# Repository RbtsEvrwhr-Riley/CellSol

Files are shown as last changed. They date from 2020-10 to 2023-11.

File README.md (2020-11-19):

# CellSol
CellSol: Long Range Solar Powered Communications Network

## Firmware

There are two firmwares for CellSol pylons: the ESP32 firmware and the Arduino Nano firmware. The former is for the ESP32 WiFi Pylon, and the latter for the Arduino Repeater Pylon.

These can be found under ESP32/esp32_wifi_bt and nano/nano_one_serial_port respectively. We will also publish binaries on the website for major releases.

See the [CellSol website](https://www.f3.to/cellsol) for more information.

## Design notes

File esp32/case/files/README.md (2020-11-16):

Bigcase has a lot of extra room for things like a battery box.

Smallcase is just the Lora32 and a lipo.

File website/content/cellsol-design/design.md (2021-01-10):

---
publishdate: 2019-11-17
lastmod: 2020-11-24
---

CellSol Design

{{< toc >}}

# Rationale

We want to provide a last-mile mesh network to allow people to communicate and access knowledge in the event of a natural, social, or other disaster. Network infrastructure is intended to be inexpensive,
locally powered, and easy to build, maintain, and replace. It should be lightweight, and as interoperable as is feasible with other network technologies and the broader Internet.

# Design

Our network design utilizes a combination of "fixed pylons" (fixed repeaters) placed mostly on the rooftops and outside of buildings and "pocket pylons" (mobile repeaters that live in peoples' pockets 
and backpacks) to allow for more "hops" across the network. The pocket pylons will also provide wifi so that any wifi-enabled device can connect to the LoRa network and send and receive messages over it.

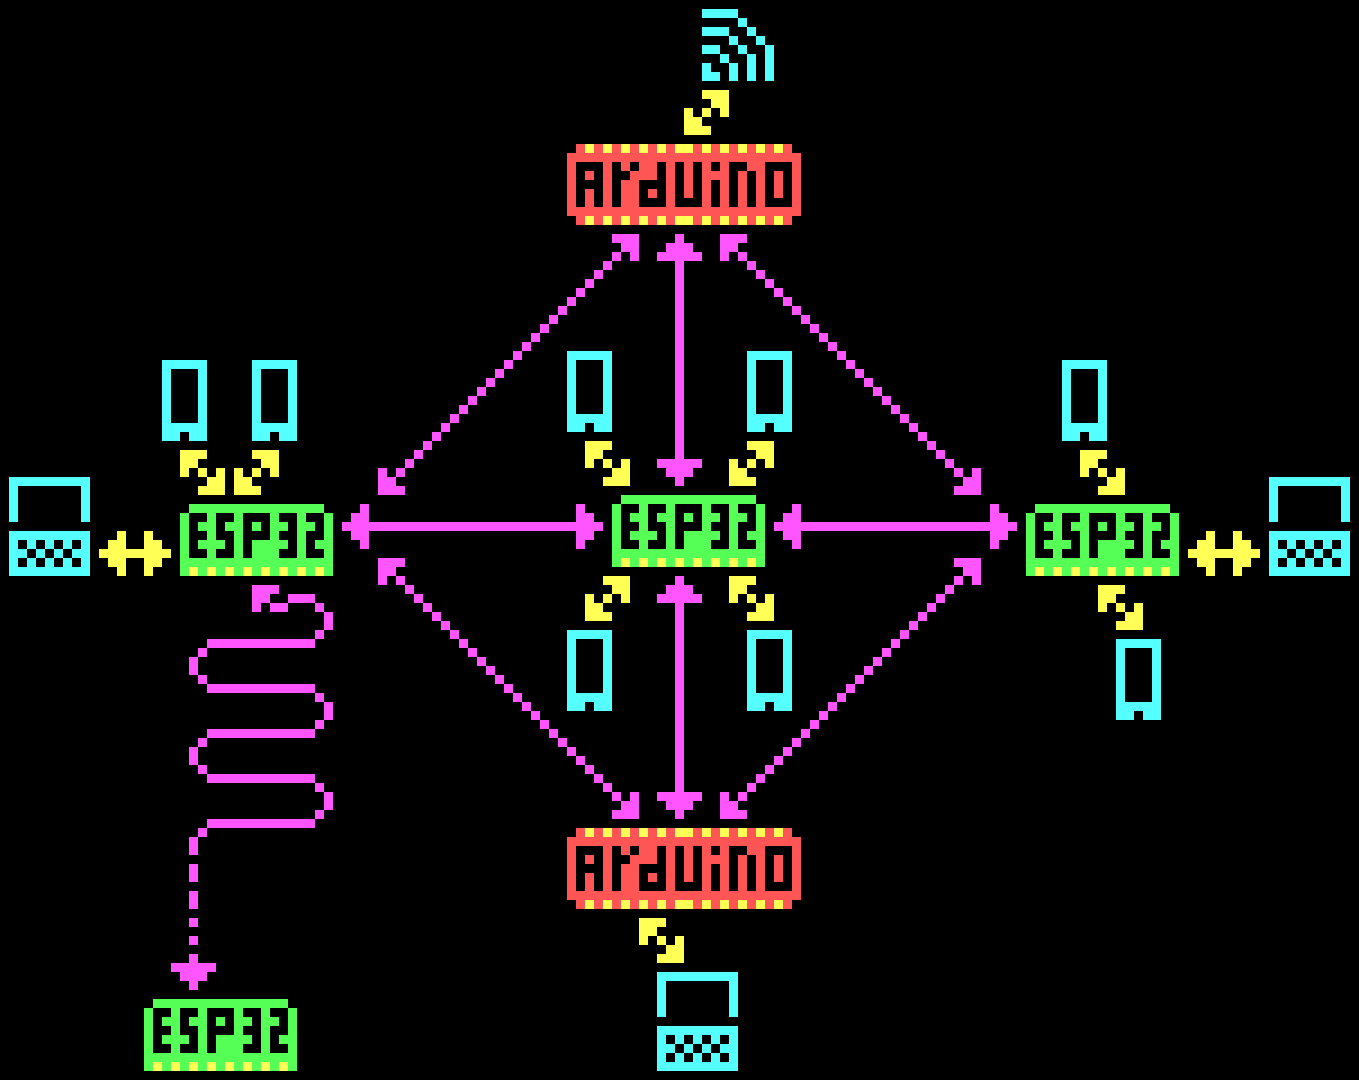
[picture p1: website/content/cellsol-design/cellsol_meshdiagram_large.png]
cellsol mesh network diagram


Our "pylons" are very simple devices that do one of three things:
1. Have a list of phones/computers that are connected to me directly; serve a web or bluetooth interface to that device to allow terminal communication
2. Send incoming messages to connected devices
3. Re-transmit incoming messages along the network

The above is true whether there ARE endpoints (phones, PCs, WiFi/Ethernet routers) connected to the node or not, so it can always be the same bit of hardware.

The "re-transmit" can be done in a basic mesh format (always re-transmit everything), and routing can be implemented in the future. Each node is capable of being a router,
if the packet format is adapted for more complex addressing in the future.

A node also provides a gateway from other devices (via BLE or WiFi) INTO and OUT OF the mesh network, and also provides routing WITHIN the mesh.

# Hardware

The RF standard we are using is [LoRa](https://www.semtech.com/lora/what-is-lora) which is an 866MHz (EU) and 915MHz (North America and most other regions) standard.

The hardware is deliberately as simple as possible so that it can be made out of readily available parts in the field. The most specialized components are for the radio - the Semtech Sx1276 and a 915MHz
antenna. That said, any LoRa chip will work, and monopole antennas can be made from short lengths of wire. See our [antennas page](../cellsol-equipment/antennas/).

The [Heltec Lora32](https://heltec.org/project/wifi-lora-32/) and Arduino Nano(https://www.arduino.cc/) are chosen for microcontrollers, due to their simplicity, with the LoRa32 being a fully integrated out-of-the-box LoRa device, so no soldering or significant setup is needed.

## Hardware Philosophy

For the different types of devices, identical hardware is used for the repeater/transmitter parts, whether you are making a WiFi pocket pylon, or a repeater, or a fixed pylon to place on top of a building,
using an ESP32, Arduino, or even a future design with a more powerful computer. The power systems are also designed to scale in the same way, with the same power supply options being interchangeable across the whole architecture.

Any device on the CellSol network is able to receive and rebroadcast messages.

The overall design is intentionally flexible so that users can design their own pylons and connect up to the devices shown here.

## WiFi Pylons 

[WiFi pylons](../cellsol-equipment/esp32), or "pocket pylons", are designed to be endpoints that connect to existing WiFi networks or devices. They can act as access points for wireless clients, or act as a client and connect to an
existing WiFi network, providing CellSol connectivity to all devices on that network. These use the Heltec Lora32 board at their core. These will serve a bulletin-board style chat application via http,
allowing any device with a web browser or ability to send GET requests to be able to talk to the rest of the mesh network.

## Repeater Pylons

[Repeater pylons](../cellsol-equipment/arduino) are a lower cost device that is designed to be a network extender, without providing web endpoint functionality. Bluetooth connectivity can be built onto
these, so they can also act as an endpoint for a single device, talking via Bluetooh serial port. These are designed around an Arduino and the Sx1276, and can be built for very low cost if done in large
volume runs. [Robots Everywhere](https://www.robots-everywhere.com) will be developing a kit for this model of pylon.

## Power requirements - Using a Solar Panel

Although users will want a battery connected to both pocket and fixed pylon repeaters, the battery will quickly run out if it is not supplemented by a solar panel that recharges the battery during the day. For this reason, we have integrated a solar panel into the design.

Note that, for the pocket pylons, it is more likely that you will want to use an additional battery or two to keep your pylon going over the course of the day, rather then depend on a solar panel being able to recharge it successfully while you are walking around. For fixed pylons however, especially those living on roof tops, a 5v solar panel will do quite nicely at keeping the battery charged.

These "pocket pylons" that we are building are able to use a 5v solar panel as-is. (5.6v is also within tolerances).

Remember to plug in your batteries and let them charge overnight the night before you assemble your repeaters. This will ensure that it's charged up as much as possible.

The way this works, is by placing the battery in-between the esp32 module and the solar panel, allowing the solar panel to keep the battery charged.

Note: Neither the ESP32 nor the Arduino is able to be powered directly from the panel, because solar panels don't collect at a constant voltage. So, if you purchased say, a 5 watt solar panel, it's really going to be collecting at 4.5 watts on some days and 5.6 watts on other days, but the devices that need to be powered require a consistent 5 watt stream.

# Software

We want to stay very light on software, focusing primarily on providing text over serial. End-to-end encryption can be handled client side by any specialized clients that want to use it, same for
compression. WiFi pylons will serve a simple web chat application, allowing for communication between users.

This is all in the future; the current software is a simple APK for Android phones to connect to Bluetooth-enabled Repeater Pylons. To communicate with
the WiFi Pylons, simply connect to their web interface, which is built into the firmware.

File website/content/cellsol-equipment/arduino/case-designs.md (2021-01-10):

---
publishdate: 2019-11-17
lastmod: 2020-11-24
---

Case designs for the Arduino Repeater Pylon are a work in progress.

https://www.thingiverse.com/thing:4660194 - This is our current case design. It has room for a small battery, and exposes the USB port.

These are not very weather resistant; we recommend using them for pocket pylons, or for indoor use, and applying a gasket and transparent screen protector film on the
exposed ports. Layer sealant, such as silicone paint or epoxy, may also help the weather resistance of this case. We recommend waterproof project boxes for outdoor use.

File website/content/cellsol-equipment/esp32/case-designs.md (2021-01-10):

---
publishdate: 2019-11-17
lastmod: 2020-11-24
---

We currently have two case designs for the ESP32 WiFi Pylon developed.

These are not very weather resistant; we recommend using them for pocket pylons, or for indoor use, and applying a gasket and transparent screen protector film on the
exposed ports. Layer sealant, such as silicone paint or epoxy, may also help the weather resistance of this case. We recommend waterproof project boxes for outdoor use.

https://www.thingiverse.com/thing:4660205 - Small case for just the LoRa32 and a battery

https://www.thingiverse.com/thing:4660207 - Large case that can take a bigger battery box, as well as have some room for instruments or other stuff

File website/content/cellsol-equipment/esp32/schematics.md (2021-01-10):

---
publishdate: 2019-11-17
lastmod: 2020-11-24
---

Here is a basic schematic for how to wire up the ESP32 Wifi Pylon using both a USB Power Bank and without.

If you are using a USB Power Bank, the battery can also be omitted if you choose.

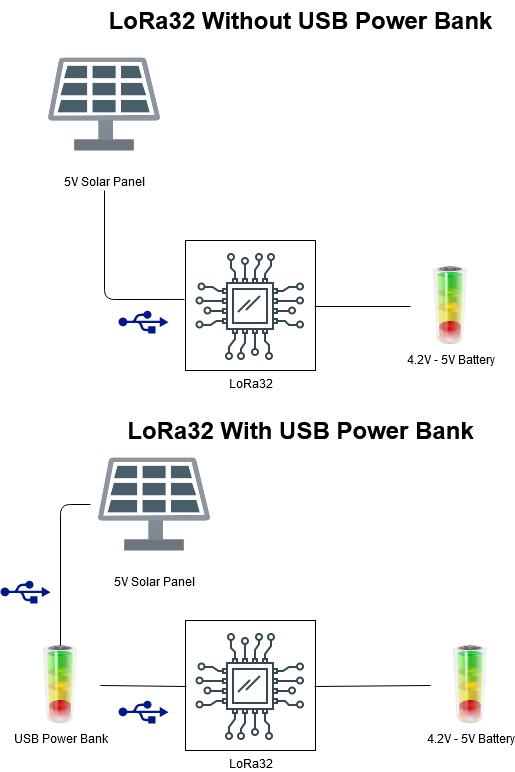
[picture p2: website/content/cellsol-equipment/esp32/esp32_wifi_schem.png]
Schematic of Wiring a Lora32 Into a CellSol Wifi Pylon


For more information, look at the [Lora32 Website](https://heltec.org/project/wifi-lora-32/) for documentation and datasheets.

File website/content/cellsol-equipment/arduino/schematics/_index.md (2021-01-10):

---
publishdate: 2019-11-17
lastmod: 2020-11-24
---

Full schematics and board layout files will be available on our GitHub page when the project is public.

<br />This work is licensed under a <a rel="license" href="http://creativecommons.org/licenses/by-nc-sa/4.0/">Creative Commons Attribution-NonCommercial-ShareAlike 4.0 International License</a>.

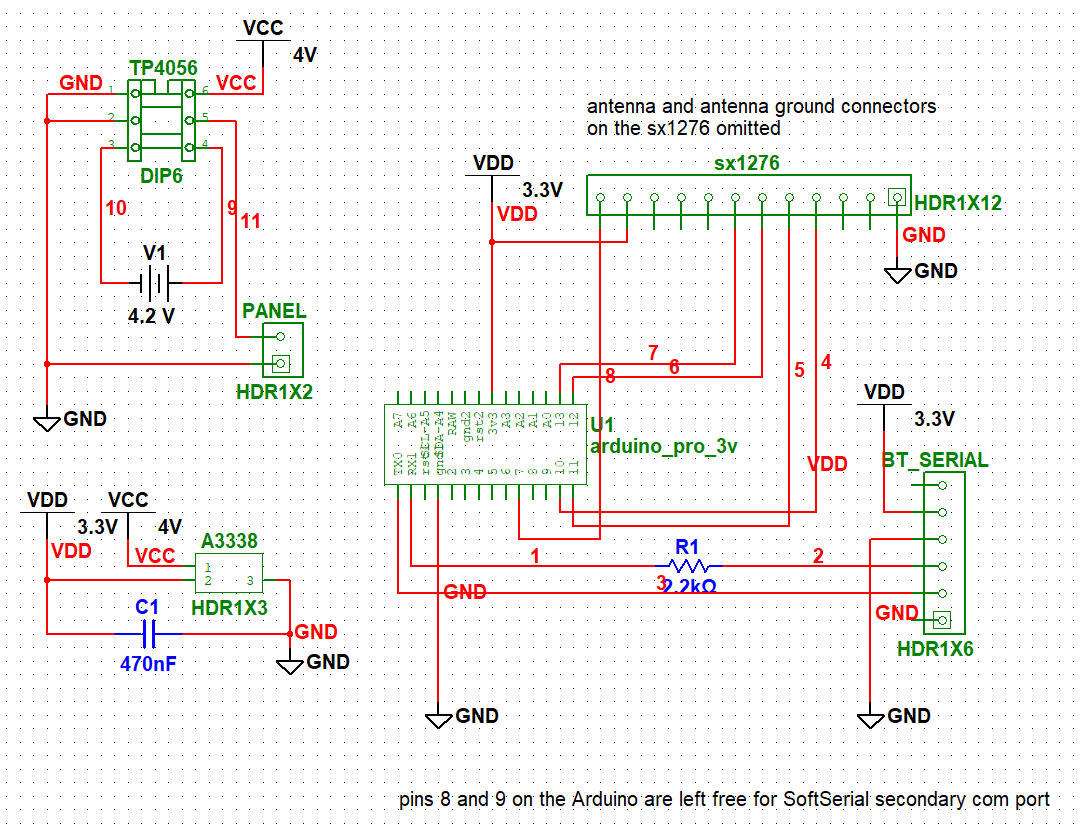
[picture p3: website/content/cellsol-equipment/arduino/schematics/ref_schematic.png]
Schematic for CellSol Arduino Repeater Pylon


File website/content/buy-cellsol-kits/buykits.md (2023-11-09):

---
title: Buy CellSol Kits
publishdate: 2021-01-11
lastmod: 2021-01-11
---

We aim to make it easy for you to build your own CellSol pylons and truly own your infrastructure. If you would like to purchase fully assembled or partially assembled kits, you can support the project by
purchasing them directly from Robots Everywhere. Head over to their [product page](https://www.robots-everywhere.com/store/cellsol-pylons-kits/) and choose your preferred pylon type. Robots Everywhere has done the engineering
and promotion work for CellSol, so by buying kits from them, you are supporting their contribution to the project.

# Compatible Equipment

You can search for the following boards on your favorite electronics retailer website.  You can then download the appropriate firmware from here, and flash it on the board.

* Heltec Lora32V2 ESP32 board
* Heltec Lora32V1 ESP32 board
* TTGO/LILYGO T-Beam
* TTGO/LILYGO ESP32 LoRa Dev Board
* BSFRANCE Feather32u4 LoRa board
* Adafruit Feather M0

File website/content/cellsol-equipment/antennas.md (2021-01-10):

---
title: Antennas
publishdate: 2019-11-17
lastmod: 2020-11-24
---

{{< toc >}}

# Antenna Concepts

If you're not familiar with antenna design, [this site](http://www.antenna-theory.com/) can be a good resource. You don't need to know any antenna theory to choose an antenna for your pylon,
but it's useful knowledge!

# Small Antennas (<10cm)

900MHz wifi antennas will often serve "okay" at both 866MHz for european LoRa and 915MHz for North American, but the performance in either case will be less than ideal.

Most of our data for LoRa antennas have come from the results of Mark Zachmann on his blog here: https://medium.com/home-wireless/testing-lora-antennas-at-915mhz-6d6b41ac8f1d

We have only been the 85mm copper wire and stock LoRa32 antennas ourselves so far. Please [reach out to us](mailto:cellsol@robots-everywhere.com) if you are testing other antennas! We would love
to hear from you, and see your network implementations.

## With a Ground Plane (Monopoles)

Monopole antennas will perform better than dipoles, but need a solid connection to earth ground to work effectively. For a static pylon, such as a repeater or a home
ESP32 WiFi pylon, you may have easy access to earth ground. REMEMBER: when connecting your pylon to a grounding stake, do not use a wire that is a multiple of 85mm in length,
it will resonate on the frequency you are trying to receive, making your ground less effective.

For a short-wire monopole antenna, 85mm of copper wire will work; our tests used standard 20 gauge stranded wire from our shop spools. 

REMINDER: the wire leading to the antenna is also an antenna, ensure it is either too short or more likely too long to resonate at 915MHz. If the antenna is near 8cm in length, it will reasonate, causing
a lot of noise, possibly disabling the connection entirely.

Linx makes a 915MHz monopole as well; https://linxtechnologies.com/wp/product/pw-series-antennas/ along with other manufacturers.

### 3D Printed Antenna Stand & Cutter

Kay designed a 3D printable antenna stand that also doubles as a ruler to measure the right length of wire to use for the best reception.

Our LoRa network uses 915MHz as its frequency. Different frequencies will use different lengths of wire on our antenna ruler/stand. 
You can use the ruler to measure exactly the right length of wire for your antenna, before you cut it.

1. Print out our antennae stand/ruler for frequency wire length tool

2. Use the tool to measure the desired length of wire for your antennae, and cut it

3. Slide the wire through the antennae stand

4. Connect the antennae to your LoRa repeater or Wifi Router

Be careful where you place your repeater, as the antenna itself can shadow the solar panel and interfere with it's ability to capture power from the sun.

## Without a Ground Plane (Dipoles)

When you do not have a ground plane you should be using a dipole antenna. The stock antenna on the Heltec and TTGO LoRa32s (and many other cheap LoRa antennas) are
actually WiFi antennas - tuned at 915MHz - with a broad frequency range. The 866MHz version is the same as the North American 915MHz one, so all models work in all regions.

One example of a high performance whip dipole for LoRa at 915MHz is here. https://linxtechnologies.com/wp/wp-content/uploads/ant-916-cw-hw.pdf They also make an 868MHz version.

If you are on the side of the building, use a directional reflector (aluminum) to improve performance, though the concrete of the building will do a fairly good job. Glass won't.

From our own calculations, large loop antennas are not worth it for 915MHz applications - diminishing returns on gain begin at very small loop diamters, around 8cm. We will continue further testing as the project goes on.

For a very tiny pocket node, small chip antennas exist:

https://www.mouser.ca/ProductDetail/Yageo/ANT1204F005R0915A?qs=gt1LBUVyoHnk%2Fihas5MohQ%3D%3D

https://linxtechnologies.com/wp/product/915-usp410-lpwa-antenna/ 

https://www.youtube.com/watch?v=eQEmFlMW50o This guide has some information on making your own LoRa dipole antennas using copper welding wire.

Otherwise, the stock dipole on the LoRa32 performs better than most 900MHz antennas at 916MHz.

# Large Antennas

We don't have any big-antenna deployments yet - we're working on securing funding to build some large pylons around the San Francisco Bay Area at the moment.

Depending on the region you are operating in and the regulation of the 915MHz or 866MHz band, the operation large transmitters may not be permitted. You may be
required to reduce the power of your transmission by modifying the firmware, or use a smaller antenna.

If you want to help, [contact us](mailto:cellsol@robots-everywhere.com)

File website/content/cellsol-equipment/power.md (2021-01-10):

---
title: Power Supplies
publishdate: 2019-11-17
lastmod: 2020-11-24
---

# POWERING THE NODE

The node is designed to be very tolerant when it comes to input power, so that it can be run in a variety of emergency situations.

The node takes 4 to 6.5V power. You can provide this from USB, a solar panel, or a number of other sources such as:

* USB power bank. It has to be plugged into the USB power input port. You can break down a USB cable to do this and connect the red and black wires.

* 6V lead-acid battery, connected to the USB power input port.

* 6V bike dynamo. Using a diode in series with the node power input is recommended (1N4004 or similar). If you use this, the node MUST have a secondary battery.

* 3 alkaline cells (AAA to D cells) in series. Important: these must be NON-rechargeable!

* Anything that outputs USB (car adapter, wall plug, spare USB port on a wifi router, 10 pounds of potatos connected in series, etc)

* USB hand crank. If you use this, the node MUST have a secondary battery.

## BATTERY TYPES FOR THE NODE

You will need a 3.5 to 4 volt battery to keep the node operating overnight (or when its primary power input is off). The node has been designed to be compatible with a variety of battery typologies. Any one of these will work. If you want to use more than one battery, connect them in parallel. In this case you may NOT mix battery types!

* None. The node has a two stage voltage regulator (switching to 3.7v and linear to 3.3v) and a filter capacitor, so it's safe to run it without a battery if it has continuous power coming in. The exception, as noted above, is if you have a USB hand crank or bike dynamo.

* 3.7V LiPo battery. Any type is fine (18650, old quadcopter battery, etc). If it has no protection circuit, it's fine.

* 3.6V lithium battery. Any type is fine (Old cell phone battery, etc).

* 3 rechargeable cells (AAA to D cells) in series. Important: these must be rechargeable!

* 4V lead-acid battery, connected to the battery terminals. Optionally, add a 47 ohm resistor between solar in+ and battery in+. (Note that this also applies to a 6V lead-acid battery that has a dead cell: the node uses little continuous power, so this is safe to do! Good for emergencies.)

* A supercapacitor (if you want to show off) A 5V supercap will work just fine as if it was a battery. Warning: A 3.3V supercap will NOT! If you have one of those, connect it between 3V3 and GND.

* If all you have available is a 3.3V LiFePo4 cell, you can still use it if you connect a capacitor to the battery terminals, and connect the battery itself to the 3V3 and GND terminals on the Arduino. Connect a 47 ohm resistor between B+ on the battery charger board and 3V3. This one is at your own risk and the battery will never get a full charge, but it will work in an emergency.

Connect the battery to the B+ and B- terminals on the node. RESPECT POLARITIES. The node does NOT have reverse polarity protection in its current incarnation. If a battery has other connectors other than + or - you should be able to just ignore them (this is common with cell phone batteries).

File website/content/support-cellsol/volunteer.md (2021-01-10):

---
publishdate: 2019-11-05
lastmod: 2020-11-24
---
Currently the best way to volunteer for the CellSol project is to [contact the project admins](mailto:cellsol@robots-everywhere.com) by email. Please indicate how you would like
to contribute to the project, and your level of experience in relevant skills.

We look forward to hearing from you!

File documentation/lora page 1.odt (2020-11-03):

#### CellSol – Cellular-Solar Network for Resilient Communications

#### Updated October 14, 2020

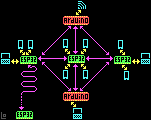
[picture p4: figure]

Figure 1: Network topology for a LoRa Network LoRa: Low Frequency Radio Network

#### Index:

- Introduction to this project and what we are trying to build
- System Requirements for our LoRa Network
- Part lists and Software for our "Pylons": "Pocket Pylons" (pocket-sized repeaters that you can carry around with you) and fixed "Pylons" (fixed repeaters that are used to carry the LoRa signal longer distances and act as "bridges" between the wifi-enabled repeaters that anyone with a phone can access).
  - Option 1 -esp 32 (LoRa Repeater that is wifi-enabled)(more expensive, but no soldering required)
  - Option 2 (cheaper using arduinos but soldering required - also we've designed a part that will make it easier to add bluetooth and solar power)
    - Kits from Robots Everywhere with everything needed for the Arduino option (coming soon)
- Our LoRa software (for our "pocket node" prototypes & potentially other LoRa-compatible hardware)
  - Transceiver Software
  - Wifi app with texting Software
  - Software Licensing
  - Captive Portal Implementation
- Antennaes
- Software Libraries
- Next Steps
  - Word compression considerations
- Additional Features for next version
- Definitions of some basic terms to help people new to the project understand what we are doing
- LoRa References
  - Tutorials
  - Standards

Coming soon:

- Other hardware that might work with LoRa
- LoRa Install Guide
- LoRa Troubleshooting Info
- Tech Support

#### Introduction

Problem:

What if the internet and cell phone towers went down for more than a few hours - or during an emergency situation when no communication for several hours could mean lives lost?

Proposed Solution:

To build a LoRa (Low Frequency Radio) network using a combination of "pocket pylons" (repeaters that are carried in peoples' pockets or, with a larger antenna, in backpacks) and "fixed pylons" (fixed repeaters that forward the signal).

The pocket pylons (built on ESP32 microcontrollers) will have wifi access points on them for any wifi-enabled device to connect to. The fixed pylons are Arduino based and only have the ability to connect via Bluetooth to one device at a time, and to the network over LoRa.

The proposed work:

1. We will build an "Emergency LoRa Network."
2. We have written software to enable users to send text messages, either one to one or one to everyone on the network, over their cell phones.
3. A LoRa network is a "low power radio network" (using the LoRa protocol (https://en.wikipedia.org/wiki/LoRa)).
4. We will design our devices to be easily rechargeable from 5v solar panels.
5. To enable our network to function optimally with large crowds in a setting with lots of building, we will create mobile "pocket pylons" - for which we have just built two working prototypes.

#### System Requirements for LoRa network

Our network design utilizes a combination of "fixed pylons" (fixed repeaters) placed mostly on the roofs and outside of buildings and "pocket pylons" (mobile repeaters that live in peoples' pockets and backpacks) to allow for more “hops” across the network.

The pocket pylons will also provide wifi so that any wifi-enabled device can connect to the LoRa network and send and receive messages over it.

Power requirements - Using a Solar panel to recharge the battery

Although we will connect a battery to our pocket and fixed pylon repeaters, the battery will quickly run out if it is not supplemented by a solar panel that recharges the battery during the day. For this reason, we have integrated a solar panel into the design.

Note that, for the pocket pylons, it is more likely that you will want to use an additional battery or two to keep your pylon going over the course of the day, rather then depend on a solar panel being able to recharge it successfully while you are walking around. For fixed pylons however, especially those living on roof tops, a 5v solar panel will do quite nicely at keeping the battery charged.

These "pocket pylons" that we are building are able to use a 5v solar panel as-is. (5.6v is also within tolerances)

Remember to plug in your batteries and let them charge overnight the night before you assemble your repeaters. This will ensure that it's charged up as much as possible.

The way this works, is by placing the battery in-between the esp32 module and the solar panel, allowing the solar panel to keep the battery charged.

Note: Neither the ESP32 nor the Arduino is able to be powered directly from the panel, because solar panels don't collect at a constant voltage. So, if you purchased say, a 5 watt solar panel, it's really going to be collecting at 4.5 watts on some days and 5.6 watts on other days, but the devices that need to be powered require a consistent 5 watt stream.

Prototypes

We have created two different prototypes. A more expensive option that does not require any soldering, and an arduino-based model that requires soldering and, ideally, the use of a special circuitboard that we are designing and potentially mass-producing, to lower the price and make the option easier to implement. (Kits coming soon)

Our "pylons" are very simple devices that do one of three things:

1. I have a list of phones/computers that are connected to me directly
2. I have received a message that is for one of these: i will send it to that device
3. I have received a message that is not for one of these: i'm going to re-transmit it, so that it may get where it has to go"

The above is true whether there ARE endpoints (phones, pc's) connected to the node or not, so it can always be the same bit of hardware.

The "I'm going to re-transmit" part can be done stupidly (everyone spams out what they received as long as they don't do it more than once) or smart (use timestamp or gps or both to make a good guess of where it has to go).

In a mesh network like we are describing, each node is also a router, and re-transmitting is handled via routing.

A node also provides a gateway from other devices (via BLE or WiFi) INTO and OUT OF the mesh network, and also provides routing WITHIN the mesh.

Part lists and Software for our Prototypes:
Part lists and Software for our "Pylons":
"Pocket Pylons" (pocket-sized repeaters that you can carry around with you) and "Fixed Pylons" (fixed repeaters that are used to carry the LoRa signal longer distances and act as "bridges" between the wifi-enabled repeaters that anyone with a phone can access).

Note that for these options below, identical hardware is used for the repeater/transmitter parts - whether you are making a "pocket pylon" - that uses a smaller antenna, a "backpack pylon" with a larger antenna, or a "fixed pylon"(yeah, we couldn't resist) - that you wish to place on top of a building or somewhere else outside, for better reception and range.

##### Option 1 - ESP 32 (LoRa Repeater that is wifi-enabled)

Hardware:

915MHz ESP32 LoRa 0.96 OLED Development Board SX1276 WiFi Bluetooth Transceiver Module + LoRa Antenna +JST Connector for Arduino LoraWan IOT Internet of Thing (Pack of 2) https://www.amazon.com/gp/product/B086ZG25DZ/ref=ppx_yo_dt_b_asin_title_o03_s00?ie=UTF8&psc=1

ESP32 LoRa 32 (V2), ESP32 Development Board WIFI Bluetooth LoRa Dual Core 240MHz CP2102 with 0.96inch OLED Display included 868/915MHZ Antenna for Smart Cities, Smart Farms, Smart Home, and IoT Makers https://www.amazon.com/gp/product/B076MSLFC9/ref=ppx_yo_dt_b_asin_title_o00_s00?ie=UTF8&psc=1

Software:

A zip file with software for either the esp32 or arduino models is available here:

#### Kits from Robots Everywhere with everything needed for the Arduino option

COMING SOON

##### Option 2 - Arduino (LoRa Repeater w single bluetooth connection)

The same basic repeater - that literally uses the same software - but this one requires a bit of soldering, and is made using an inexpensive arduino and a semtech chip.

The nice thing about this particular arduino is that it costs $1 if you buy more than 50.

We are designing and potentially mass producing a larger, pre-made circuit, for use with the arduino options - will make it easier for people to put together.

#### Our LoRa software (for our "pocket pylon" prototypes & potentially other LoRa-compatible hardware)

#### Transceiver software

The Transceiver code is packaged in with everything else on our github here:

This is software for a very basic transceiver for either a LoRa heltec module with a display, or an arduino (without a display).

Basically it acts like an old timey XBee series 1 and displays the last packet it got. So, it should be good for debugging /packet sniffing.

Interestingly it can be a wifi gateway (https://www.aaronswartzday.org/lorasetup/#gateway).

Picture of Option2:

#### Wifi App for Texting Software

This software interconnects between a com port (or more than one), a really derpy website that shows the last 10 messages and lets you input one (over LoRa). The cool thing is that it just works (tm) - even on old cell phones. The site even loads on a G1 phone from 2009

##### Link to our software, which includes a wifi app with texting software, on github here:

This firmware, written by Matteo Borri and Riley August, should work on most existing LoRa modules. (We suggest using a LoRa 32 heltec modules (https://www.aaronswartzday.org/lora/#option1))

This software works for up to 8 wifi-enabled devices at a time.

Here's a little model of what we are building:

----fones
------gateway
--------repeater
--------repeater
--------repeater
------gateway
----fones

[caption id="attachment_3043" align="aligncenter" width="897"] These "pocket pylons" that we are building are able to use a 5v solar panel as-is. (5.6v is also within tolerances)[/caption]

[caption id="attachment_3044" align="aligncenter" width="474"] Above: CellSol in action.
This basically bridges LoRa, wifi (via a derpy webpage although i guess we can do telnet/ssh) and the uarts on the controller. Wiring is just 5v to panel, with the zener diode across the leads.
Note that the internal resistance of the panel is sufficient to prevent fuckups.
Note that the battery in the above photo was harvested from a dead ipad. We added wifi using some 5.1 volt zener diodes.[/caption]

[caption id="attachment_3045" align="aligncenter" width="474"] Above: This is still just super basic - yet already sufficient for coordinating between two areas.[/caption]

#### Option 2: Arduino-based (requires soldering)

[caption id="attachment_3049" align="aligncenter" width="964"] arduino pro mini 8mhz 3.3v operation
(uint8_t NSSPin = 10, uint8_t NRESETPin = 9
nss = pin10 (can be moved)
reset = pin9 (can be move)
sck = pin13 (cannot be moved)
mosi = pin11 (no)
miso = pin12 (no)[/caption]

[caption id="attachment_3050" align="aligncenter" width="474"] Very simple circuit - for those who can solder. See below for the circuit we are designing to make it even easier to solder :)[/caption]

Bluetooth adapters (for the arduino boards)

[caption id="attachment_3051" align="aligncenter" width="474"] Blue tooth 3.0 adapters - 10 of them :) (for arduino boards)[/caption][caption id="attachment_3052" align="aligncenter" width="474"] Blue tooth 3.0 adapters - 10 of them :) (for arduino boards)[/caption]

Bluetooth modules that are easy to hook up to the arduino: HC05

[caption id="attachment_3054" align="aligncenter" width="782"] Connect the HC05 to pins 0 and 1 and it will work out of the box.[/caption][caption id="attachment_3055" align="aligncenter" width="474"] This is the super basic version of the repeater as you see there's only four points of shoulder that are hard to do and even that one took a few minutes.[/caption][caption id="attachment_3057" align="aligncenter" width="474"] Pretty much the most basic repeater possible[/caption]

[caption id="attachment_3059" align="aligncenter" width="474"] A 5v solar panel with antenna.[/caption][caption id="attachment_3060" align="aligncenter" width="959"] An arduino with bluetooth module soldered on and circuit soldered on for plugging into a solar panel. Note that the bluetooth functionality of these repeaters can be dismantled if desired by "plugging" the bluetooth connector, if desired. [?Note to make sure this "plugging" is explained correctly?][/caption]

#### Licensing

The RadioHead library uses GPL 3.0, which requires us to make everything we use it with also available under GPL 3.0.

#### Captive Portal Implementation

We are building capabilities into our little wifi access points so that a user will automatically redirect to our desired homepage upon accessing the network.

There are several different ways that this can be accomplished (and we'd love to hear more). So far we have:

1. There's an HTTP redirect Usually used when people are already using a well known URL that you don't want to change, rather than a user that is firing up their client for the first time on the network, but still deserves to be on the list until we rule it out.
2. User's can be redirected to our desired IP address at the router level. This is how most "Captive Portals" as these are known as, are implemented. A "captive portal" is what you deal with when you access any corporate network - for instance, at a hotel, the airport, or when you're somewhere like whole foods - it makes you login or give a code or do whatever so you will be allowed to access anything else on the network.For us, we're not trying to limit what people can access, since there's nothing but our stuff on this network - although that might be a useful tool in the future, if resources are limited and a certain page accessible on the LoRa network is hogging all the bandwidth :)For us, we're just trying to make it easy for new users to find the only page that exists, by taking them there automatically when they fire up their browser.

#### Antenna Info

Matteo has created a 3D printable antennae stand (need link to file here) that also doubles as a ruler for measuring just the right length of wire to use for the best reception of a specific frequency.

Link to 3D printer file for the antennae stand here

photo

idea is that you use the 3d printed part both as the whip antenna holder and as a meaasure to cut the antenna wire with

Our LoRa network uses 915MZ as its frequency. Different frequencies will use different lengths of wire on our antennae ruler/stand. You can use the ruler to measure exactly the right length of wire for your antennae, before you cut it. (You can use this tool to make a better antennae for your wifi router too this way.)

1) Print out our antennae stand/ruler for frequency wire length tool

2) Use the tool to measure the desired length of wire for your antennae, and cut it

3) Slide the wire through the antennae stand

4) Connect the antennae to your LoRa repeater or Wifi Router

Be careful where you place your repeater, as the antennae itself can shadow the solar panel and interfere with it's ability to capture power from the sun.

This antennae is supposed to work for longer distances, like 25 miles - and our software is already configured to work with it: https://www.digikey.com/en/products/detail/digi/XBP9B-XCST-001/3482817

(https://www.aaronswartzday.org/givemelora/#antennaes)

More info about antennae here:

Antennas

http://www.shopantenas.com.br/antena-movel-uhf-5-8...

Antenna mount:

http://www.shopantenas.com.br/suporte-magnetico-preto-p--antena-movel/p

Note: You generally want to use as big of an an antenna as is possible while still being practical to carry around (in the case of a pocket pylon).

For the fixed "pylon" repeaters, there is a concern that the antennae aren't so big as to draw too much attention - as is the reason for keeping the size of the solar panels used as small as possible. (So they don't get stolen.)

#### Next Steps

1) make a basic repeater with just an arduino and a semtech chip
(get a POS $1 arduino to do repeater things) Note: ideally, these will be able to be made cheaper than our original prototype (see pics above) - and, most importantly, will use a lot less power.

2) Getting an antenna reasonably high up where Matteo is - in San Rafael - (~1.5-2m above building) - so we can try some long range tests.

#### Additional Features for next version

Re: encryption

Sure. Eventually, it would be nice to have some encryption available for sensitive messages. Right now, we think it would be more useful to be able to say "I'm here help" over an open network than to have no options at all.

re: bulletin boards

Since we are dealing with slow model speeds, someone suggested implementing a bulletin board system of sorts. So Matteo build one. This "bulletin board" is just a little website that has only has 10 message slots but there can be up to 255.

Why a bulletin board system? Because LoRa is as slow as some of the earliest modem speeds - 9600 baud or lower even - so why not go back to the types of communication platforms that were used in the 90's when bandwidth was going that slow.

#### Software Libraries (we used to write our node software)

RadioHead Packet Radio library for embedded microprocessors
http://www.airspayce.com/mikem/arduino/RadioHead/
This is the RadioHead Packet Radio library for embedded microprocessors. It provides a complete object-oriented library for sending and receiving packetized messages via a variety of common data radios and other transports on a range of embedded microprocessors.

The version of the package that this documentation refers to can be downloaded from http://www.airspayce.com/mikem/arduino/RadioHead/RadioHead-1.107.zip You can find the latest version of the documentation at http://www.airspayce.com/mikem/arduino/RadioHead

#### Definitions of some basic terms to help people new to the project understand what we are doing

Access point:

Gateway:

Router:

Repeater:

Wifi:

Bluetooth:

LoRa:

#### Word Compression Consideration

Why might we want word compression for our LoRa network?
The "commercial code" below is one of several methods that one can use to achieve excellent "word compression" for english words. "Word compression" is a concept that originated during the old days of telegrams and systems where you paid for every word to be transmitted. In our case, every word counts because our network bandwidth is so limited - and is literally as slow as the old dial-up modems of the 90s. (As slow as 9,600 - 12,000 baud modems)

These codes are examples of what is called "dictionary compression." An application is written in such a way that it recognizes common phrases, like "what time should we meet?" and assigns it a code that will necessitate transmitting fewer characters.

The way it works: The application (in this case our texting app & bulletin board app) - recognizes the phrase the person has typed and then uses a shorter abbreviation to represent it - sends the code (that uses less characters) across the network - where it is decoded on the receiver's side into the original message. This is similar to the autocorrect functions that everyone is used to using on their phones.

What would creating our own codes involve?

Creating our own codes would involve determining the 32768 most common words in english - perhaps algorithmically.

Why don't we use lossless text compression then instead of codes?

Because compression not optimized for text doesn't go very far for short messages. To demonstrate this concept, one can take any one sentence typed here, save it as a text file, zip the text file, and see that it won't be much shorter.

Why are we discussing this for this project?

(This subject came up because there's a big emphasis in sending as few bytes as possible on the LoRa discussion forums.)

Let's say that we take the most common 32768 words in the english language (the other 32767 are pairs of ASCII characters that disallow control characters, so losing one bit out of 16 i not a big problem). Now each word, or even common phrase, if we want, fits two bytes. You can even do a bit of cleanup so that "how are you" and "how r u" and so on map to the same thing, and are printed "how are you" at the receiving end unless tagged "verbatim." [? (Note: we haven't discussed tagging messages? let's! :) ?]

Note: This is done phone/pc side where you have a lot of hard disk space for a dictionary and a lot of cpu power for realtime substitution.

Note: Interestingly, you can even XOR the -dictionary- with a crypto key for private messaging, and if you swap those often enough, that's your encryption solution. (Not unbeatable of course, but since it can be of arbitrary length, you could even have a one time pad, which IS unbeatable by definition). This type of "encryption" won't slow things down as much, as it's just a XOR operation that you do once on the dictionary. So, not unbeatable, but decent. And not super secure in that it requires a shared key, but eh.

Lisa thinks it sounds like a project in itself, but Matteo thinks it's not necessarily a big job, it's just a case of finding out what the most common X words in Y language are, and sorting them. Or you can just scrape a dictionary and sort it alphabetically if you are lazy.

Commercial code (communications)
https://en.wikipedia.org/wiki/Commercial_code_(communications)
"In telecommunication, a commercial code is a code once used to save on cablegram costs.[1] Telegraph (and telex) charged per word sent, so companies which sent large volumes of telegrams developed codes to save money on tolls."

For Later:

#### Other LoRa Hardware

Hardware we think might work, if we create a LoRa gateway for it

The Ark
https://github.com/thearkadia/The_Ark/blob/master/README.md

LORA1276|FCC|CE|868 915MHz|100mW|Lora module|wireless RF module| long range transceiver module
https://www.nicerf.com/product_146_136.html

#### LoRa Install Guide

Installing our LoRa software (https://github.com/AaronSwartzDay-SSP/LoRa) on your esp32

Arduino firmware install instructions (https://www.aaronswartzday.org/lorasetup/#arduinofirmware)

(https://www.aaronswartzday.org/lorasetup)

The esp32 does not have a toolkit, but you can use the arduino toolkit with a plugin module to get it to work on the esp32. (add links)

1) On your computer, install the arduino toolkit, and the esp 32 plugin that works with the arduino toolkit.

2) Use the toolkit to put our LoRa software on your device.

3) Take any web-enabled device and fire up a browser type in the IP address 192.168.x.1

4) Type in your message in the form field and click "send" - to send a message to everyone on the network that also has the page loaded.

5) Users can refresh the page to see new messages.

The page will save and display the last 10 messages sent. (We are working on having a second page that displays the last 100 messages.)

#### Troubleshooting Info

Troubleshooting Info here

#### Tech Support

contact: cellsol@robots-everywhere.com

HTML for LoRa Page:

<h4>Updated October 14, 2020</h4>

<h4>A map of the network design (Network Topography)</h4>

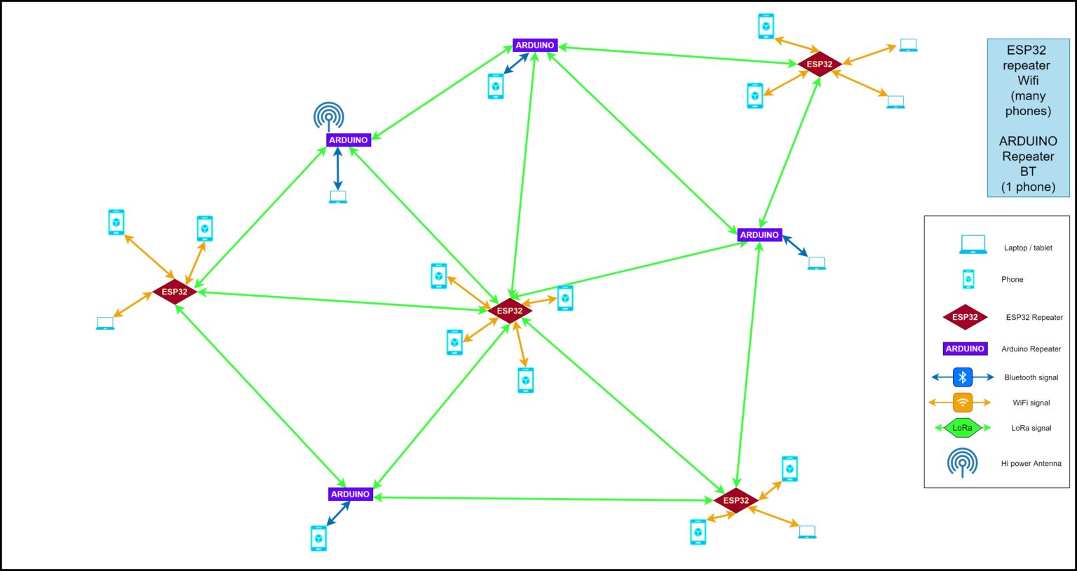
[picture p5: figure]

(Draft language: In the case of our San Rafael to Richmond connection, a high power antenna will probably be used.)

Map above shows how we are using arduinos to bridge the LoRa signal between the esp32 modules. Ideally, there will be a bit of overlap between the ranges of the esp32s, to enable anyone with a wifi enabled device to access our text messaging page.

<h4>Index:</h4>

<ul>

<li><a href="#intro">Introduction to this project and what we are trying to build</a></li>

<li><a href="#systemnetworkrequirements">System Requirements for our LoRa Network</a></li>

<li><a href="#pocketpylon">Part lists and Software for our "Pylons":

"Pocket Pylons" (pocket-sized repeaters that you can carry around with you) and fixed "Pylons" (fixed repeaters that are used to carry the LoRa signal longer distances and act as "bridges" between the wifi-enabled repeaters that anyone with a phone can access).</a>

<ul>

<li><a href="#option1">Option 1 -esp 32 (LoRa Repeater that is wifi-enabled)</a><a href="#option1">(more expensive, but no soldering required)</a></li>

<li><a href="#option2">Option 2 (cheaper using arduinos but soldering required - also we've designed a part that will make it easier to add bluetooth and solar power)</a>

<ul>

<li><a href="#kits">Kits from Robots Everywhere with everything needed for the Arduino option (coming soon)</a></li>

</ul>

</li>

</ul>

</li>

<li><a href="#software">Our LoRa software (for our "pocket node" prototypes &amp; potentially other LoRa-compatible hardware)</a>

<ul>

<li><a href="#transceiver">Transceiver Software</a></li>

<li><a href="#wifitext">Wifi app with texting Software</a></li>

<li><a href="#licensing">Software Licensing</a></li>

<li><a href="#captiveportal">Captive Portal Implementation</a></li>

</ul>

</li>

<li><a href="#antennaes">Antennaes</a></li>

<li><a href="#libraries">Software Libraries</a></li>

<li><a href="#nextsteps">Next Steps</a>

<ul>

<li><a href="#wordcompression">Word compression considerations</a></li>

</ul>

</li>

<li><a href="#additionalfeatures">Additional Features for next version</a></li>

<li><a href="#definitions">Definitions of some basic terms to help people new to the project understand what we are doing</a></li>

<li><a href="#references">LoRa References</a>

<ul>

<li><a href="#tutorials">Tutorials</a></li>

<li><a href="#standards">Standards</a></li>

</ul>

</li>

</ul>

<strong>Coming soon:</strong>

<ul>

<li><a href="#otherhardware">Other hardware that might work with LoRa</a></li>

<li><a href="#install">LoRa Install Guide</a></li>

<li><a href="#troubleshooting">LoRa Troubleshooting Info</a></li>

<li><a href="#techsupport">Tech Support</a></li>

</ul>

<h4 id="intro">Introduction</h4>

<strong>Problem:</strong>

What if the internet and cell phone towers went down for more than a few hours - or during an emergency situation when no communication for several hours could mean lives lost?

<strong>Proposed Solution:</strong>

To build a LoRa (Low Frequency Radio) network using a combination of "pocket pylons" (repeaters that are carried in peoples' pockets or, with a larger antenna, in backpacks) and "fixed pylons" (fixed repeaters that forward the signal).

The pocket pylons (esp 32s) will have wifi access points on them for any wifi-enabled device to connect to. The fixed pylons are arduino-based and only have the ability to connect via bluetooth to one device at a time.

<ol>

<li>Build an "Emergency LoRa Network."</li>

<li>Write software to enable users to send text messages, either one to one or one to everyone on the network, over their cell phones.</li>

<li>A LoRa network is a "low power radio network" (using the <strong><a href="https://en.wikipedia.org/wiki/LoRa">LoRa protocol</a></strong>).</li>

<li>We will design our devices to be easily rechargeable from 5v solar panels.</li>

<li>To enable our network to function optimally with large crowds in a setting with lots of building, we will create mobile "pocket pylons" - for which we have just built two working prototypes.</li>

</ol>

<h4 id="systemnetworkrequirements">System Requirements for LoRa network</h4>

Our network design utilizes a combination of "fixed pylons" (fixed repeaters) placed mostly on the roofs and outside of buildings and "pocket pylons" (mobile repeaters that live in peoples' pockets and backpacks) to allow for more “hops” across the network.

The pocket pylons will also provide wifi so that any wifi-enabled device can connect to the LoRa network and send and receive messages over it.

<strong>Power requirements - Using a Solar panel to recharge the battery

</strong>

Although we will connect a battery to our pocket and fixed pylon repeaters, the battery will quickly run out if it is not supplemented by a solar panel that recharges the battery during the day. For this reason, we have integrated a solar panel into the design.

Note that, for the pocket pylons, it is more likely that you will want to use an additional battery or two to keep your pylon going over the course of the day, rather then depend on a solar panel being able to recharge it successfully while you are walking around. For fixed pylons however, especially those living on roof tops, a 5v solar panel will do quite nicely at keeping the battery charged.

These "pocket pylons" that we are building are able to use a 5v solar panel as-is. (5.6v is also within tolerances)

Remember to plug in your batteries and let them charge overnight the night before you assemble your repeaters. This will ensure that it's charged up as much as possible.

The way this works, is by placing the battery in-between the esp32 module and the solar panel, allowing the solar panel to keep the battery charged.

Note: Neither the ESP32 nor the Arduino is able to be powered directly from the panel, because solar panels don't collect at a constant voltage. So, if you purchased say, a 5 watt solar panel, it's really going to be collecting at 4.5 watts on some days and 5.6 watts on other days, but the devices that need to be powered require a consistent 5 watt stream.

<strong>Prototypes</strong>

We have created two different prototypes. A more expensive option that does not require any soldering, and an arduino-based model that requires soldering and, ideally, the use of a special circuitboard that we are designing and potentially mass-producing, to lower the price and make the option easier to implement.<em> (Kits coming soon)</em>

Our "pylons" are very simple devices that do one of three things:

1. I have a list of phones/computers that are connected to me directly

2. I have received a message that is for one of these: i will send it to that device

3. I have received a message that is not for one of these: i'm going to re-transmit it, so that it may get where it has to go"

The above is true whether there ARE endpoints (phones, pc's) connected to the node or not, so it can always be the same bit of hardware.

The "I'm going to re-transmit" part can be done stupidly (everyone spams out what they received as long as they don't do it more than once) or smart (use timestamp or gps or both to make a good guess of where it has to go).

In a mesh network like we are describing, each node is also a router, and re-transmitting is handled via routing.

A node also provides a gateway from other devices (via BLE or WiFi) INTO and OUT OF the mesh network, and also provides routing WITHIN the mesh.

&nbsp;

<h4 id="pocketpylon">Part lists and Software for our Prototypes:

Part lists and Software for our "Pylons":

"Pocket Pylons" (pocket-sized repeaters that you can carry around with you) and "Fixed Pylons" (fixed repeaters that are used to carry the LoRa signal longer distances and act as "bridges" between the wifi-enabled repeaters that anyone with a phone can access).</h4>

Note that for these options below, identical hardware is used for the repeater/transmitter parts - whether you are making a "pocket pylon" - that uses a smaller antenna, a "backpack pylon" with a larger antenna, or a "fixed pylon"(yeah, we couldn't resist) - that you wish to place on top of a building or somewhere else outside, for better reception and range.

<h5 id="option1">Option 1 - ESP 32 (LoRa Repeater that is wifi-enabled)</h5>

<strong>Hardware:</strong>

<strong>915MHz ESP32 LoRa 0.96 OLED Development Board SX1276 WiFi Bluetooth Transceiver Module + LoRa Antenna +JST Connector for Arduino LoraWan IOT Internet of Thing (Pack of 2)</strong> <strong><a href="https://www.amazon.com/gp/product/B086ZG25DZ/ref=ppx_yo_dt_b_asin_title_o03_s00?ie=UTF8&amp;psc=1"> https://www.amazon.com/gp/product/B086ZG25DZ/ref=ppx_yo_dt_b_asin_title_o03_s00?ie=UTF8&amp;psc=1</a></strong>

<strong>ESP32 LoRa 32 (V2), ESP32 Development Board WIFI Bluetooth LoRa Dual Core 240MHz CP2102 with 0.96inch OLED Display included 868/915MHZ</strong> Antenna for Smart Cities, Smart Farms, Smart Home, and IoT Makers <strong><a href="https://www.amazon.com/gp/product/B076MSLFC9/ref=ppx_yo_dt_b_asin_title_o00_s00?ie=UTF8&amp;psc=1">https://www.amazon.com/gp/product/B076MSLFC9/ref=ppx_yo_dt_b_asin_title_o00_s00?ie=UTF8&amp;psc=1</a></strong>

<strong>Software:</strong>

A zip file with software for either the esp32 or arduino models is available here:

<h4 id="kits">Kits from Robots Everywhere with everything needed for the Arduino option</h4>

<strong>COMING SOON

</strong>

<h5 id="option2">Option 2 - Arduino (LoRa Repeater w single bluetooth connection)</h5>

The same basic repeater - that literally uses the same software - but this one requires a bit of soldering, and is made using an inexpensive arduino and a semtech chip.

The nice thing about this particular arduino is that it costs $1 if you buy more than 50.

We are designing and potentially mass producing a larger, pre-made circuit, for use with the arduino options - will make it easier for people to put together.

<h4 id="software">Our LoRa software (for our "pocket pylon" prototypes &amp; potentially other LoRa-compatible hardware)</h4>

<h4 id="transceiver">Transceiver software</h4>

<div id="a7211007-b09c-4a25-864e-251a0f382c01" class="module-timeline__message-container" role="row" data-row="288">

<div class="module-message module-message--incoming module-message--group" tabindex="0" role="button">

<div class="module-message__container module-message__container--incoming module-message__container--incoming-purple">

<div dir="auto">Install instructions are here:

<div class="module-message__text module-message__text--incoming" dir="auto">This is software for a very basic transceiver for either a LoRa heltec module with a display, or an arduino (without a display).</div>

<div></div>

</div>

</div>

</div>

<div id="e97c30bc-646f-4167-8342-e2d0fa35309e" class="module-timeline__message-container" role="row" data-row="289">

<div class="module-message module-message--incoming module-message--group" tabindex="0" role="button">

<div class="module-message__container module-message__container--incoming module-message__container--incoming-purple">

<div class="module-message__text module-message__text--incoming" dir="auto">Basically it acts like an old timey XBee series 1 and displays the last packet it got. So, it should be good for debugging /packet sniffing.</div>

</div>

</div>

</div>

<div id="178cfb99-fc3a-4ace-a5ab-66af2a456001" class="module-timeline__message-container" role="row" data-row="291">

<div class="module-message module-message--incoming module-message--group" tabindex="0" role="button">

<div class="module-message__container module-message__container--incoming module-message__container--incoming-purple"></div>

</div>

</div>

<div id="13f30794-db1f-4161-a6e6-84224dfbd84a" class="module-timeline__message-container" role="row" data-row="292">

<div class="module-message module-message--incoming module-message--group" tabindex="0" role="button">

<div class="module-message__container module-message__container--incoming module-message__container--incoming-purple">

</div>

<div dir="auto">Picture of Option2:</div>

finished-arduino-notations-copy.jpg

</div>

</div>

<h4 id="wifitext">Wifi App for Texting Software</h4>

<div dir="auto"></div>

This software interconnects between a com port (or more than one), a really derpy website that shows the last 10 messages and lets you input one (over LoRa). The cool thing is that it just works (tm) - even on old cell phones. The site even loads on a G1 phone from 2009

<h5>Link to our software, which includes a wifi app with texting software, on github here: </h5>

This firmware, written by Matteo Borri and Riley August, should work on most existing LoRa modules. (We suggest using a LoRa 32 heltec modules.)

This software works for up to 8 wifi-enabled devices at a time.

Here's a little model of what we are building:

----fones

------gateway

--------repeater

--------repeater

--------repeater

------gateway

----fones

These "pocket pylons" that we are building are able to use a 5v solar panel as-is. (5.6v is also within tolerances)[/caption]

&nbsp;

Above: CellSol in action.<br />This basically bridges LoRa, wifi (via a derpy webpage although i guess we can do telnet/ssh) and the uarts on the controller. Wiring is just 5v to panel, with the zener diode across the leads.<br />Note that the internal resistance of the panel is sufficient to prevent fuckups.<br />Note that the battery in the above photo was harvested from a dead ipad. We added wifi using some 5.1 volt zener diodes.[/caption]

&nbsp;

image3-1024x576.png

Above: This is still just super basic - yet already sufficient for coordinating between two areas.

<h4>Option 2: Arduino-based (requires soldering)</h4>

arduino-1-cropped.jpg

arduino-2-cropped-724x1024.jpg

Very simple circuit - for those who can solder. See below for the circuit we are designing to make it even easier to solder :)

Bluetooth adapters (for the arduino boards)

8-bluetooth-adapters-1-1024x540.jpeg

Blue tooth 3.0 adapters - 10 of them :) (for arduino boards)

8-bluetooth-adapters-2-1024x540.jpeg

Blue tooth 3.0 adapters - 10 of them :) (for arduino boards)

Bluetooth modules that are easy to hook up to the arduino: HC05

HC05-cropped.jpg

Connect the HC05 to pins 0 and 1 and it will work out of the box.

arduino-working-cropped-702x1024.jpg

This is the super basic version of the repeater as you see there's only four points of shoulder that are hard to do and even that one took a few minutes.

arduino-2-cropped-1-627x1024.jpg

Pretty much the most basic repeater possible

&nbsp;

solarpanel-w-antennae-706x1024.jpg

A 5v solar panel with antenna.

arduino-solarpanel.png

An arduino with bluetooth module soldered on and circuit soldered on for plugging into a solar panel. Note that the bluetooth functionality of these repeaters can be dismantled if desired by "plugging" the bluetooth connector, if desired. [?Note to make sure this "plugging" is explained correctly?

<h4 id="licensing">Licensing</h4>

The RadioHead library uses GPL 3.0, which requires us to make everything we use it with also available under GPL 3.0.

<h4 id="captiveportal">Captive Portal Implementation</h4>

We are building capabilities into our little wifi access points so that a user will automatically redirect to our desired homepage upon accessing the network.

There are several different ways that this can be accomplished (and we'd love to hear more). So far we have:

<ol>

<li>There's an HTTP redirect

Usually used when people are already using a well known URL that you don't want to change, rather than a user that is firing up their client for the first time on the network, but still deserves to be on the list until we rule it out.</li>

<li>User's can be redirected to our desired IP address at the router level. This is how most "Captive Portals" as these are known as, are implemented. A "captive portal" is what you deal with when you access any corporate network - for instance, at a hotel, the airport, or when you're somewhere like whole foods - it makes you login or give a code or do whatever so you will be allowed to access anything else on the network.For us, we're not trying to limit what people can access, since there's nothing but our stuff on this network - although that might be a useful tool in the future, if resources are limited and a certain page accessible on the LoRa network is hogging all the bandwidth :)For us, we're just trying to make it easy for new users to find the only page that exists, by taking them there automatically when they fire up their browser.</li>

</ol>

<h4 id="antennaes">Antenna Info</h4>

Matteo has created a 3D printable antennae stand (need link to file here) that also doubles as a ruler for measuring just the right length of wire to use for the best reception of a specific frequency.

Link to 3D printer file for the antennae stand here

photo

idea is that you use the 3d printed part both as the whip antenna holder and as a meaasure to cut the antenna wire with

Our LoRa network uses 915MZ as its frequency. Different frequencies will use different lengths of wire on our antennae ruler/stand. You can use the ruler to measure exactly the right length of wire for your antennae, before you cut it. (You can use this tool to make a better antennae for your wifi router too this way.)

1) Print out our antennae stand/ruler for frequency wire length tool

2) Use the tool to measure the desired length of wire for your antennae, and cut it

3) Slide the wire through the antennae stand

4) Connect the antennae to your LoRa repeater or Wifi Router

Be careful where you place your repeater, as the antennae itself can shadow the solar panel and interfere with it's ability to capture power from the sun.

This antennae is supposed to work for longer distances, like 25 miles - and our software is already configured to work with it: <strong><a href="https://www.digikey.com/en/products/detail/digi/XBP9B-XCST-001/3482817">https://www.digikey.com/en/products/detail/digi/XBP9B-XCST-001/3482817</a></strong>

Antennas

<a href="http://www.shopantenas.com.br/antena-movel-uhf-5-8-de-onda-whip-900mhz/p" rel="nofollow">http://www.shopantenas.com.br/antena-movel-uhf-5-8...</a>

Antenna mount:

<a href="http://www.shopantenas.com.br/suporte-magnetico-preto-p--antena-movel/p" rel="nofollow">http://www.shopantenas.com.br/suporte-magnetico-preto-p--antena-movel/p</a>

Note: You generally want to use as big of an an antenna as is possible while still being practical to carry around (in the case of a pocket pylon).

For the fixed "pylon" repeaters, there is a concern that the antennae aren't so big as to draw too much attention - as is the reason for keeping the size of the solar panels used as small as possible. (So they don't get stolen.)

<h4 id="nextsteps">Next Steps</h4>

1) make a basic repeater with just an arduino and a semtech chip

(get a POS $1 arduino to do repeater things) Note: ideally, these will be able to be made cheaper than our original prototype (see pics above) - and, most importantly, will use a lot less power.

2) Getting an antenna reasonably high up where Matteo is - in San Rafael - (~1.5-2m above building) - so we can try some long range tests.

<h4 id="additionalfeatures">Additional Features for next version</h4>

<strong>Re: encryption</strong>

Sure. Eventually, it would be nice to have some encryption available for sensitive messages. Right now, we think it would be more useful to be able to say "I'm here help" over an open network than to have no options at all.

<strong>re: bulletin boards</strong>

Since we are dealing with slow model speeds, someone suggested implementing a bulletin board system of sorts. So Matteo build one. This "bulletin board" is just a little website that has only has 10 message slots but there can be up to 255.

Why a bulletin board system? Because LoRa is as slow as some of the earliest modem speeds - 9600 baud or lower even - so why not go back to the types of communication platforms that were used in the 90's when bandwidth was going that slow.

<h4 id="libraries">Software Libraries (we used to write our node software)</h4>

<strong>RadioHead Packet Radio library for embedded microprocessors</strong>

<strong><a href="http://www.airspayce.com/mikem/arduino/RadioHead/">http://www.airspayce.com/mikem/arduino/RadioHead/</a></strong>

This is the RadioHead Packet Radio library for embedded microprocessors. It provides a complete object-oriented library for sending and receiving packetized messages via a variety of common data radios and other transports on a range of embedded microprocessors.

The version of the package that this documentation refers to can be downloaded from <strong><a href="http://www.airspayce.com/mikem/arduino/RadioHead/RadioHead-1.107.zip">http://www.airspayce.com/mikem/arduino/RadioHead/RadioHead-1.107.zip</a></strong> You can find the latest version of the documentation at <strong><a href="http://www.airspayce.com/mikem/arduino/RadioHead">http://www.airspayce.com/mikem/arduino/RadioHead</a></strong>

<h4 id="definitions">Definitions of some basic terms to help people new to the project understand what we are doing</h4>

Access point:

Gateway:

Router:

Repeater:

Wifi:

Bluetooth:

LoRa:

<h4 id="wordcompression">Word Compression Consideration</h4>

Why might we want word compression for our LoRa network?

The "commercial code" below is one of several methods that one can use to achieve excellent "word compression" for english words. "Word compression" is a concept that originated during the old days of telegrams and systems where you paid for every word to be transmitted. In our case, every word counts because our network bandwidth is so limited - and is literally as slow as the old dial-up modems of the 90s. (As slow as 9,600 - 12,000 baud modems)

These codes are examples of what is called "dictionary compression." An application is written in such a way that it recognizes common phrases, like "what time should we meet?" and assigns it a code that will necessitate transmitting fewer characters.

The way it works: The application (in this case our texting app &amp; bulletin board app) - recognizes the phrase the person has typed and then uses a shorter abbreviation to represent it - sends the code (that uses less characters) across the network - where it is decoded on the receiver's side into the original message. This is similar to the autocorrect functions that everyone is used to using on their phones.

What would creating our own codes involve?

Creating our own codes would involve determining the 32768 most common words in english - perhaps algorithmically.

Why don't we use lossless text compression then instead of codes?

Because compression not optimized for text doesn't go very far for short messages. To demonstrate this concept, one can take any one sentence typed here, save it as a text file, zip the text file, and see that it won't be much shorter.

Why are we discussing this for this project?

(This subject came up because there's a big emphasis in sending as few bytes as possible on the LoRa discussion forums.)

Let's say that we take the most common 32768 words in the english language (the other 32767 are pairs of ASCII characters that disallow control characters, so losing one bit out of 16 i not a big problem). Now each word, or even common phrase, if we want, fits two bytes. You can even do a bit of cleanup so that "how are you" and "how r u" and so on map to the same thing, and are printed "how are you" at the receiving end unless tagged "verbatim." [? (Note: we haven't discussed tagging messages? let's! :) ?]

Note: This is done phone/pc side where you have a lot of hard disk space for a dictionary and a lot of cpu power for realtime substitution.

Note: Interestingly, you can even XOR the -dictionary- with a crypto key for private messaging, and if you swap those often enough, that's your encryption solution. (Not unbeatable of course, but since it can be of arbitrary length, you could even have a one time pad, which IS unbeatable by definition). This type of "encryption" won't slow things down as much, as it's just a XOR operation that you do once on the dictionary. So, not unbeatable, but decent. And not super secure in that it requires a shared key, but eh.

Lisa thinks it sounds like a project in itself, but Matteo thinks it's not necessarily a big job, it's just a case of finding out what the most common X words in Y language are, and sorting them. Or you can just scrape a dictionary and sort it alphabetically if you are lazy.

Commercial code (communications)

https://en.wikipedia.org/wiki/Commercial_code_(communications)

"In telecommunication, a commercial code is a code once used to save on cablegram costs.[1] Telegraph (and telex) charged per word sent, so companies which sent large volumes of telegrams developed codes to save money on tolls."

<strong>For Later:</strong>

<h4 id="otherhardware">Other LoRa Hardware</h4>

Hardware we think might work, if we create a LoRa gateway for it

<strong>The Ark</strong>

<a href="https://github.com/thearkadia/The_Ark/blob/master/README.md">https://github.com/thearkadia/The_Ark/blob/master/README.md</a>

<strong>LORA1276|FCC|CE|868 915MHz|100mW|Lora module|wireless RF module| long range transceiver module</strong>

<a href="https://www.nicerf.com/product_146_136.html">https://www.nicerf.com/product_146_136.html</a>

<h4 id="install">LoRa Install Guide</h4>

The esp32 does not have a toolkit, but you can use the arduino toolkit with a plugin module to get it to work on the esp32. (add links)

1) On your computer, install the arduino toolkit, and the esp 32 plugin that works with the arduino toolkit.

2) Use the toolkit to put our LoRa software on your device.

3) Take any web-enabled device and fire up a browser type in the IP address 192.168.x.1

4) Type in your message in the form field and click "send" - to send a message to everyone on the network that also has the page loaded.

5) Users can refresh the page to see new messages.

The page will save and display the last 10 messages sent. (We are working on having a second page that displays the last 100 messages.)

cellsoll-473x1024.png

<h4 id="techsupport">Tech Support</h4>

contact: cellsol@robots-everywhere.com

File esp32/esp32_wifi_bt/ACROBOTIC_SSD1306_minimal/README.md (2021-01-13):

# Ai_Ardulib_SSD1306

Example code for using the ESP8266 Development Board and an OLED display for
visualizing different things on its 128×64 pixel screen.

## Description

For more details, check out the tutorial page at:

   * http://learn.acrobotic.com/tutorials/post/esp8266-oled-display-using-i2c

If you like my work, you can help me dedicate more time to building projects, 
writing code, and making videos about them:

   * https://www.patreon.com/acrobotic
   * https://www.paypal.me/acrobotic

You can also purchase products from my little online shops to help fund future 
Open-Source projects like these! I'll always put my best effort in every project, 
and release all my design files and code for you to use. 

   * https://acrobotic.com/
   * https://amazon.com/acrobotic  

## Installation

Please follow the instructions outlined in the tutorial linked above.  The steps
describe how to install the library needed for the programs to run properly.

## License

Released under the MIT license. Please check LICENSE.txt for more information. 
All text above must be included in any redistribution.

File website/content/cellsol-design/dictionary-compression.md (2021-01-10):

---
publishdate: 2019-11-17
lastmod: 2020-11-24
---

Compression is a useful tool for stretching low bandwidth connections a bit further, but comes with significant computing overhead. Using dictionary compression attempts to remove the overhead of traditional
compression algorithms, while retaining their effectiveness for a specific subset of data - notably, large blocks of text.

### Why might we want word compression for our LoRa network?

The "commercial code" below is one of several methods that one can use to achieve excellent "word compression" for english words. "Word compression" is a concept that originated during the old days of telegrams and systems where you paid for every word to be transmitted. In our case, every word counts because our network bandwidth is so limited - and is literally as slow as the old dial-up modems of the 90s. (As slow as 9,600 - 12,000 baud modems)
These codes are examples of what is called "dictionary compression." An application is written in such a way that it recognizes common phrases, like "what time should we meet?" and assigns it a code that will necessitate transmitting fewer characters.

The way it works: The application (in this case our texting app & bulletin board app) - recognizes the phrase the person has typed and then uses a shorter abbreviation to represent it - sends the code (that uses less characters) across the network - where it is decoded on the receiver's side into the original message. This is similar to the autocorrect functions that everyone is used to using on their phones.

### What would creating our own codes involve?

Creating our own codes would involve determining the 32768 most common words in english - perhaps algorithmically.

### Why don't we use lossless text compression then instead of codes?
Because compression not optimized for text doesn't go very far for short messages. To demonstrate this concept, one can take any one sentence typed here, save it as a text file, zip the text file, and see that it won't be much shorter.

### Why are we discussing this for this project?
(This subject came up because there's a big emphasis in sending as few bytes as possible on the LoRa discussion forums.)
Let's say that we take the most common 32768 words in the english language (the other 32767 are pairs of ASCII characters that disallow control characters, so losing one bit out of 16 i not a big problem). Now each word, or even common phrase, if we want, fits two bytes. You can even do a bit of cleanup so that "how are you" and "how r u" and so on map to the same thing, and are printed "how are you" at the receiving end unless tagged "verbatim." [? (Note: we haven't discussed tagging messages? let's! :) ?]

Note: This is done phone/pc side where you have a lot of hard disk space for a dictionary and a lot of cpu power for realtime substitution.

Note: Interestingly, you can even XOR the -dictionary- with a crypto key for private messaging, and if you swap those often enough, that's your encryption solution. (Not unbeatable of course, but since it can be of arbitrary length, you could even have a one time pad, which IS unbeatable by definition). This type of "encryption" won't slow things down as much, as it's just a XOR operation that you do once on the dictionary. So, not unbeatable, but decent. And not super secure in that it requires a shared key, but eh.

### Current Implementation

We have no implementation currently used by our firmware, but we have included some example implementations in our GitHub repository. Smaz, PySmaz, Shoco, and a dictionary compression algorithm designed by Kay Borri are all included.

We encourage compression to be implemented on the client side of any CellSol-integrated application, rather than along the network itself, in order to maintain as much intercompatibility as possible.

### Commercial code (communications)
https://en.wikipedia.org/wiki/Commercial_code_(communications)
"In telecommunication, a commercial code is a code once used to save on cablegram costs.[1] Telegraph (and telex) charged per word sent, so companies which sent large volumes of telegrams developed codes to save money on tolls."

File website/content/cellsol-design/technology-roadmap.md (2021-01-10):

---
title: Technology Roadmap
publishdate: 2019-11-17
lastmod: 2020-11-24
---

{{< toc >}}

## Multiple Channels

CellSol currently operates on the principle that a single bulletin board is sufficient for a local network. We intend, in the short term, to implement multiple channels, to allow users to filter messages.

## Internetworking

CellSol's mesh architecture does not scale, due to bandwidth limitations, so we will be developing bridging devices that will allow CellSol networks to communicate with one another either directly, or
through the wider Internet when it is available. The former is a more resilient implementation, but range limited, whereas the latter is limited by Internet connectivity, but will allow for a centralized
point of contact across the whole CellSol network. In either case, it is likely we will use Internet Relay Chat (IRC) as a transfer protocol, due to all packets being text and it being optimized for
low bandwidth operation.

## Datalogging and Instrumentation

Humans aren't the only users that have a place on the CellSol network. Going forward into 2021, documentation for writing firmware for autonomous instruments and integrating them into the CellSol network
will be provided. Bandwidth is, of course, a serious consideration (LoRa transmits and receives data ten thousand times slower than 4G cellular), and restricting the resource usage of dataloggers on the main mesh, or even implementing a quality-of-service (QoS) system
to slow down certain traffic types over others may be required. How individual mesh networks are used will significantly determine how they need to regulate datalogger traffic, so further discussion is definitely needed before a design is decided upon.

One way we expect to support these dataloggers early into 2021 is to expose a webservice endpoint from WiFi pylons, so that HTTP requests can be used to send and receive messages instead of just refreshing
the entire chat page as a browser does.

## Security

By using standard client software (web browsers, IRC clients) endpoint security becomes much easier to achieve, but eventually CellSol may need some bandwidth-preservation security implementations. Spam
bots, redirect bots, and other denial of service attacks are effective given CellSol's low overall throughput, and low overhead software systems to prevent them will need to be designed as adoption
increases, especially if we are to rely on the system during a social crisis such as the widespread American protests in 2020.

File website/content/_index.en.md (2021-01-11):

---
title: Home
publishdate: 2020-11-05
lastmod: 2021-01-11
---
# CellSol - A Network for Unity and Resilience

Welcome to CellSol!

This website and its associated project are now in beta! Come take a look at our [GitHub](https://github.com/RbtsEvrwhr-Riley/CellSol/)

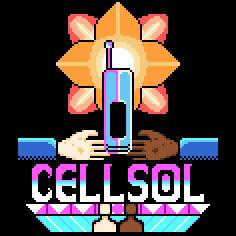
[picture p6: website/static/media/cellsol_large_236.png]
CellSol Logo - Large


{{< include file="about-cellsol/our-mission.md" markdown="true">}}

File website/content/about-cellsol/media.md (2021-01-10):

---
weight: 10000
publishdate: 2019-11-17
lastmod: 2020-11-24
---

Here you can find media assets for promoting the CellSol project.

All logos and assets are copyright 2020 Robots Everywhere, LLC. If you wish to use these assets to promote CellSol, please [contact us](mailto:cellsol@robots-everywhere.com)

{{< toc >}}

# Large Logo - Posters, Vertical Banners, Loading Screens

CellSol Logo - Large

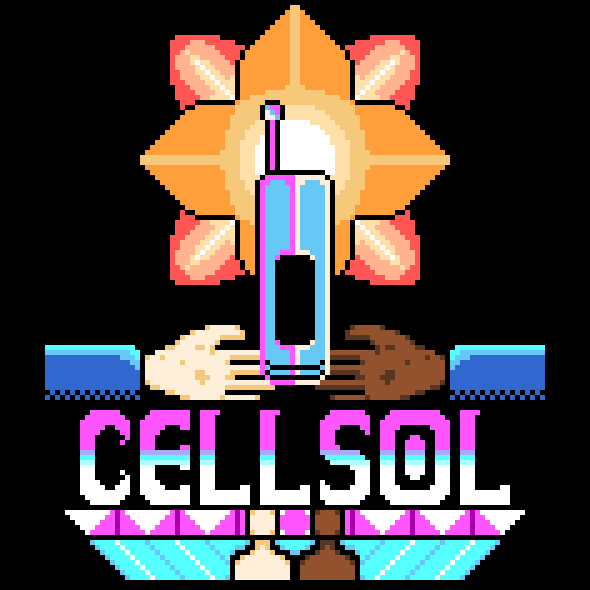
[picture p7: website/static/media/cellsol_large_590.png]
CellSol Logo - Large


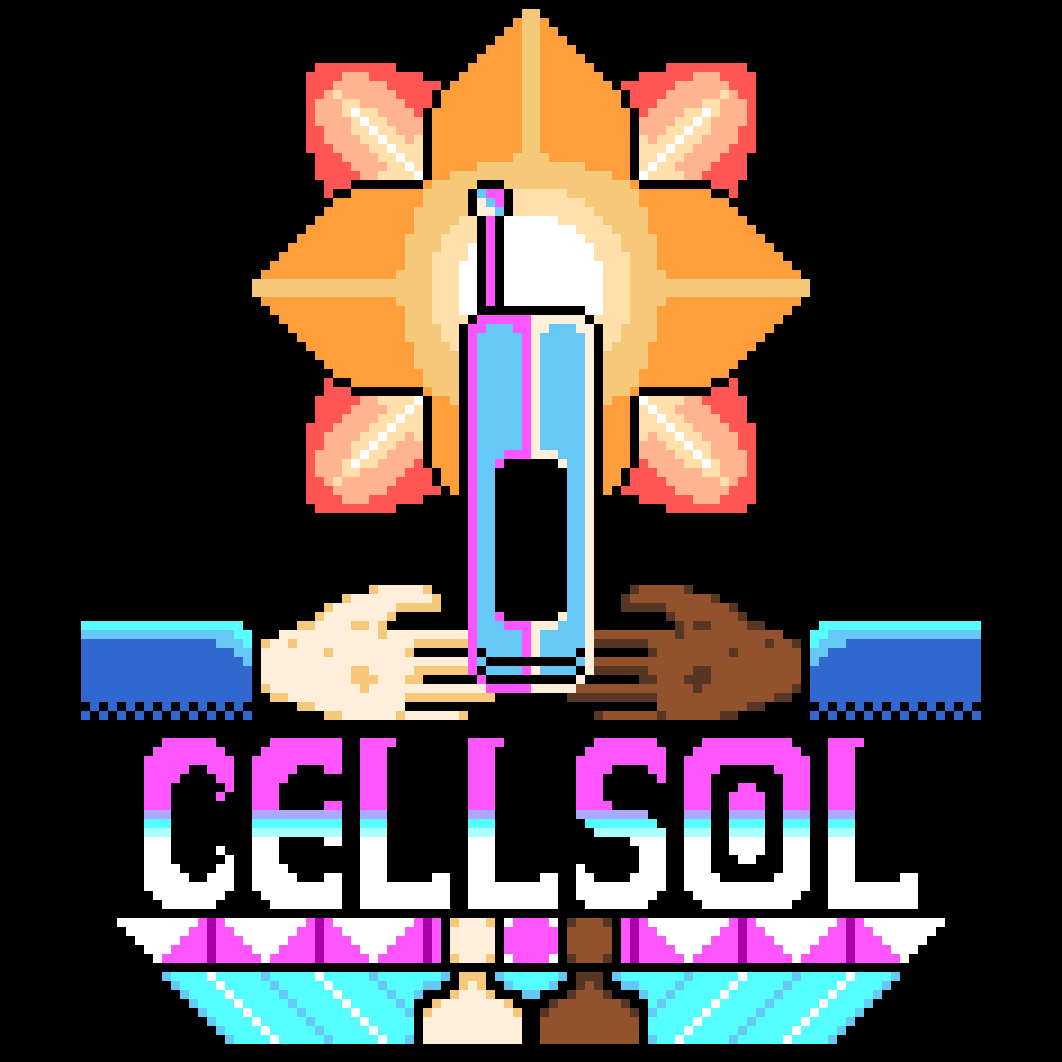
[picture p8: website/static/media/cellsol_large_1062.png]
CellSol Logo - Large


# Small Logo - Headers, Horizontal Banners, Profile Pictures

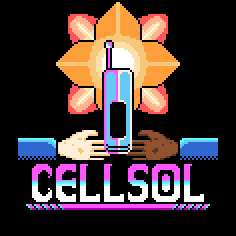
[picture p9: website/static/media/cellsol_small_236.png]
CellSol Logo - small


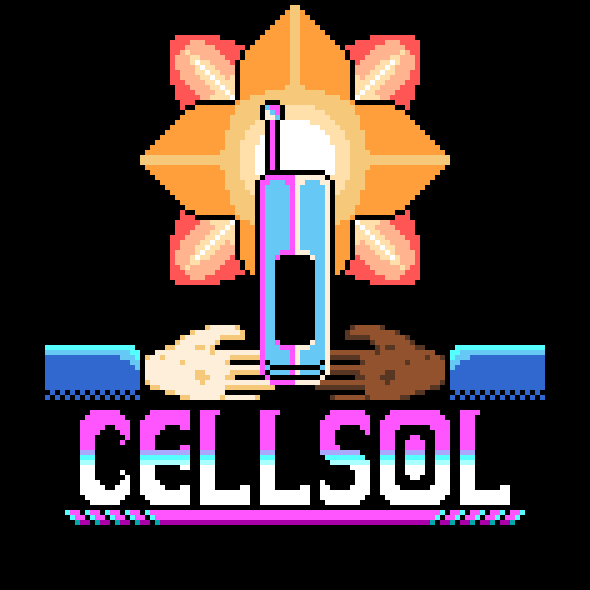
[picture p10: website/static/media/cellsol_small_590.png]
CellSol Logo - small


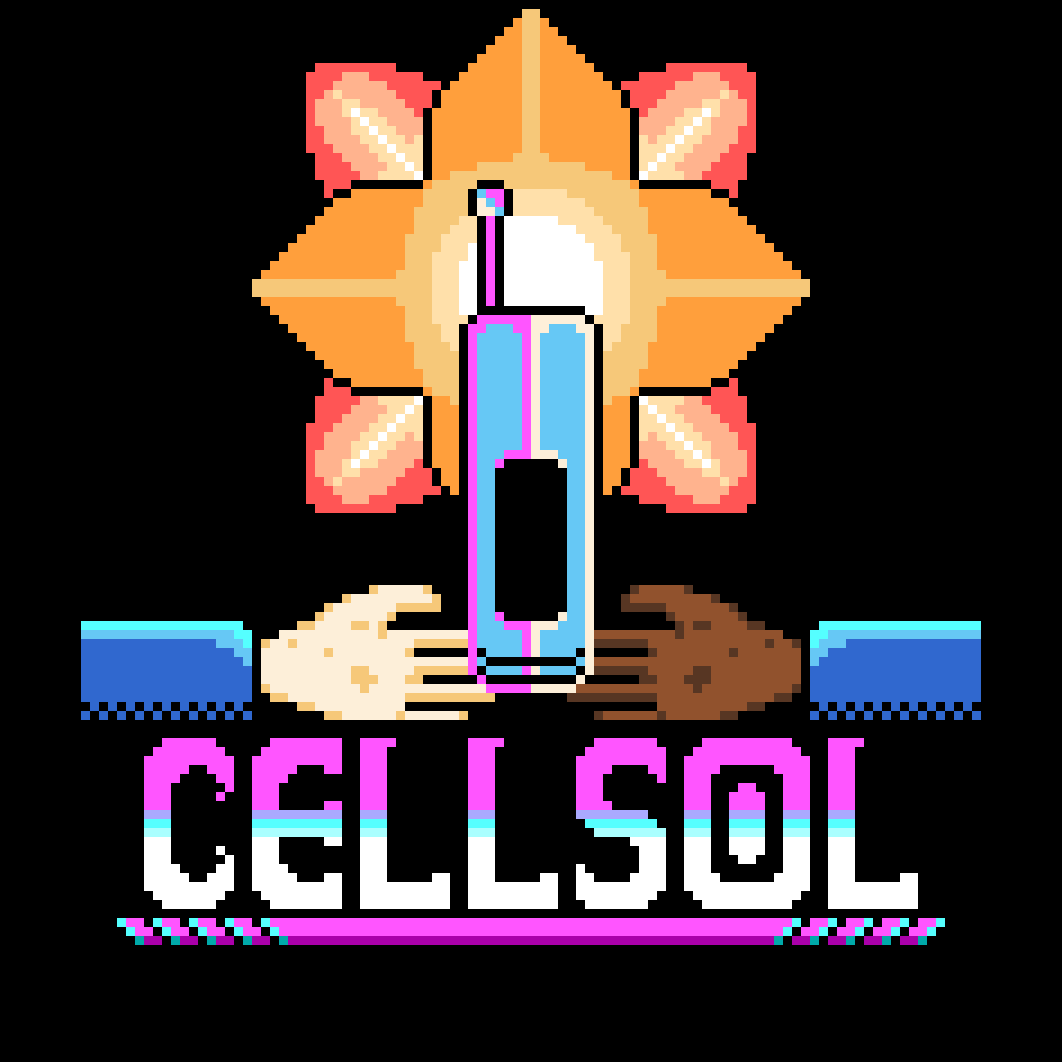
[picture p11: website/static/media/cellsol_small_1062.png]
CellSol Logo - small


# Icon Logo - App Icons, Small Banners, with Transparency

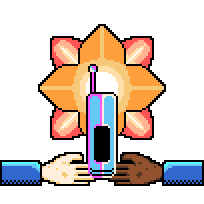
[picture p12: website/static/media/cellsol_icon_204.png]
CellSol Logo - icon


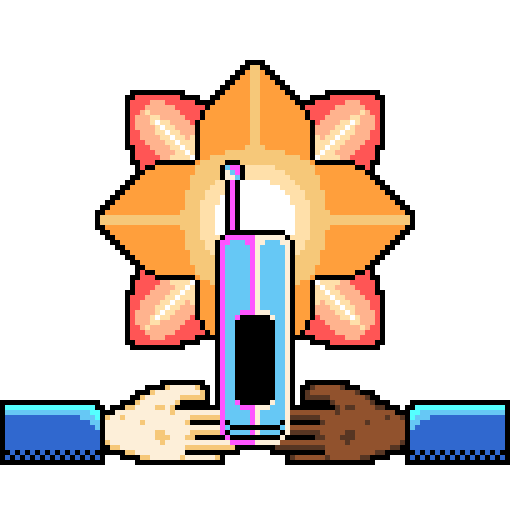
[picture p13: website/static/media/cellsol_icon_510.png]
CellSol Logo - icon


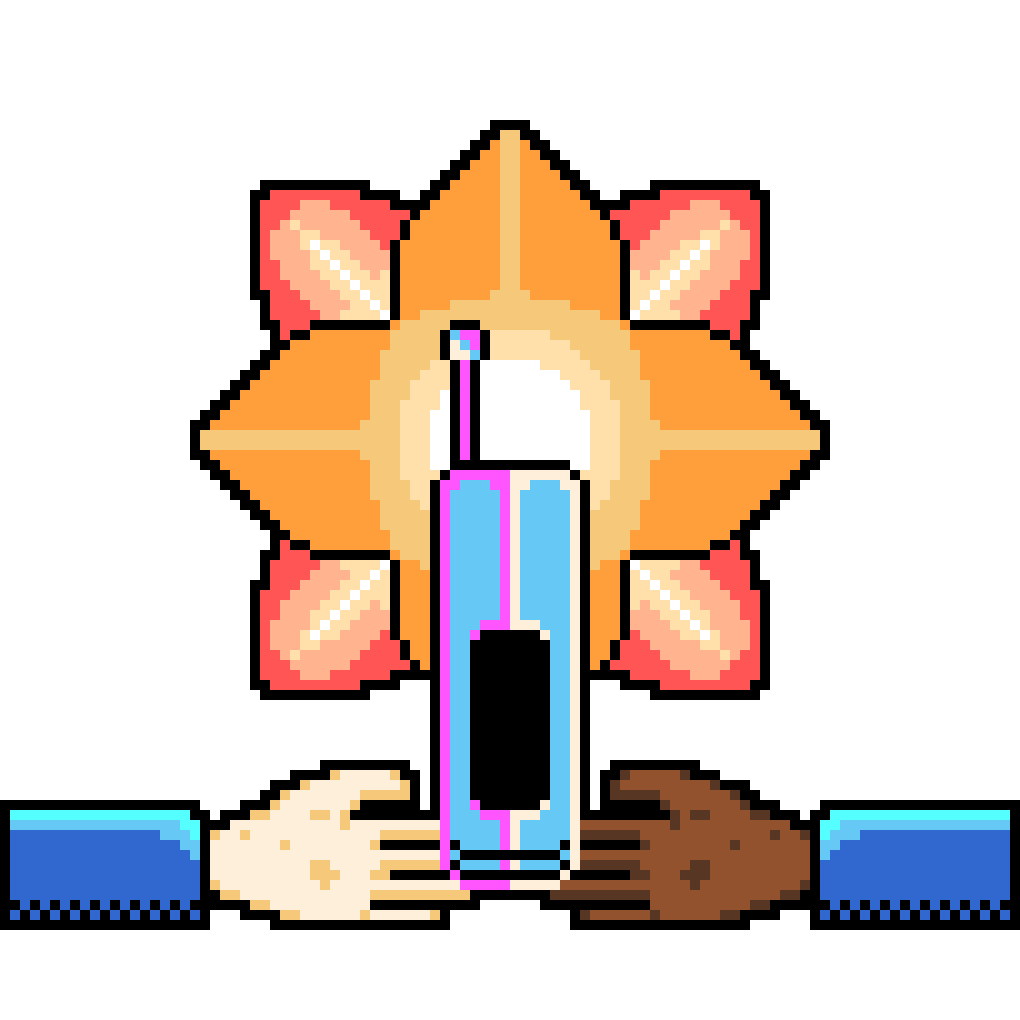
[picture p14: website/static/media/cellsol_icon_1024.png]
CellSol Logo - icon


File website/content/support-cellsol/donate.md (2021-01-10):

---
publishdate: 2019-11-05
lastmod: 2020-11-24
---
In the near future, we will begin accepting donations to fund further development and expansion of the CellSol project.

Funds will be first allocated towards purchasing needed hardware and equipment for the expansion of the project (such as prototyping), then paying for development effort where possible. While we
expect most development effort to come from our volunteers, large hardware and architecture developments will ideally be funded privately.

CellSol is an open-source project owned by Robots Everywhere, LLC. While it may become its own nonprofit charity organization in the future, the overhead for doing so is 
outside the current scope of both the project and its finances.

If you're interested in supporting the project in the meantime, [contact the project admins](mailto:cellsol@robots-everywhere.com) by email.

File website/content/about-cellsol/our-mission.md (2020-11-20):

## Introduction
What if the internet and cell phone towers went down for more than a few hours - or during an emergency situation? No communication could lead to lost lives.

## Project

The end goal of the project is to have a widespread network able to handle low-bandwidth traffic (text, compressed images) for a large number of users, to fill gaps when the larger Internet is unavailable.

In the event of an emergency, the CellSol network, much like the Internet, can be used as a knowledge base, as well as a rally point, giving people a tool to use to coordinate and organize even if 
other communication systems go down. We intend to scale the design, with long-haul routing capabilities, so that regional networks can intercommunicate and interoperate, allowing for a wider breadth of use cases.

## Design Summary

The overall design is a [mesh network](https://en.wikipedia.org/wiki/Mesh_networking) of [LoRa](https://www.semtech.com/lora/what-is-lora) devices, called "Pylons"
that act as repeaters (extending the range of the network). Terminals (devices that users access the network with) also repeat packets, so that a network
made up entirely of end users is possible.

The two basic types of pylons are the ESP32 WiFi Pylon (a terminal device) and the Ardunio Repeater Pylon (a pure repeater, but can have bluetooth to use as a terminal).
 
Pylons with more specialized uses, such as data repositories for local emergency resources (phone numbers, shelter locations, etc.) and knowledge bases (such as a Wikipedia mirror) are also intended to be
developed in the future, to add to the overall usefulness of the network.

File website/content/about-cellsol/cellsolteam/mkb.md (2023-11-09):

---
title: M.K. Borri
weight: -10
publishdate: 2019-11-17
lastmod: 2020-11-24
---

M.K. Borri is the chief engineer of the CellSol project, having designed all of the system's specifications, hardware, most of the firmware, and is the driving force behind
the project's philosophy of relentless improvement.

MKB has been an inventor for as long as anyone can remember, having worked on network systems for homes, small businesses, and libraries in Italy in the early days of the Internet, as far back as 1994. MKB went on to study Electrical and Computer Engineering at St Mary's University, in San Antonio, Texas, and founded [Robots Everywhere](https://www.robots-everywhere.com) along with Riley August. Since then, MKB has been designing and implementing solutions in instrumentation, data logging, robotics, light duty manufacturing, and many other areas for both public and private clients. 

The [L-Cheapo Laser Cutter](https://www.robots-everywhere.com/lcheapo) is another of MKB's prominent works.

CellSol is not MKB's first charity project by any means, having worked with the Aaron Swartz Day Hackathon in the past on several projects including the  [Swartz-Manning VR Destination](https://www.aaronswartzday.org/vr/) and [ASD Solar Survival Project](https://www.aaronswartzday.org/solarsurvival/).

When not trying to change the world through innovative technology, MKB enjoys exploring, both real places and virtual, by swimming, sailing, and cycling. MKB is also a prolific writer of fantasy and science fiction; some if it can be found for free at the [Emlia Website](https://emlia.org/pmwiki/pub/web/VeryDifferentPlaces.VeryDifferentPlaces.html)

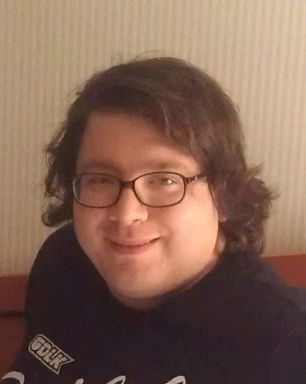
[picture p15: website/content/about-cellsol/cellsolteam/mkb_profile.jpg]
M K Borri being fat


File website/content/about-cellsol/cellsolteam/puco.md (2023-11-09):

---
title: Ryan Sternlicht
publishdate: 2019-11-17
lastmod: 2020-11-24
---

Ryan Sternlicht is a San Francisco raised educator, researcher, advisor, maker, and hacker.  He has advised a number of startups in the fields of AR, VR, self driving cars, flying cars, and 3D manufacturing. As a maker and hacker he volunteers and advises a number of makerspaces, hackerspaces, open source hardware and software projects, and tech nonprofits organizations around the world.  While in the Bay Area he volunteers at a number of nonprofits, like Noisebridge Hackerspace, the Internet Archive, and NeuroTechX; he also assists the game dev department at CCSF.   

Find out more about Ryan at [his website](https://ryansternlicht.me).

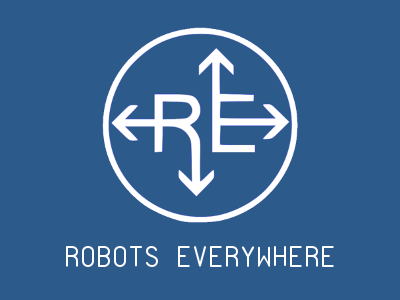
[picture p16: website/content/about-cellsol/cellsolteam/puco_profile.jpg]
Ryan file picture


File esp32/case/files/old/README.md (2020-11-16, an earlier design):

This is an old case designed by Espressif and doesn't really fit the v2.

Might fit a stock v1?

We will probably remove it from the repository.

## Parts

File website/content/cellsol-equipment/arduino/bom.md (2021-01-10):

---
title: Bill of Materials
publishdate: 2019-11-17
lastmod: 2020-11-24
---

* 1x TP4056 Li-Ion Battery Charger Module
* 1x A3338 3.3V Regulator
* 1x Arduino Nano or Nano Pro
* 1x HC05 or HC06 Bluetooth Module
* 1x SX1276 Chip or SX1276 Module
* 1x 2.2k 1/4W Resistor
* 1x 470nF ceramic capacitor
* 1x 4.2V-5V Solar Panel
* 1x 4.2V Battery or Battery Pack

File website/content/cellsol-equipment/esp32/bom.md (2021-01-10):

---
title: Bill of Materials
publishdate: 2019-11-17
lastmod: 2020-11-24
---

Everything you need for the LoRa32-based WiFi Pylon

* A Heltec Lora32 or Lora32v2 module
* The Arduino software, available [here](https://www.arduino.cc/en/Main/Software)
* A USB cable
* Battery holder (if needed for your battery)
* 1.2V batteries (the bigger the better) OR, any 3.6 or 3.7 volt battery (li-ion, lipo, etc.) See [Powering the Node](power)
* Battery connector for the Lora32 module (should come with the Lora32)
* A solar panel to charge the battery (optional, USB may also be used for charging if the pylon is connected to mains)
* A case for your Lora32, antenna, and battery - see our [case designs](../case-designs)

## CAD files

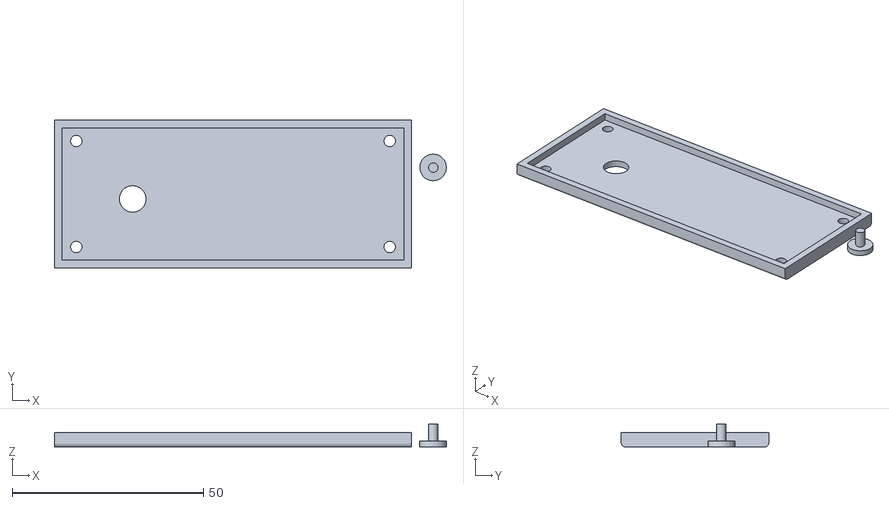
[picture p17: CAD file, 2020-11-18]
esp32/case/files/lora32_pylon_smallcase_top_buttons.stl
102.5 x 38.6 x 6.00

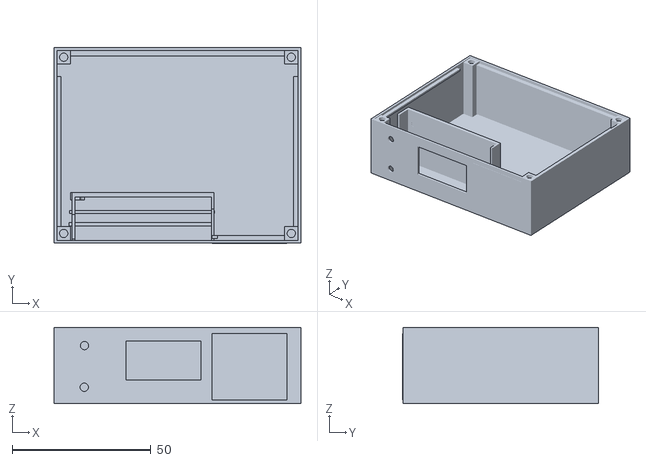
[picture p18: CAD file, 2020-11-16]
esp32/case/ttgo_esp32_bigcase_fixed_repaired.stl
89.0 x 70.6 x 27.4

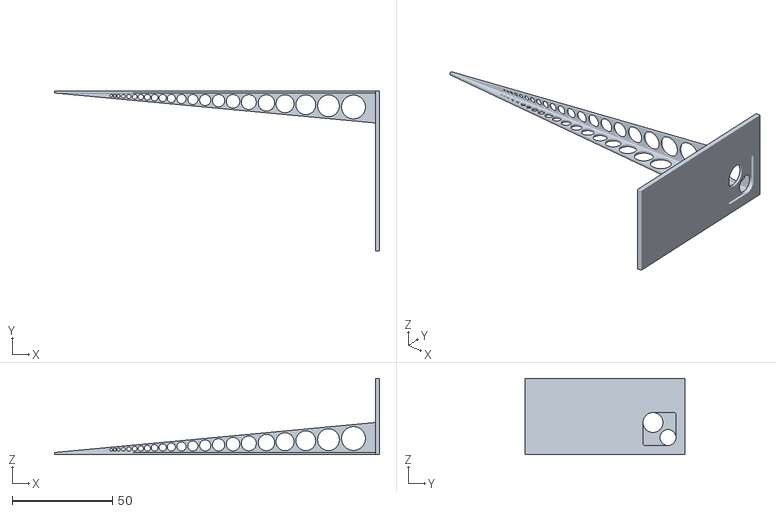
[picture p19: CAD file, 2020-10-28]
nano/arduino lora repeater antenna over tinfoil under.stl
162.5 x 80.0 x 38.0

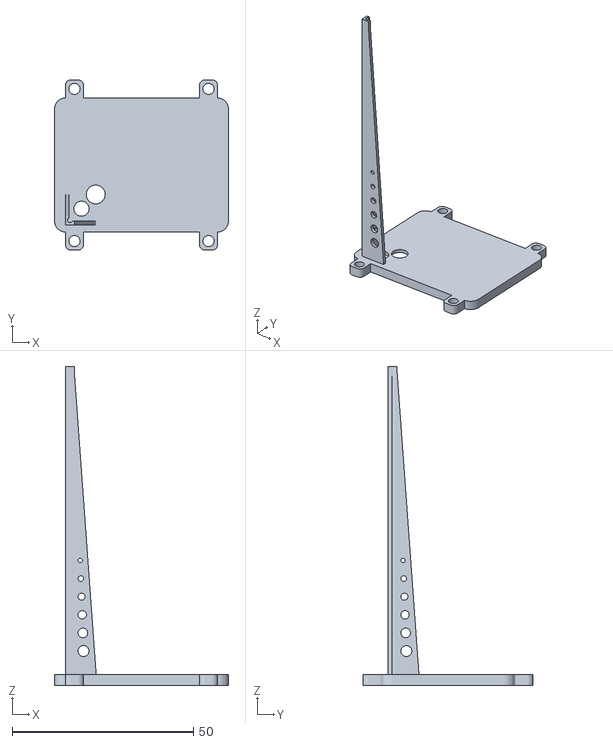
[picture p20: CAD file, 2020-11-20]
nano/case/nanopylon_box_top_antennaguide.stl
48.0 x 47.0 x 88.0

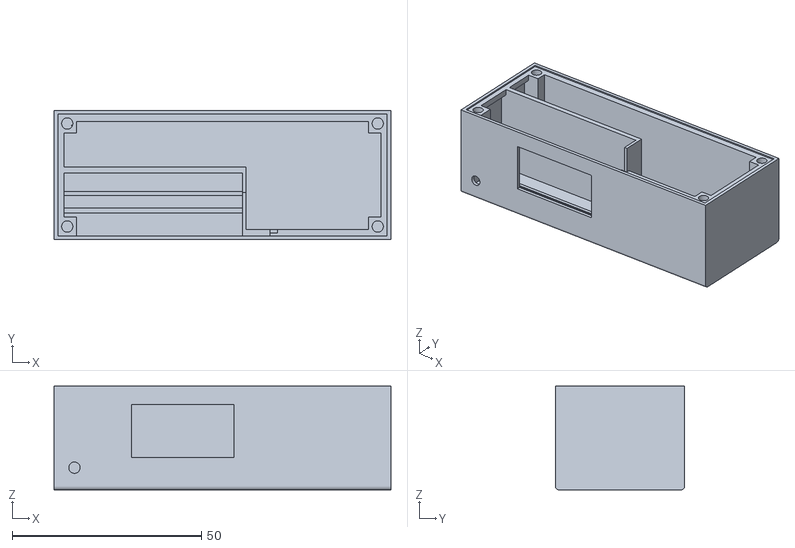
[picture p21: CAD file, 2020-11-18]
esp32/case/files/lora32_pylon_smallcase_bottom.stl
89.0 x 34.2 x 27.4

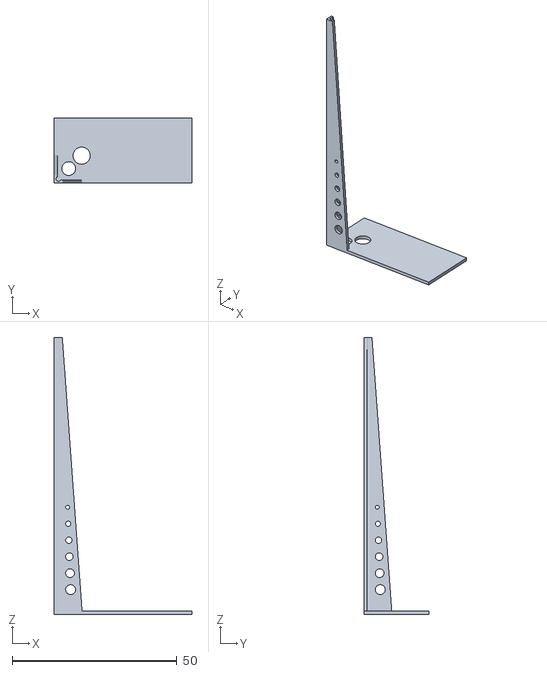
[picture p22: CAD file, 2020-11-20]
nano/case/nano_antennaguide.stl
41.8 x 19.9 x 84.1

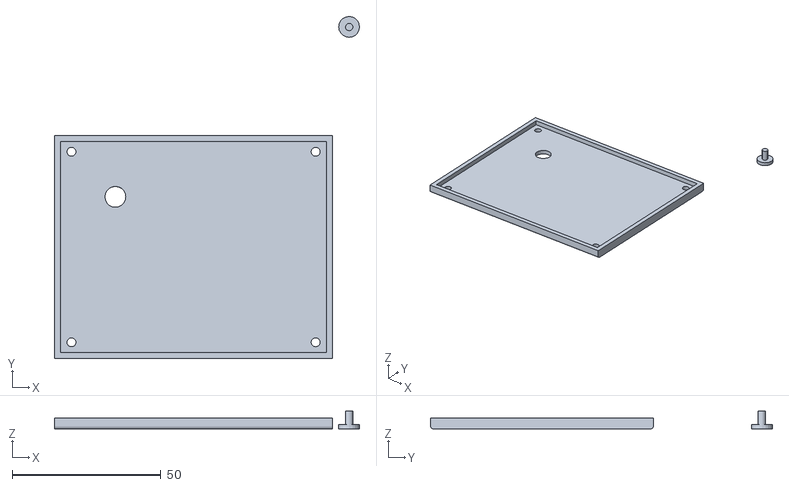
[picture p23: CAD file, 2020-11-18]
esp32/case/files/lora32_pylon_bigcase_top_buttons.stl
102.5 x 114.9 x 6.00

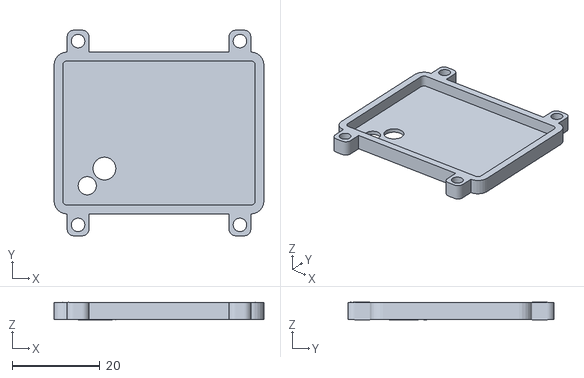
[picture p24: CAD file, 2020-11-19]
nano/case/nanopylon_box_top_holes.stl
48.0 x 47.0 x 4.00

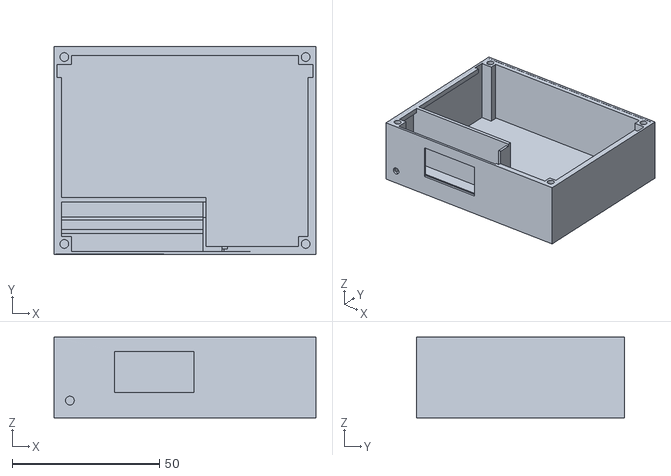
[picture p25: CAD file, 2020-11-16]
esp32/case/files/lora32_pylon_bigcase_bottom.stl
89.0 x 70.5 x 27.4

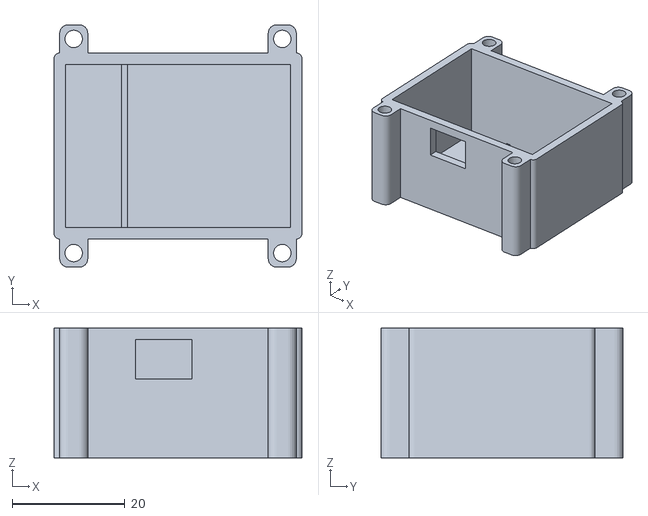
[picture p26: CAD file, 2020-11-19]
nano/case/nanopylon_box_bottom_usbport.stl
44.0 x 43.0 x 23.0

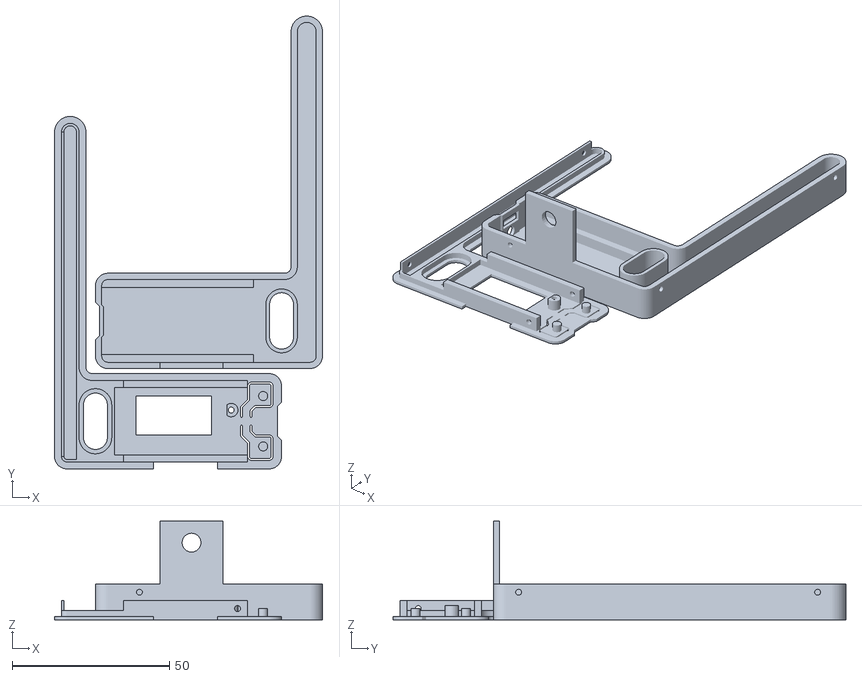
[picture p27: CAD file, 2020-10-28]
esp32/case/files/lora32_case_edited.stl
85.2 x 143.9 x 31.3

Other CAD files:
esp32/case/files/lora32_case_edited.skp
esp32/case/files/lora32_pylon_bigcase_bottom.skp
esp32/case/files/lora32_pylon_bigcase_top_buttons.skp
esp32/case/files/lora32_pylon_smallcase_bottom.skp
esp32/case/files/lora32_pylon_smallcase_top_buttons.skp
esp32/case/files/old/lora32_case_edited.skp
nano/case/nanopylon_all.skp

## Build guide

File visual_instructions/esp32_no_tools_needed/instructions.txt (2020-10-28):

These instructions assume that you don't have any tools. If you have a soldering iron and wire cutters and better tape and/or heat shrink, you should clearly use them, but if you can do that, you don't really need these instructions...

1) This is what you need to assemble the full kit:
* ESP32 module with antenna
* Tape roll and/or double sided tape
* USB solar panel
* Battery holder
* 1.2V batteries (the bigger the better) OR, any 3.6 or 3.7 volt battery (li-ion, lipo, etc.)

2) First thing first: check that the esp32 module is in good shape.

3) Connect the antenna - you'll have to carefully push down the coaxial connector.

4) Strip the wires for the battery case. You can use the tape roll if you have nothing better. 1.5cm or half an inch is sufficient.

5) This should be your end result.

6) Do the same with the wires that came with the esp32 module.

7) This should be your end result.

8) You have to connect these red to red and black to black.

9) Twist the wires together, bending them backwards afterward.

10) Using the tape, cover one wire (Doing black here). Make sure you cover it fully. 

11) Using the tape, cover the other. Make sure you cover it fully. Leave some tape hanging.

12) Use the tape you left hanging earlier to wrap around your connection. It doesn't look pretty, but it will hold for a long time.

13) Now you can put the batteries in. Mind your polarity! Put the little connector in its socket on the bottom of the esp32 module.

14) Connect the USB solar panel to the USB connector on the esp32. You're done!

15) If you have a different battery, same principle up until step 13 -- be sure to connect red to red and black to black.

16) If you have a USB powerbank, connect it between the ESP32 and the solar panel.

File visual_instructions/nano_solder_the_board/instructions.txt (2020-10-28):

These instructions assume that you know how to solder. This project can be attempted by a beginner even though it has some small solder joints.

1) Here are your parts: wire, capacitor, resistor, board, LoRa module, Arduino, voltage regulator, battery charger circuit, headers.

2) First, put the capacitor and resistor in their spots on the circuit board, C1 and R1 respectively. They don't have a polarity.

3) This is what the top of the board should look like. Solder those two parts.

4) Cut the extra leads. You'll need it in a bit.

5) Populate the holes on the LoRa module using the leads, or some wire. If you don't want to do all of them, just do the ones in the picture.

6) Stick the LoRa module on top of the circuit board, then solder it in place.

7) Use the headers and the rest of the leads to prepare the battery charger circuit and the Arduino. Don't fill IN+ and IN- yet. Again, you can skip some of the holes.

8) A different angle showing what holes you have to populate. Your Arduino may look a bit different.

9) Note where the voltage regulator goes. Also, note how the leads on the LoRa module were trimmed afterwards.

10) A toenail cutter is a good tool for this if you have nothing better.

11) Solder the voltage regulator in place (its part number should be on top).

12) Solder the GND pin on the LoRa module to the circuit board, this gives it a ground plane. If you can, you'll want to take that to actual ground. If you want to make a dipole instead, you can, just do the same thing on this pin as for the antenna pin.

13) Insert the battery charger circuit, it should stick out a bit, then solder it.

14) This is what it should look like.

15) Drop the Arduino in, then solder it in place.

16) Time to make an antenna! You'll need a piece of wire. Strip the insulation for it at 82mm (or two if you are doing a dipole).

17) Put the antenna in the the ANT pin hole on the LoRa module up until the insulation, then cut the excess. (For a dipole, do the same with the second piece of wire and the GND pin, facing the other way)

18) This is what it should look like.

19) This is what it looks like from the bottom.

20) Solder the Bluetooth header on, and put the Bluetooth module in as shown. You can use a HC05 or HC06 or compatible. Note that the two outer pins are unused!

21) You can also skip the header and solder the Bluetooth module in place directly. Again note that STATE and EN are unused.

22) You'll have to figure out where you want the header.

23) Time to set up power! This is an old phone battery, a 4.5 to 6 volt solar panel, and some wire.

24) You'll need two +- cables. Strip their ends.

25) Find the + and - terminal on your solar panel. You can connect multiple panels to this IN PARALLEL.

26) Red to + and black to - for the panel(s). Nothing fancy here.

27) Connect those to the IN+ and IN- on the battery charger circuit. Note that you can still charge via USB as long as the panels aren't in direct sunlight when you do.

28) Solder the remaining cable to the battery. If you are recycling a phone battery, letting a solder blob form on the + and - pins will help. Ignore other pins. If you're using a new battery, just connect to that.

29) Unsurprisingly, the battery leads go to B+ and B- also note that this version does not have a power switch (you can add one at the battery). The next version will have a jumper for power.

30) This is what the complete unit looks like. You can flash the Arduino before installing it, or after.

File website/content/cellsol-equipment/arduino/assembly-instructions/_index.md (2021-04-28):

---
publishdate: 2019-11-17
lastmod: 2020-11-24
---

{{< toc >}}

# Arduino Repeater Pylon Setup

Instructions by Kay Borri of Robots Everywhere. Many thanks.

These instructions assume you do not need help flashing the Arduino module using the [firmware](../firmware)

For instructions on what batteries and charging circuits can be added, look at [power supplies](../../power)

For more information refer to the [Schematic](../schematics) and [Bill of Materials](../bom)

## Soldering the Repeater Pylon

These instructions assume that you know how to solder. This project can be attempted by a beginner even though it has some small solder joints.

1) Here are your parts: wire, capacitor, resistor, board, LoRa module, Arduino, voltage regulator, battery charger circuit, headers.

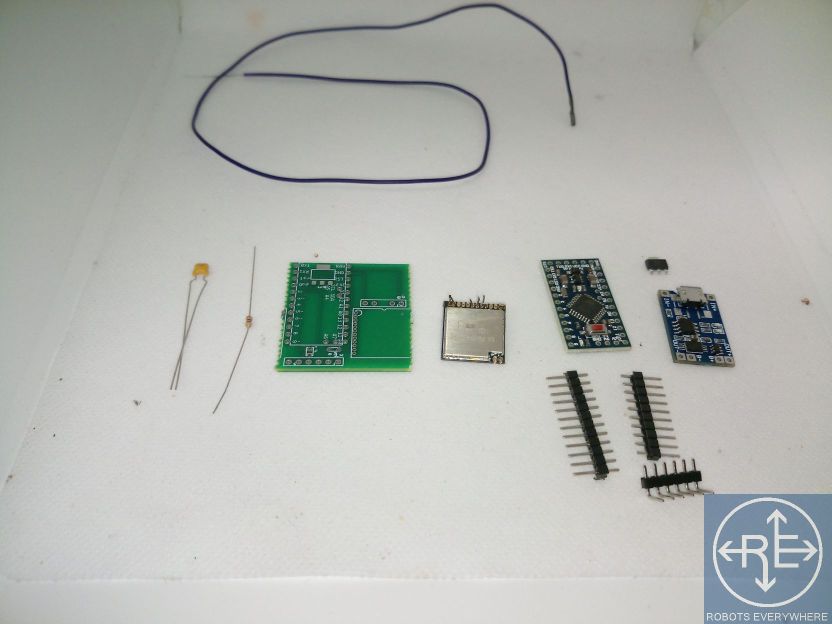
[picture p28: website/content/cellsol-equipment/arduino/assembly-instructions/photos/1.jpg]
Here are your parts: wire, capacitor, resistor, board, LoRa module, Arduino, voltage regulator, battery charger circuit, headers.


2) First, put the capacitor and resistor in their spots on the circuit board, C1 and R1 respectively. They don't have a polarity.

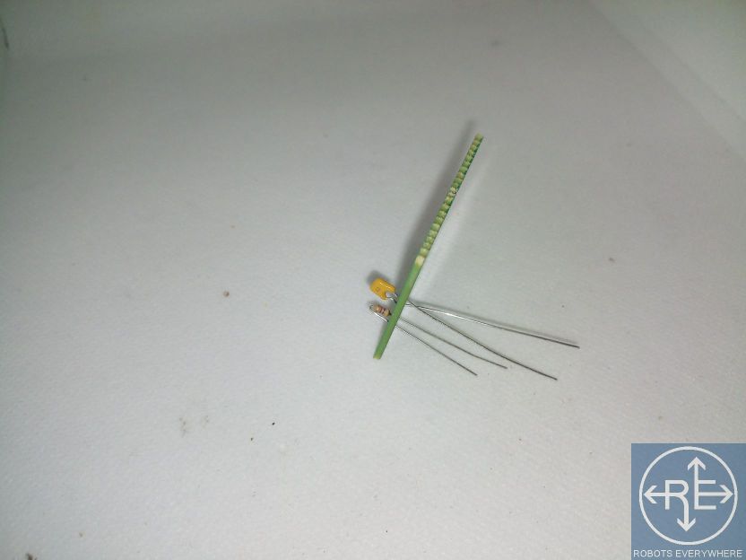
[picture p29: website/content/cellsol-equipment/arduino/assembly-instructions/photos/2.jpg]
First, put the capacitor and resistor in their spots on the circuit board, C1 and R1 respectively. They don't have a polarity.


3) This is what the top of the board should look like. Solder those two parts.

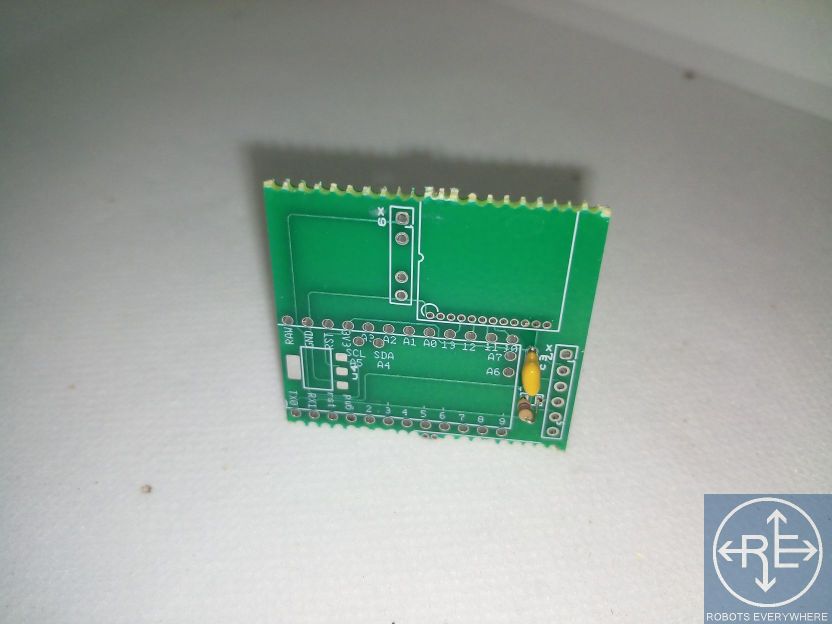
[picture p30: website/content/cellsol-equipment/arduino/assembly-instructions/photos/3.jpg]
This is what the top of the board should look like. Solder those two parts.


4) Cut the extra leads. You'll need it in a bit.

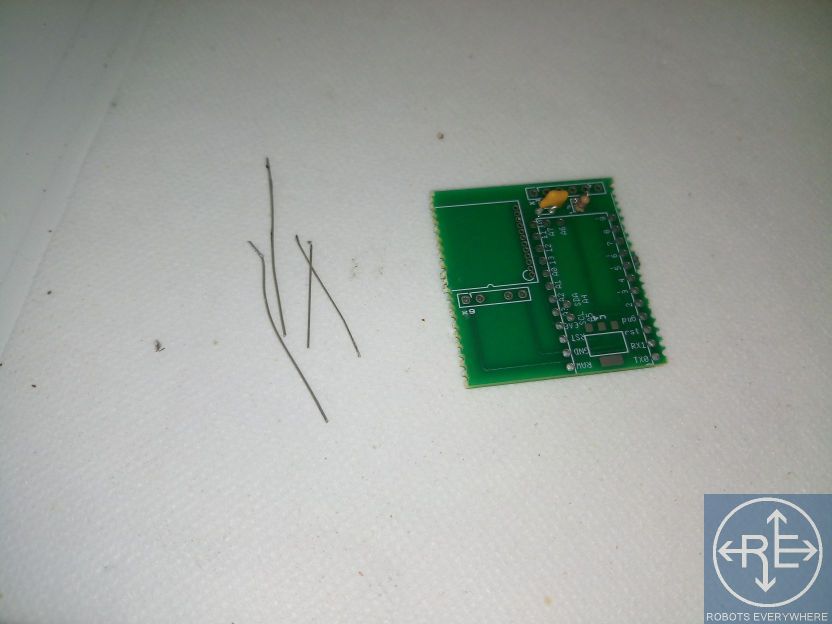
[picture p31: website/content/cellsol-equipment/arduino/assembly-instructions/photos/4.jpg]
Cut the extra leads. You'll need it in a bit.


5) Populate the holes on the LoRa module using the leads, or some wire. If you don't want to do all of them, just do the ones in the picture.

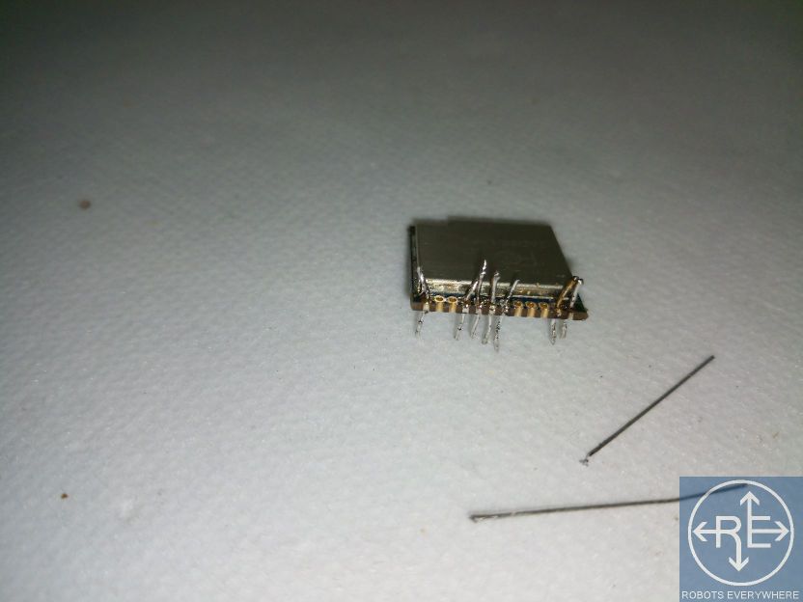
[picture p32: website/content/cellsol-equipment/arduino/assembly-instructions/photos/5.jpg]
Populate the holes on the LoRa module using the leads, or some wire. If you don't want to do all of them, just do the ones in the picture.


6) Stick the LoRa module on top of the circuit board, then solder it in place.

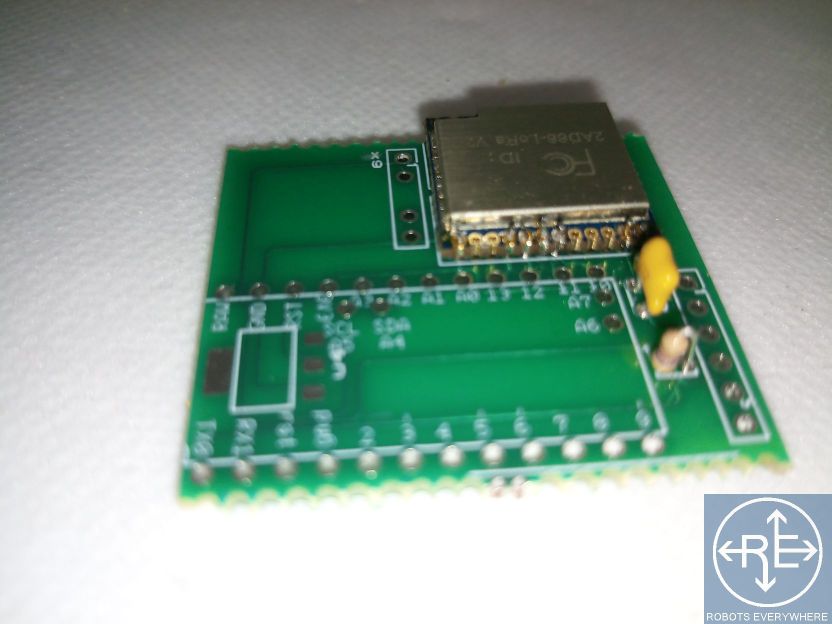
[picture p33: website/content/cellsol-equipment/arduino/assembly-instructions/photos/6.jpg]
Stick the LoRa module on top of the circuit board, then solder it in place.


7) Use the headers and the rest of the leads to prepare the battery charger circuit and the Arduino. Don't fill IN+ and IN- yet. Again, if you want to save header materials you can skip unused holes. 

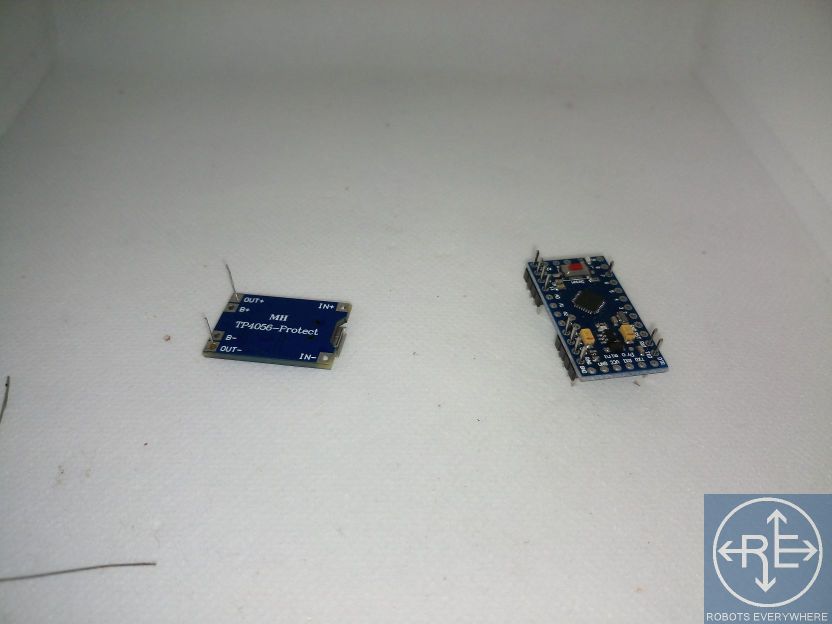
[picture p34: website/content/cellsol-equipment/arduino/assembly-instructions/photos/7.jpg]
Use the headers and the rest of the leads to prepare the battery charger circuit and the Arduino. Don't fill IN+ and IN- yet.


8) A different angle showing what holes you have to populate. Your Arduino may look a bit different. Refer to your Arduino's datasheet.

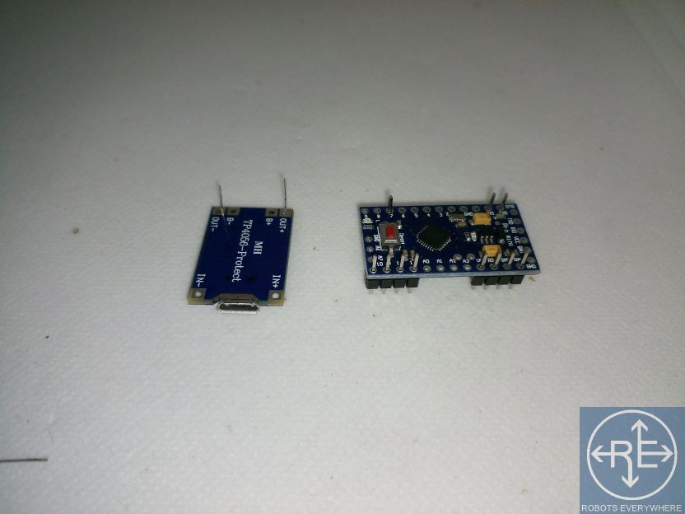
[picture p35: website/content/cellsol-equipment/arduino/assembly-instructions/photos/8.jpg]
A different angle showing what holes you have to populate. Your Arduino may look a bit different.


9) Note where the voltage regulator goes. Also, note how the leads on the LoRa module were trimmed afterwards.

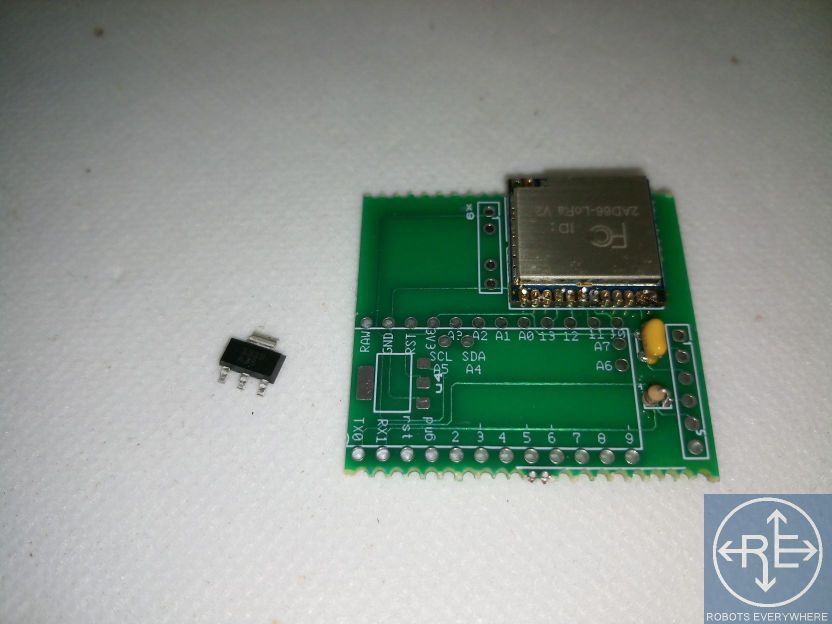
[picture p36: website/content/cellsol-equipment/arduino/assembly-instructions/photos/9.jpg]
Note where the voltage regulator goes. Also, note how the leads on the LoRa module were trimmed afterwards.


10) A toenail cutter is a good tool for this if you have nothing better, such as diagonal snips.

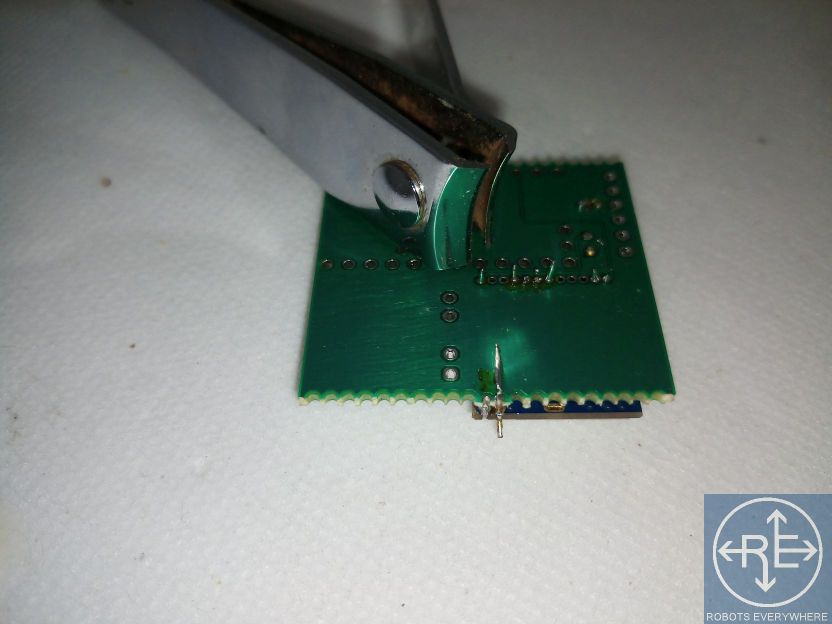
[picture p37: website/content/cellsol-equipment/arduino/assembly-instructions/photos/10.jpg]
A toenail cutter is a good tool for this if you have nothing better.


11) Solder the voltage regulator in place (its part number should be on top).

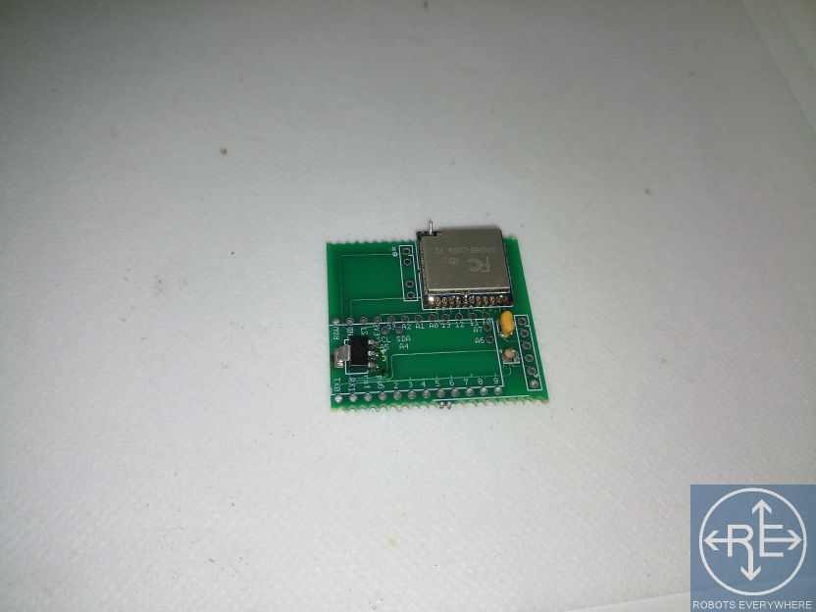
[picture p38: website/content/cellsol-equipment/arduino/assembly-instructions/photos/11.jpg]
Solder the voltage regulator in place (its part number should be on top).


12) Solder the GND pin on the LoRa module to the circuit board, this will act as a rudimentary RF ground plane. If you can, you'll want to connect that to earth ground. Otherwise, use a dipole antenna.

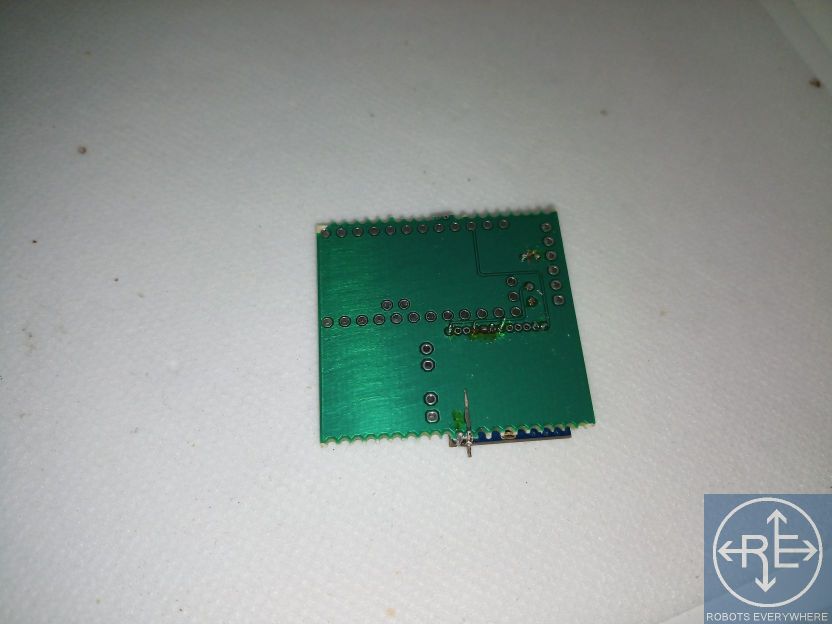
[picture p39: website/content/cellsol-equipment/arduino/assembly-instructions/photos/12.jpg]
Solder the GND pin on the LoRa module to the circuit board, this will act as a rudimentary RF ground plane. If you can, you'll want to connect that to earth ground. Otherwise, use a dipole antenna.


12.5) The arduino node can have a dipole antenna by simply having one wire go up from the ANT pin, one wire go down from the GND pin next to it (they're 1mm apart to not interfere) and use a rigid piece of nonconductive material (plastic) to keep them opposite each other. Wires should be 85mm in length.
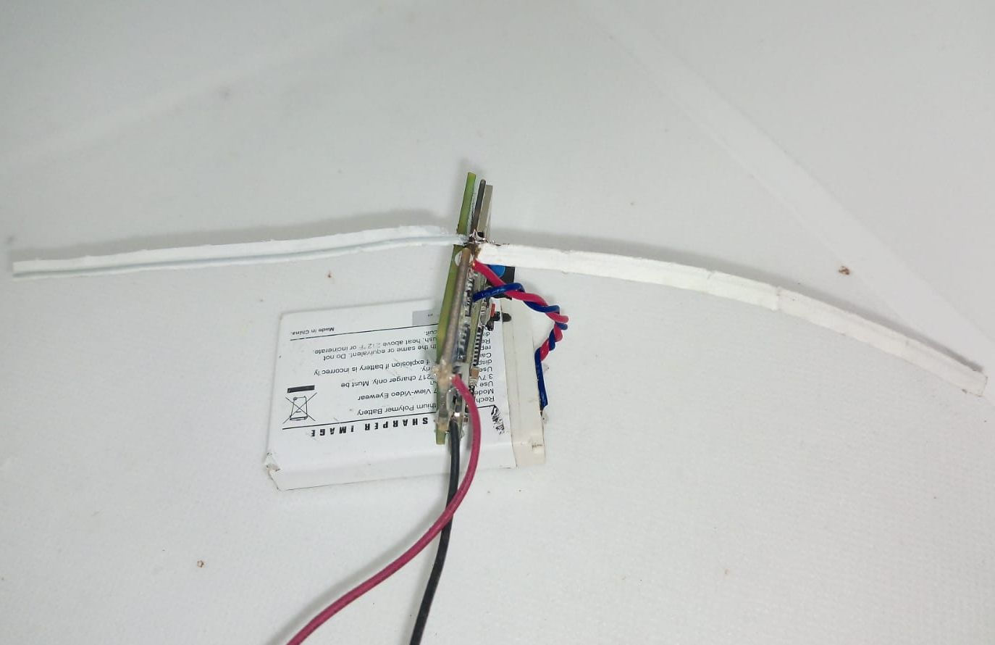
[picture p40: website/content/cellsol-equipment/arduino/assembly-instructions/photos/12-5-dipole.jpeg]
CellSol Arduino Repeater Pylon with a dipole antenna


13) Insert the battery charger circuit, it should stick out a bit, then solder it.

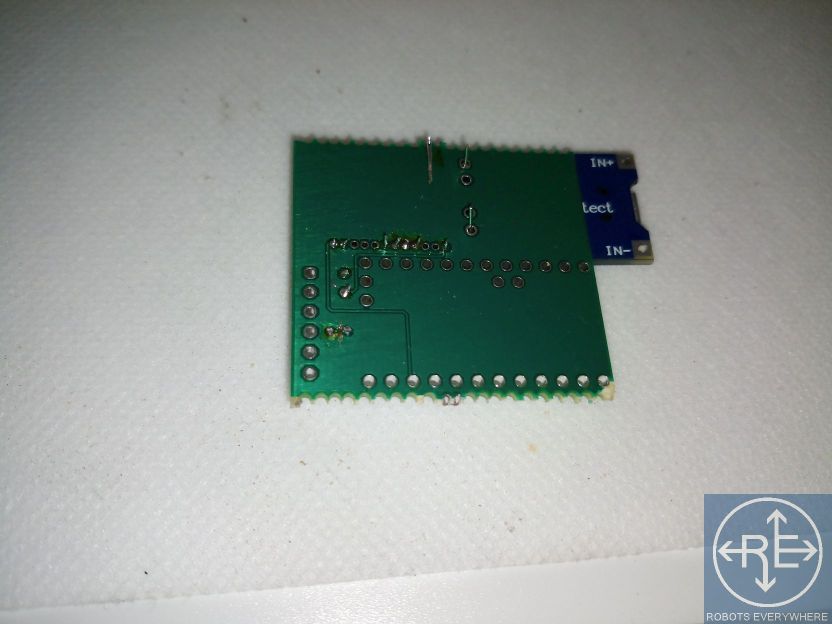
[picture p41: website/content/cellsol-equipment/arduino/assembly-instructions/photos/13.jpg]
Insert the battery charger circuit, it should stick out a bit, then solder it.


14) This is what it should look like.

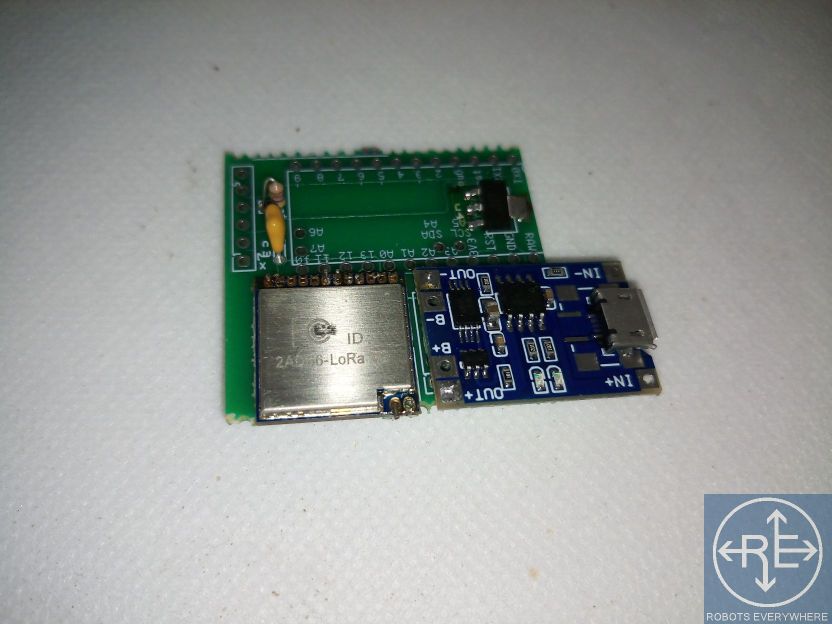
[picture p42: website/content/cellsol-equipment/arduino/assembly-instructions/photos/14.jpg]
This is what it should look like


15) Drop the Arduino in, then solder it in place.

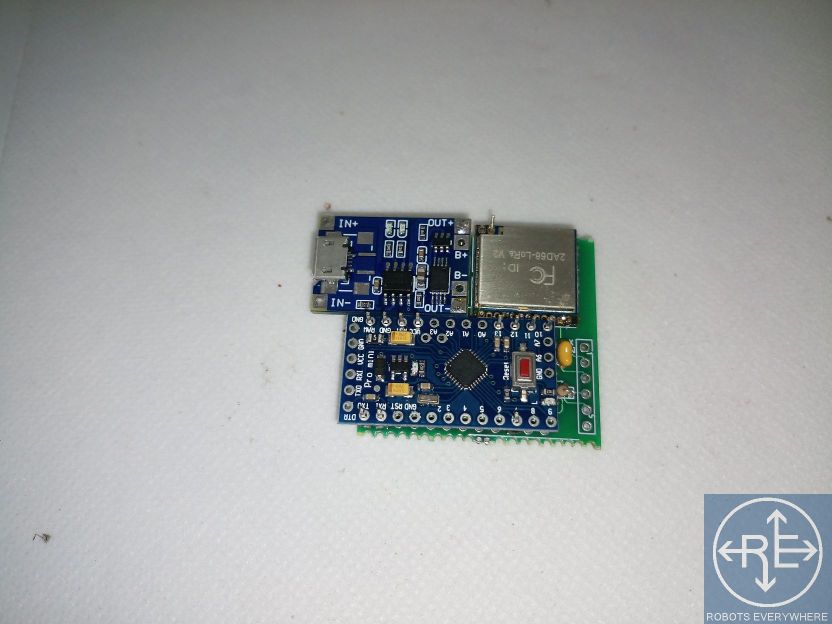
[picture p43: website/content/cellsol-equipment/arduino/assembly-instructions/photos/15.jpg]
Drop the Arduino in, then solder it in place.


16) Time to make an antenna! You'll need a piece of wire. Strip the insulation for it at 82mm (or two if you are doing a dipole).

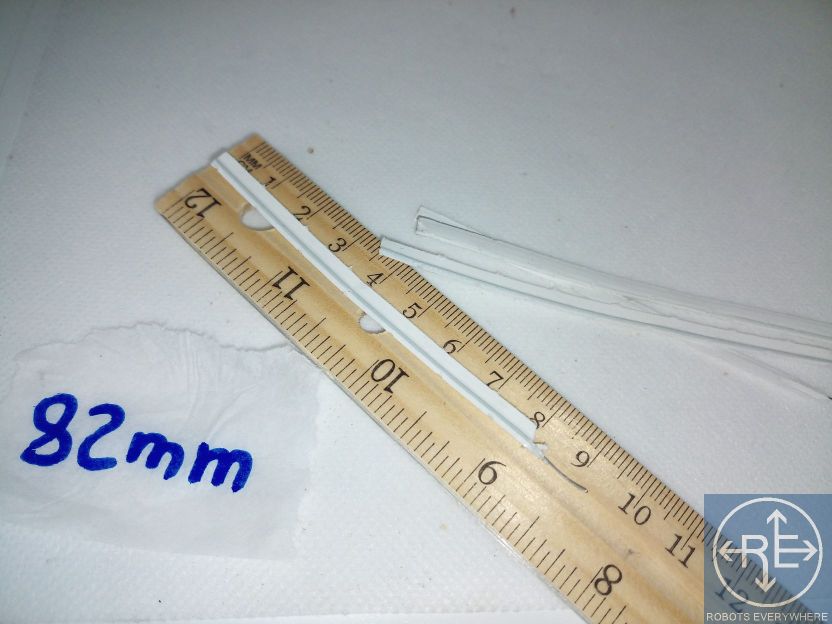
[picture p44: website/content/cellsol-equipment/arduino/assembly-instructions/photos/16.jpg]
Time to make an antenna! You'll need a piece of wire. Strip the insulation for it at 82mm (or two if you are doing a dipole).


17) Put the antenna in the the ANT pin hole on the LoRa module up until the insulation, then cut the excess. (For a dipole, do the same with the second piece of wire and the GND pin, facing the other way)

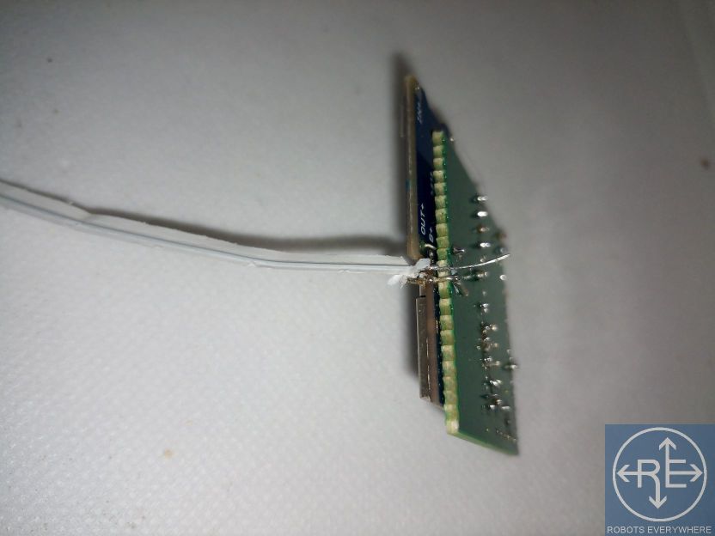
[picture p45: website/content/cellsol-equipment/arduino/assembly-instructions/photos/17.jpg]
Put the antenna in the the ANT pin hole on the LoRa module up until the insulation, then cut the excess. (For a dipole, do the same with the second piece of wire and the GND pin, facing the other way)


18) This is what it should look like.

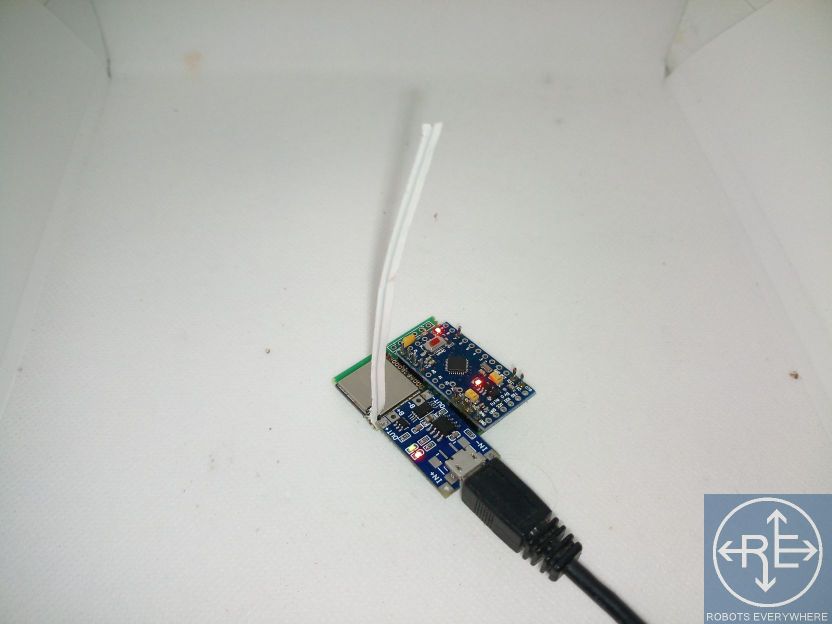
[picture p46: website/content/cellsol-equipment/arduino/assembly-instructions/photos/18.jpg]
This is what it should look like.


19) This is what it looks like from the bottom.

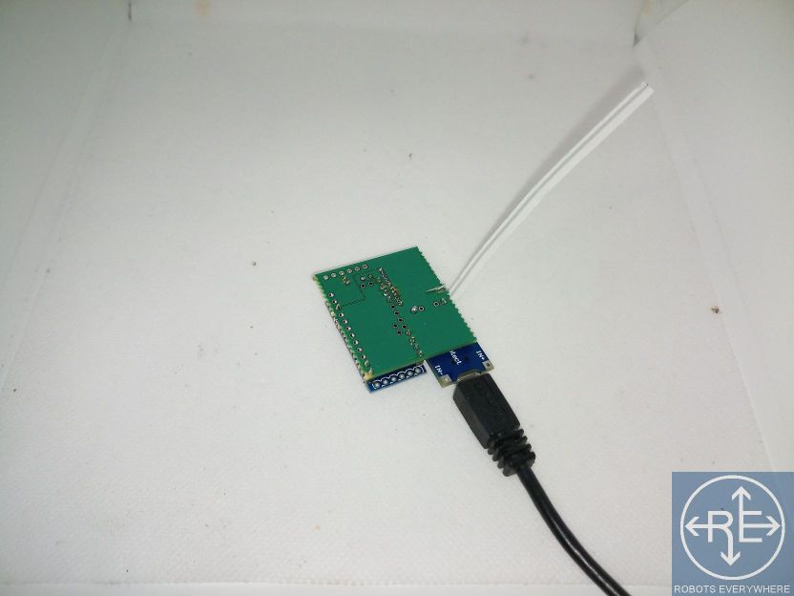
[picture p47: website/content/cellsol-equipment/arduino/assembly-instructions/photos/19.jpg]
This is what it looks like from the bottom.


20) Solder the Bluetooth header on, and put the Bluetooth module in as shown. You can use a HC05 or HC06 or compatible. Note that the two outer pins are unused!

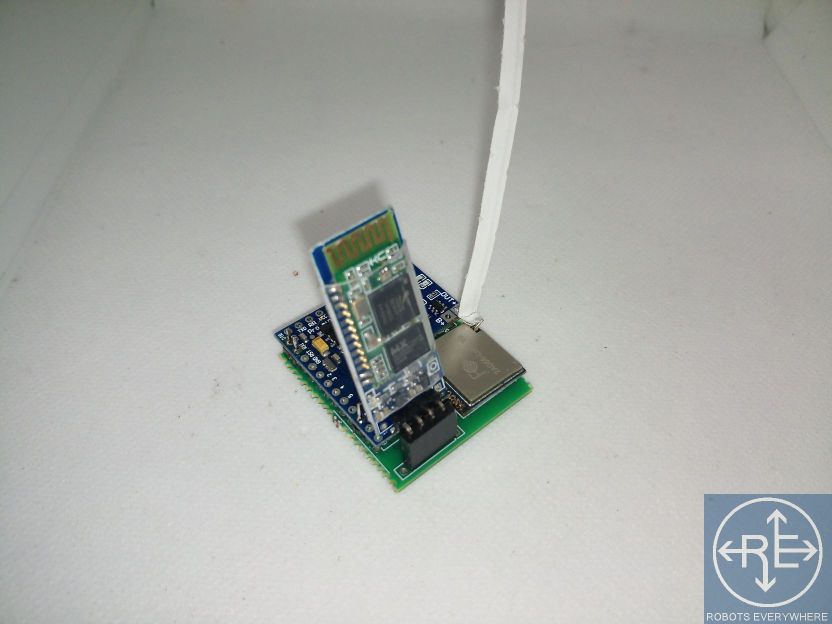
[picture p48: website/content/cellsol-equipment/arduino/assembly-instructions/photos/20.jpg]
Solder the Bluetooth header on, and put the Bluetooth module in as shown. You can use a HC05 or HC06 or compatible. Note that the two outer pins are unused!


21) You can also skip the header and solder the Bluetooth module in place directly. Again note that STATE and EN are unused.

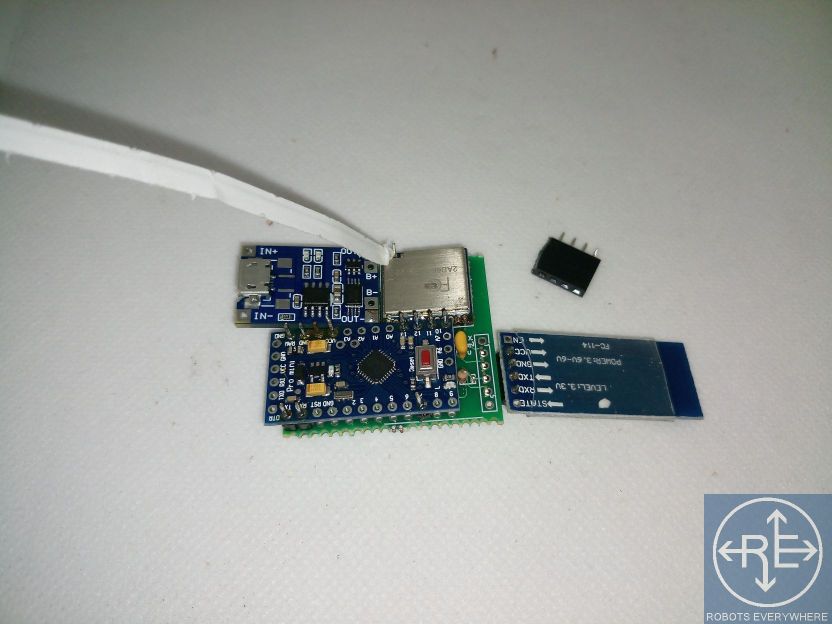
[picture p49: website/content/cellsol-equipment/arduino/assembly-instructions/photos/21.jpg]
You can also skip the header and solder the Bluetooth module in place directly. Again note that STATE and EN are unused.


22) You'll have to figure out where you want the header.

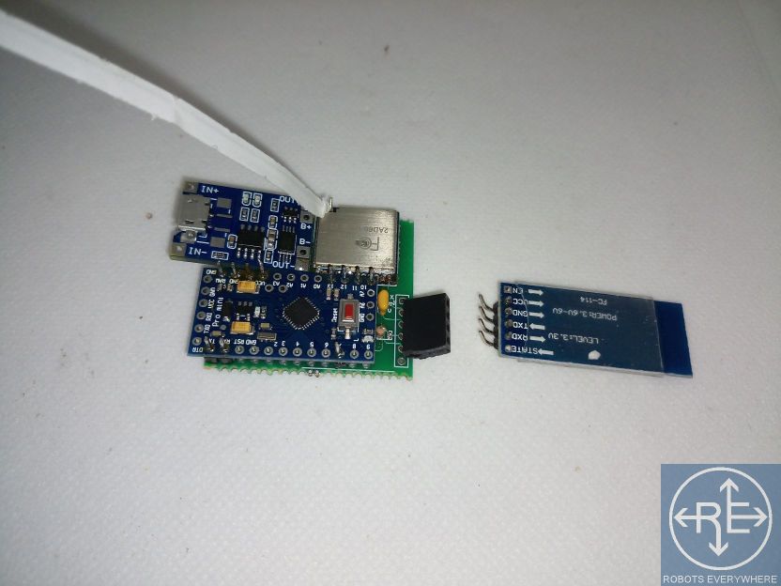
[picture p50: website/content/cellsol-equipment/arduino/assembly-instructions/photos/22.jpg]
You'll have to figure out where you want the header.


23) Time to set up power! This is an old phone battery, a 4.5 to 6 volt solar panel, and some wire.

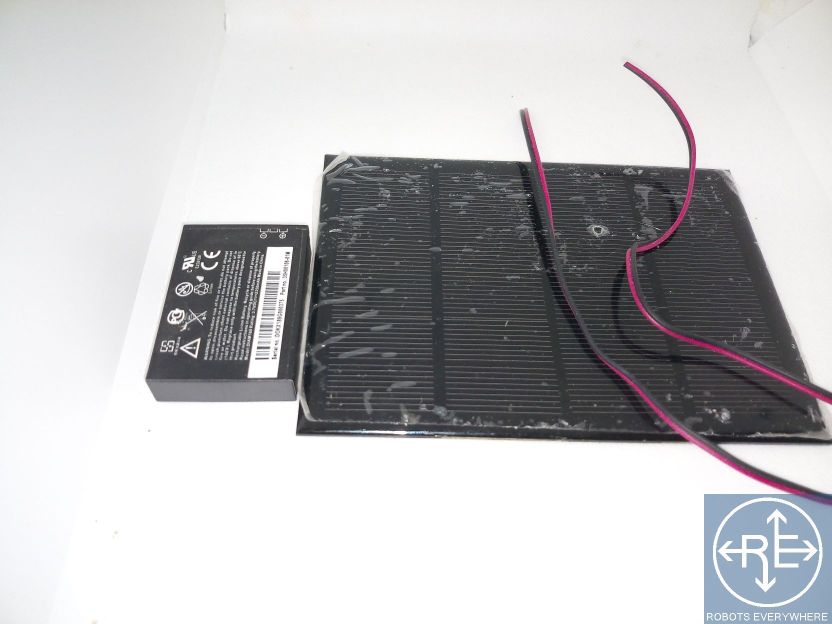
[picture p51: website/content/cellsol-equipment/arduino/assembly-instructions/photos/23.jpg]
Time to set up power! This is an old phone battery, a 4.5 to 6 volt solar panel, and some wire.


24) You'll need two +- cables. Strip their ends.

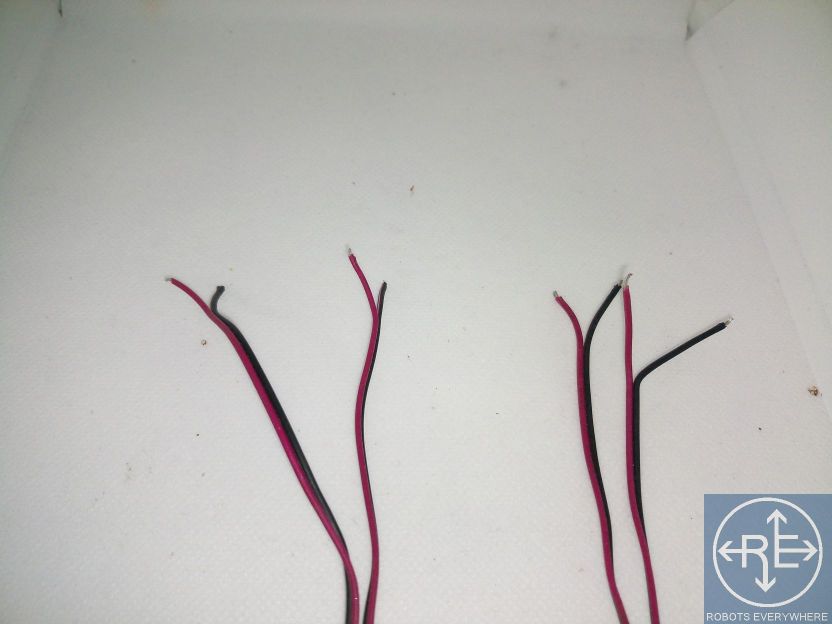
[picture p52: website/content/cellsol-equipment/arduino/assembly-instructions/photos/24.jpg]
You'll need two +- cables. Strip their ends.


25) Find the + and - terminal on your solar panel. You can connect multiple panels to this IN PARALLEL.

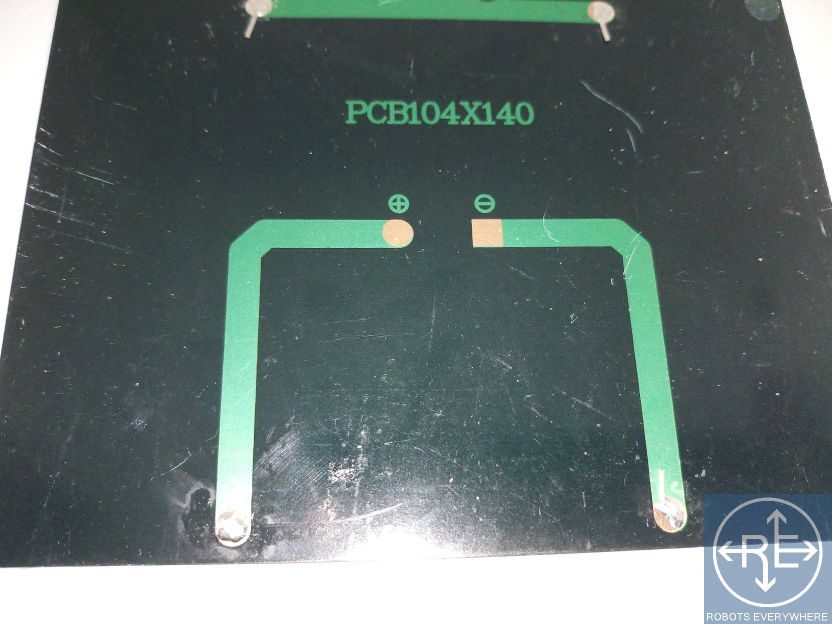
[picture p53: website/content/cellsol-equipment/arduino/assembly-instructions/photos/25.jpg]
Find the + and - terminal on your solar panel. You can connect multiple panels to this IN PARALLEL.


26) Red to + and black to - for the panel(s). Nothing fancy here.

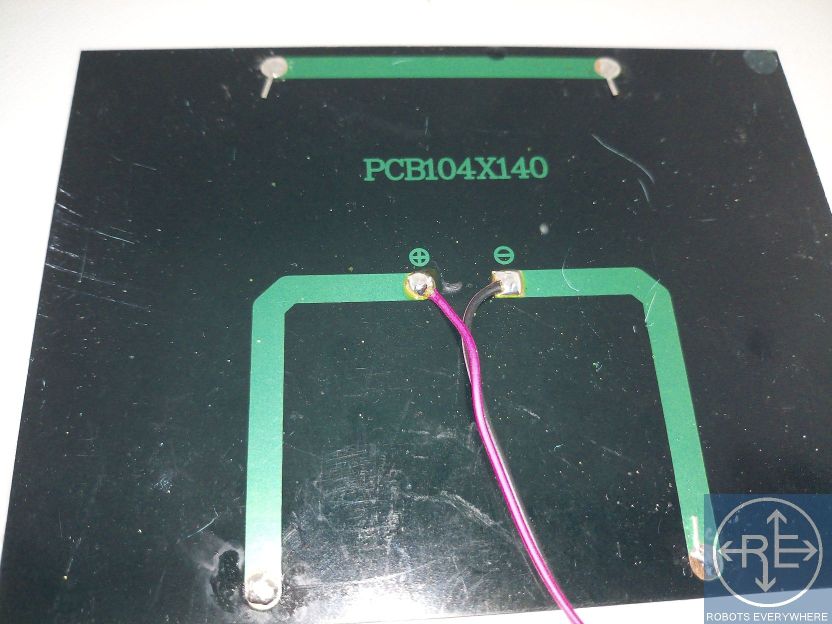
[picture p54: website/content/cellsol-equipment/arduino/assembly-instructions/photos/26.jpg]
Red to + and black to - for the panel(s). Nothing fancy here.


27) Connect those to the IN+ and IN- on the battery charger circuit. Note that you can still charge via USB as long as the panels aren't in direct sunlight when you do.

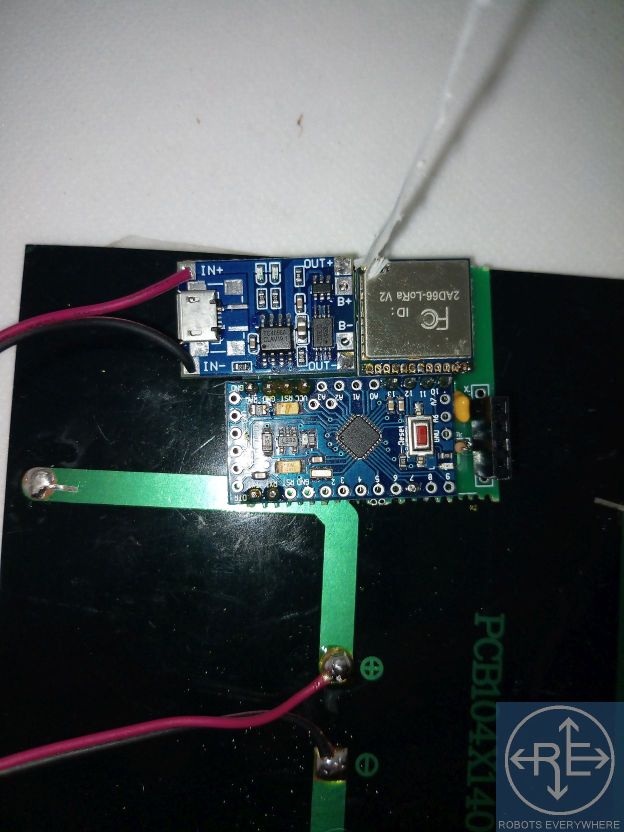
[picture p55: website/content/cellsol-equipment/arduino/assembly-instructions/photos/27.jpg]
Connect those to the IN+ and IN- on the battery charger circuit. Note that you can still charge via USB as long as the panels aren't in direct sunlight when you do.


28) Solder the remaining cable to the battery. If you are recycling a phone battery, letting a solder blob form on the + and - pins will help. Ignore other pins. If you're using a new battery, just connect to that.

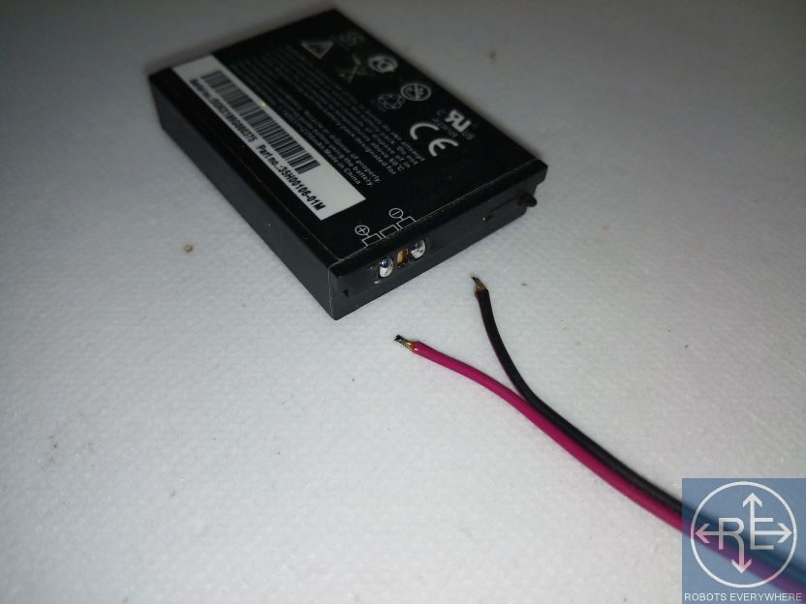
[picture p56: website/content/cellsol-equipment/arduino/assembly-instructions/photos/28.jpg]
Solder the remaining cable to the battery. If you are recycling a phone battery, letting a solder blob form on the + and - pins will help. Ignore other pins. If you're using a new battery, just connect to that.


29) Unsurprisingly, the battery leads go to B+ and B- also note that this version does not have a power switch (you can add one at the battery). The next version will have a jumper for power.

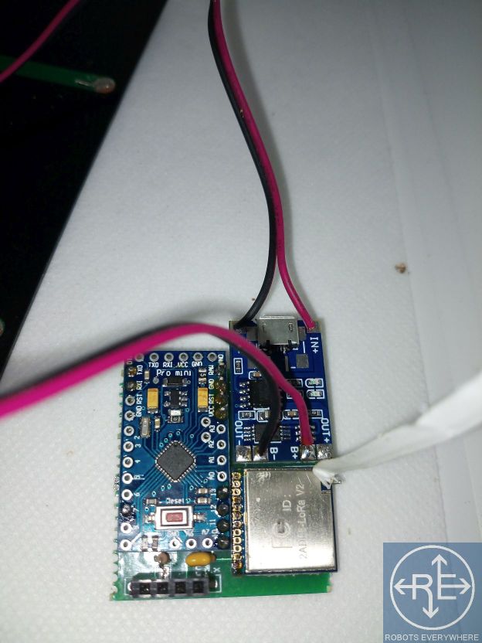
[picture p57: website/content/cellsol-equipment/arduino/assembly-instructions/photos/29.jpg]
Unsurprisingly, the battery leads go to B+ and B- also note that this version does not have a power switch (you can add one at the battery). The next version will have a jumper for power.


30) This is what the complete unit looks like. You can flash the Arduino before installing it, or after.

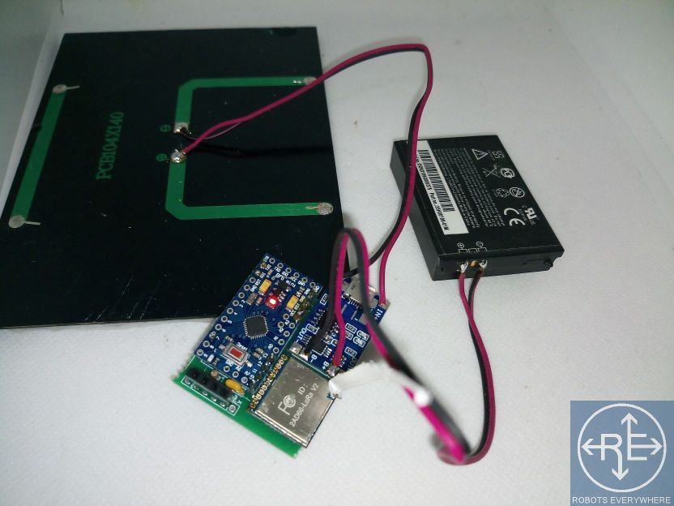
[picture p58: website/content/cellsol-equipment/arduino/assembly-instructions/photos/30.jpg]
This is what the complete unit looks like. You can flash the Arduino before installing it, or after.


## Using the Antenna Cutting Guide (optional)

The antenna cutting guide is exactly 85mm in length; while the antenna inside the case DOES in fact also resonate, it resonates slightly less, and due to the small size of the case, 85mm is "close enough". A short wire is not going to give you precisely tuned performance at any rate.

Please remember that this is a monopole antenna, and the RF ground pin on the pylon needs to be connected to earth ground for it to work effectively.

1. You will need the antenna cutting guide (3D printable, and available as part of the [Arduino Repeater Pylon case on thingiverse](https://www.thingiverse.com/thing:4660194) and a short length of 20 gauge stranded copper wire. It also helps to have some tape to hold the wire in place.
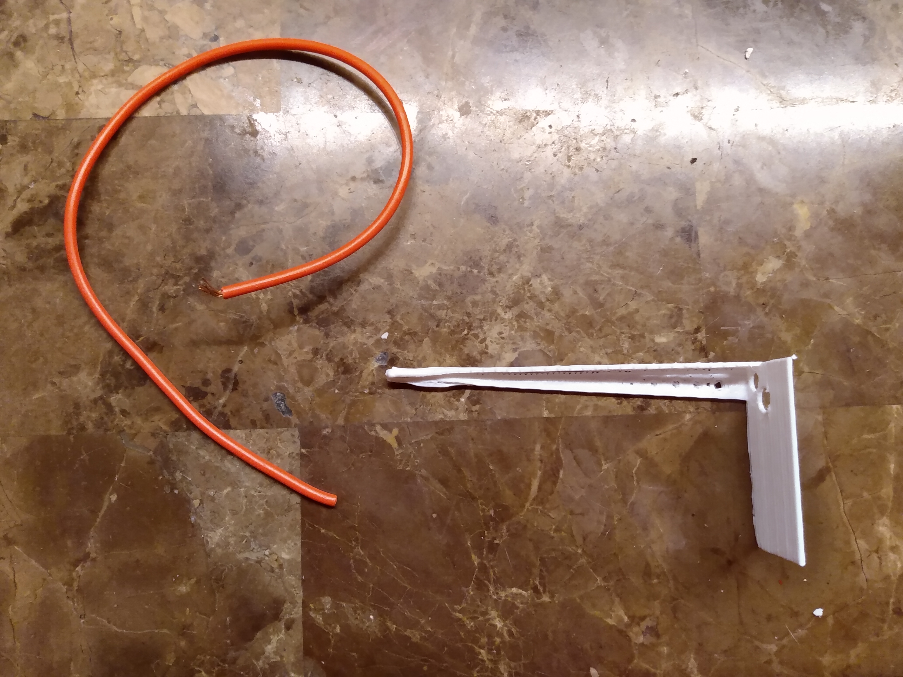
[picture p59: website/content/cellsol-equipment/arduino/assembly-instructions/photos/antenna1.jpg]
A length of 20 gauge stranded copper wire next to the CellSol Arduino Repeater Pylon Antenna Cutting Guide

2. Put the wire through the hole in the antenna cutting guide.
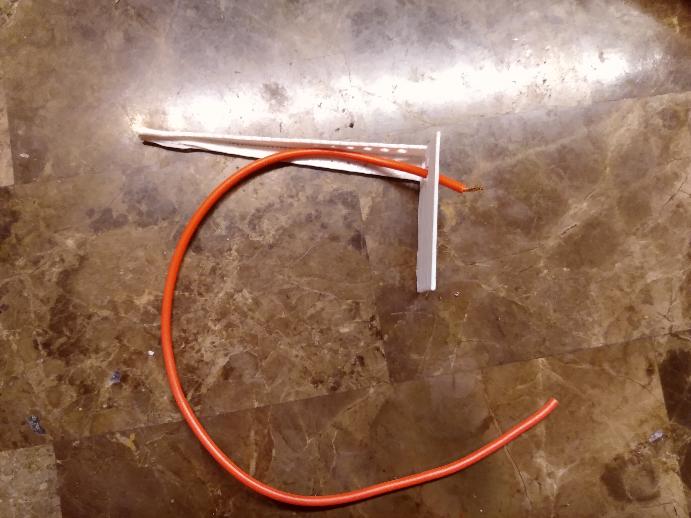
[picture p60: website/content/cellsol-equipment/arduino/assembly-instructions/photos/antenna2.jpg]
A length of 20 gauge stranded copper wire slotted into to the CellSol Arduino Repeater Pylon Antenna Cutting Guide

3. Tape the wire in place, so that it doesn't move.
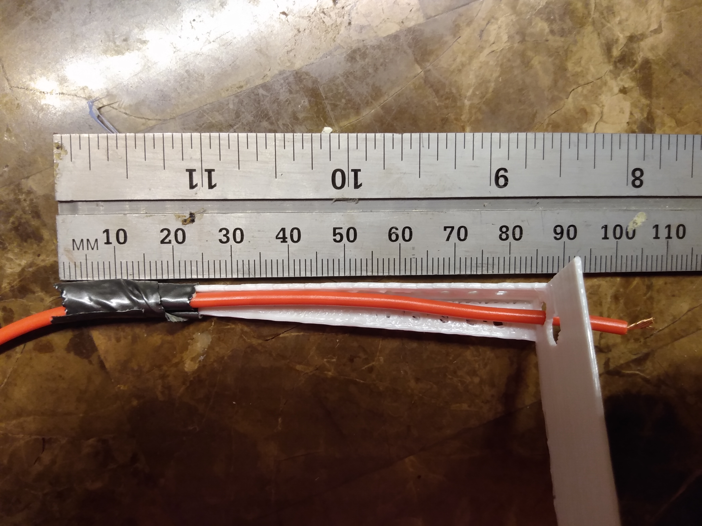
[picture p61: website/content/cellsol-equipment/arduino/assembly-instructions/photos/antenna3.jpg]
CellSol Arduino Repeater Pylon Antenna Cutting Guide with antenna wire taped in place, before cutting

4. Cut the wire to the rough 85mm length.
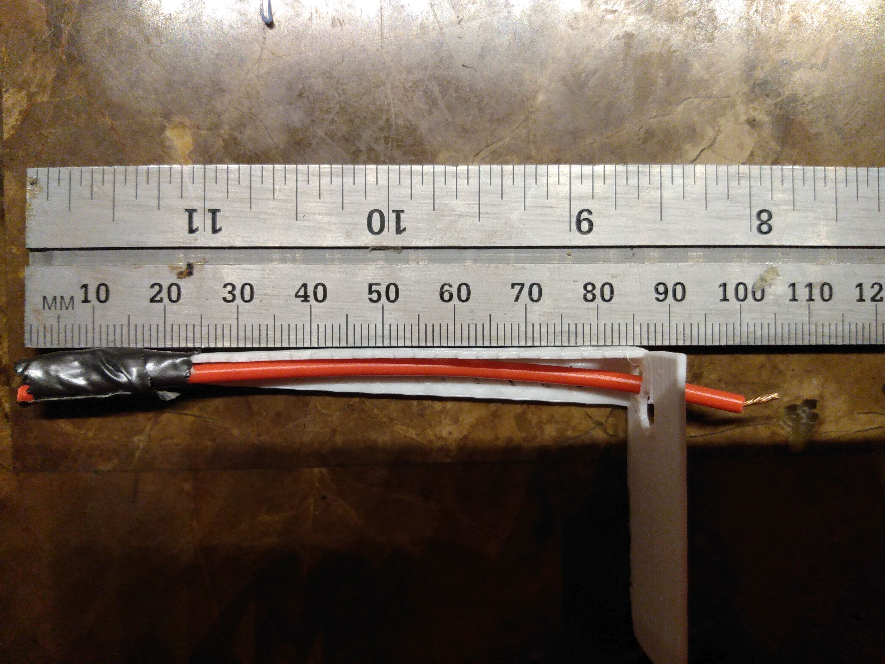
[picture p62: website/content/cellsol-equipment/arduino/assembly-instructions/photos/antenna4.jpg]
CellSol Arduino Repeater Pylon Antenna Cutting Guide with antenna wire taped in place, after cutting


## Installing the Firmware

If you are not using a pre-flashed Arduino Nano, you will need to install the firmware. Using either the USB port on the Arduino
(if any) or a USB FTDI programmer (if no USB port), connect it to your computer. After connecting it, load the firmware using
the Arduino IDE, and install the required libraries:

* LoRa
* Arduino LowPower
* SPI
* Unique ID

If you encounter other library errors, please ensure you have the core libraries for the Nano installed. All of these libraries
can be installed via the IDE's Library Manager.

## Verifying Assembly and Firmware

Once you have loaded the firmware on the repeater and given it power, the red LED on pin 13 should stay on continuously, at low
brightness. When a message is received on the CellSol frequency, it will blink once, retransmit, and then resume low brightness.

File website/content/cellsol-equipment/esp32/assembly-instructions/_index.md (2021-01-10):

---
publishdate: 2019-11-17
lastmod: 2020-11-24
---

# CellSol ESP32 WiFi Pylon Setup

The WiFi pylon setup does not require soldering or any electronics expertise, though being able to solder the battery connection will improve the robustness of the device and make it more weatherproof.

For more detailed information refer to the [Schematic](../schematics) and [Bill of Materials](../bom)

{{< toc >}}

## What You Will Need
* A Heltec Lora32 or Lora32v2 module
* The Arduino software, available [here](https://www.arduino.cc/en/Main/Software)
* A Micro USB cable for your Lora32
* Our CellSol ESP32 Pocket Pylon firmware, available on the [GitHub repository](https://github.com/RbtsEvrwhr-Riley/CellSol)
* 1.2V batteries (the bigger the better) OR, any 3.6 or 3.7 volt battery (li-ion, lipo, etc.) See [Powering the Node](power). If you're not sure, use 3 AA batteries.
* Battery holder for your chosen batteries (if necessary).
* Battery connector for the Lora32 module (should come with the Lora32)
* A 5V solar panel to charge the battery (optional, USB may also be used for charging with a 5V cell phone adapter or a computer)
* A case for your Lora32, antenna, and battery - see this website for [case designs](../case-designs)
* Some means of connecting wires together; soldering is ideal, but crimp connectors or a roll of tape will work in an emergency.

## References

Arduino: https://www.arduino.cc
Lora32: https://heltec.org/project/wifi-lora-32/

## Step 1: Setting Up the Arduino Software

### 1.1 Board Manager
To program your Lora32, you will need to have the board manager in the arduino software configured to support it. You will also need to install several arduino libraries used by our firmware.

You will need to add a URL to the Board Manager before starting. In the Arduino software, navigate to File -> Preferences... and in the dialog box, click the browse icon next to "Additional Board Manager URLs". In the text box that opens, add a new line, and enter the following URL:
[https://dl.espressif.com/dl/package_esp32_index.json](https://dl.espressif.com/dl/package_esp32_index.json)

{{< figure src="./photos/fig1_boardmanagerurls.png" title="Board Manager URLs After Adding Espressif ESP32" >}}

Once this URL is added, you can go on and add the Lora32 boards using the Board Manager.

Navigate to Tools -> Board -> Boards Manager...

Enter "Heltec" in the search, and "Heltec ESP32 Series Dev-Boards" should appear. Click "Install" at the bottom right. Once installed, this button will be replaced by "Remove".

{{< figure src="./photos/fig2_boardmanager.png" title="Board Manager After Installing Heltec ESP32" >}}

### 1.2 Libraries

With the boards configured, it is on to configuring the libraries. Navigate to Tools -> Manage Libraries...

A window similar to the Board Manager will open.

{{< figure src="photos/fig3_librarymanager.png" title="Arduino Library Manager" >}}

You will need to search for the following libraries, and, just like installing the boards in Board Manager, install them:
* Adafruit BusIO
* Adafruit GFX Library
* Adafruit SSD1306
* Heltec ESP32 Dev-Boards
* LoRa (by Sandeep Mistry)

{{< figure src="photos/fig4_librarymanager_lora.png" title="LoRa Library - be sure to select the correct one!" >}}

## Step 2: Setting Up the Lora32 for Programming

With the Lora32 unplugged from your computer, navigate to Tools -> Port and look at the serial ports listed there.

Now, plug in your Lora32 using the USB cable. Your operating system should automatically detect it as a serial port, and configure that port. If it does not, refer to your operating system's documentation; but
it is most likely your Lora32 or your USB cable is defective. Try another one.

Navigate again to Tools -> Port. A new one should have appeared: this will be the serial port for the Lora32 you just plugged in. Click on it to select it for programming.

You also need to tell the arduino software that it is using a Lora32 or 32V2. Do this by again navigating to Tools -> Board -> Heltec ESP32 Arduino and selecting Lora32 (black board) or Lora32V2 (white board) depending on which one you are using.

{{< figure src="photos/fig5_selectlora32.png" title="Selecting the Lora32 Board" >}}

The other settings for the Lora32 board can be left default; even if you are not in the EU, the REGION setting is not used by the firmware.

## Step 3: Configuring the Firmware

There are several firmware settings you will need to choose in order to get the performance you want out of your pocket pylons.

If you have not already done so, open the firmware's Arduino project in the Arduino IDE you downloaded, using File -> open, or using your system's file manager. In either case, the file you open is the "esp32_wifi_bt.ino" that you downloaded at the beginning.

All of these options are configured in #define lines in the configuration file "config.h", which will open in a tab at the top of the window.

Most of these options are turned on and off by commenting (making the line begin with //) or uncommenting (removing the //) the #define statements. The options you must set to make your pocket pylon work are explained below. The options not described are intended for developers, for more advanced configuration - you don't have to worry about them right now.

|Option Name|Purpose|Allowed Values|
|---|---|---|
|WIFI_IS_CLIENT|Activates wifi gateway mode if uncommented. This connects the CellSol network to a wifi router.|None|
|WIFI_IS_HYBRID|Activates wifi hybrid mode if uncommented (gateway + AP). Takes priority over WIFI_IS_CLIENT.|None|
|DHCP|Uses DHCP for connecting to an upstream router (gateway or hybrid mode) if uncommented|None|
|REPEATER_ONLY|Emulates the Arduino repeater, turning off the wifi features entirely, if uncommented. Takes priority over everything.|None|
|CLIENT_IP_ADDR|Client IP address, with the numbers separated by commas; only used in IS_CLIENT or IS_HYBRID and only if DHCP is off.|An IP address separated by commas such as 192,168,1,55|
|GATEWAY_IP_ADDR|IP address of the gateway router, with the numbers separated by commas; only used in IS_CLIENT or IS_HYBRID and only if DCHP is off.|An IP address separated by commas such as 192,168,1,1|
|GATEWAY_SUBNET|Subnet mask for the gateway router, with the numbers separated by commas; only used in IS_CLIENT or IS_HYBRID and only if DCHP is off.|An IP subnet mask separated by commas such as 255,255,255,0|
|WIFI_UPSTREAM_AP|The access point name to be connected to if in IS_CLIENT or IS_HYBRID mode.|Network name in double quotes, like "RobotsEverywhere_24"|
|WIFI_UPSTREAM_PWD|The password to the access point to connect to in client or hybrid mode|Password in double quotes, like "derpderp"|
|SSIDROOT|The root SSID for the access point served by the pylon, if in AP or Hybrid mode|Network name in double quotes, like "RobotsEverywhere_24"|

There are more options, but they are not required for setup, and are described in the comments of the "config.h" file. If you have questions, reach out to us on [GitHub]() or [by email](mailto:cellsol@robots-everywhere.com)

## Step 3.5: Configuring IRC Connectivity

As of Beta 0.3, the CellSol firmware will connect to an IRC server by default and begin relaying messages to the wider web, so that other CellSol nodes
can pick them up. If you don't want to use this functionality, or want to create a smaller subnet, this section will also explain how to do that.

In the "config.h" file, you will find a comment block for "irc relay stuff" - this section has configuration options for connecting to IRC.

If you wish to turn off IRC functionality entirely, comment out the line #define IRC_SERVER by putting // in front of it.

|Option Name|Purpose|Default|
|IRC_SERVER|URL or IP of IRC server to connect to|irc.rizon.net|
|IRC_PORT|Port to use to connect to the IRC server|6667 (default for IRC)|
|IRC_NICK_ROOT|Prefix for the nickname this relay will use on IRC|CellSol|
|IRC_CHAN_ROOT|Prefix for the channel name this relay will use (or create) on IRC|CellSol|
|IRC_CHAN_HEXTAG|If defined, add hextag to the IRC channel name as well as the nickname|Off (commented out)|
|FWD_PREFIX|Only forward messages from IRC that start with this prefix to this relay|~~|
|ALLOW_PYLON_FORWARD|If this is defined, messages from other pylons will always be forwarded even without the prefix|On|
|IRC_FAILED_TRE|Number of connection attempts to IRC before failing and disabling IRC until restart|9|
|IRC_TOPIC|Message to use as the channel topic when creating a new IRC channel|(long, see code)|
|USE_BATTERY_NOISE_FOR_ID|If defined, use battery noise to determine the relay's hex tag; if undefined, hex tag will persist across restarts|On|
|DO_NOT_LOG_SYSTEM_PACKETS|If defined, don't display system packets to avoid spamming out human messages (example: UTC fix)|On|

For more on using IRC, refer to the [User Guide]({{< ref "/about-cellsol/user-guide" >}}User Guide).

## Step 4: Assembling the Hardware

These instructions assume that you don't have any tools. If you have a soldering iron and wire cutters and better tape and/or heat shrink, you should clearly use them, but if you can do that, you don't really need these instructions...

1. This is what you need to assemble the full kit, in an emergency:
* ESP32 module with antenna
* Tape roll and/or double sided tape. Electrical tape or heatshrink tubing can be used to improve the build.
* USB solar panel
* Battery holder
* 1.2V batteries (the bigger the better) OR, any 3.6 or 3.7 volt battery (li-ion, lipo, etc.)

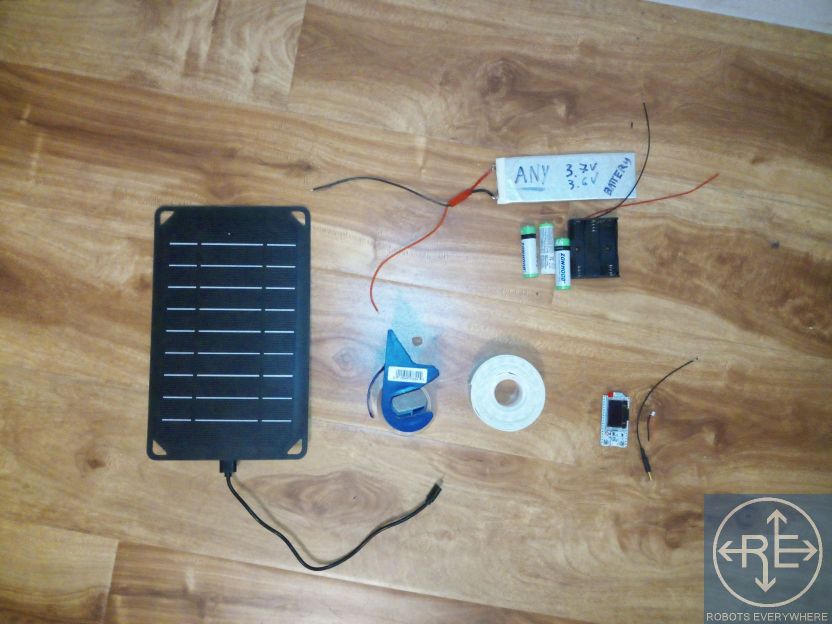
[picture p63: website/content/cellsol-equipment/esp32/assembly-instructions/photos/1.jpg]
What you need to assemble an ESP32 WiFi Pylon


2. First thing first: check that the esp32 module is undamaged. Make sure the battery plug, USB port, and the screen are all there and attached. Make sure there are no deep cuts into the circuit board.
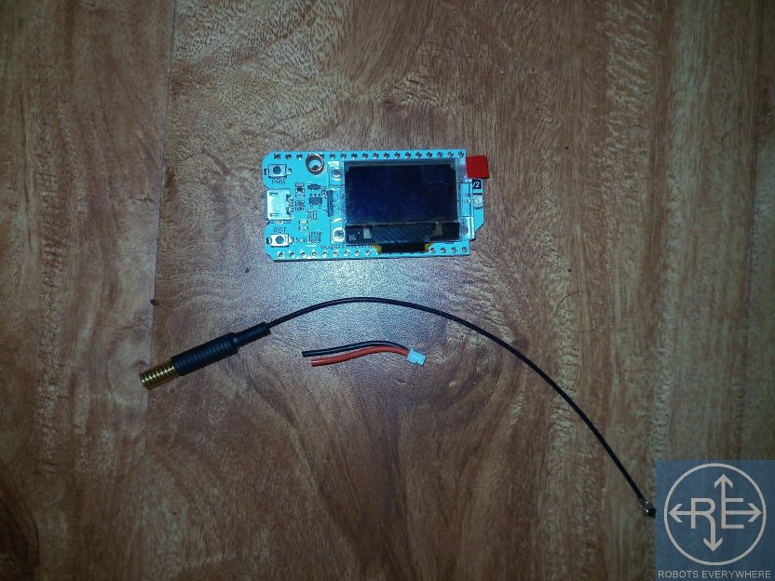
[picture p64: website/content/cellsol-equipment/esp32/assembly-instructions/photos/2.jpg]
First thing first: check that the esp32 module is undamaged.


3. Connect the antenna - you'll have to carefully push down the U.FL connector. Make sure it is properly lined up - it takes a BIT of force, not a lot.
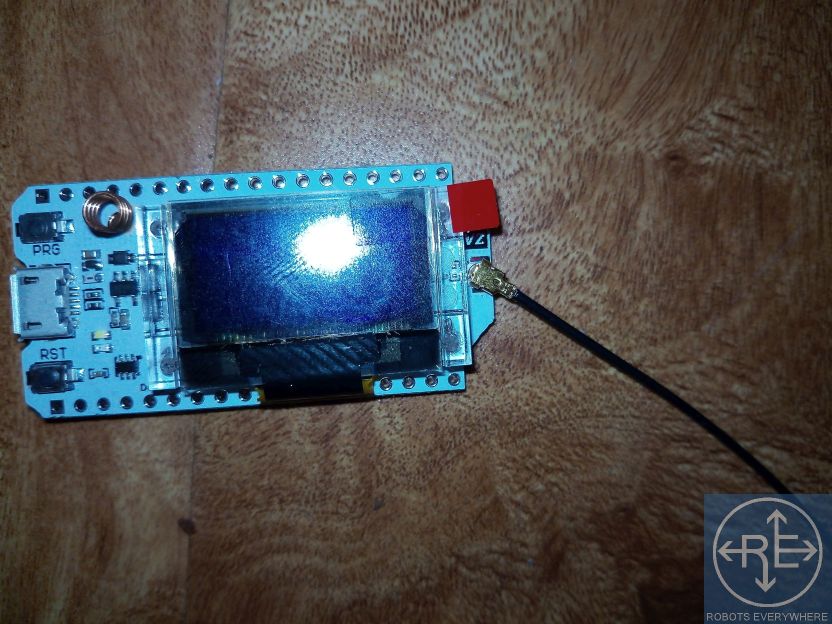
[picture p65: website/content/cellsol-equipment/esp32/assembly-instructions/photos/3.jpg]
Connect the antenna - you'll have to carefully push down the UFL connector.


4. Strip the wires for the battery case. You can use the tape roll if you have nothing better. 1.5cm or half an inch is sufficient.
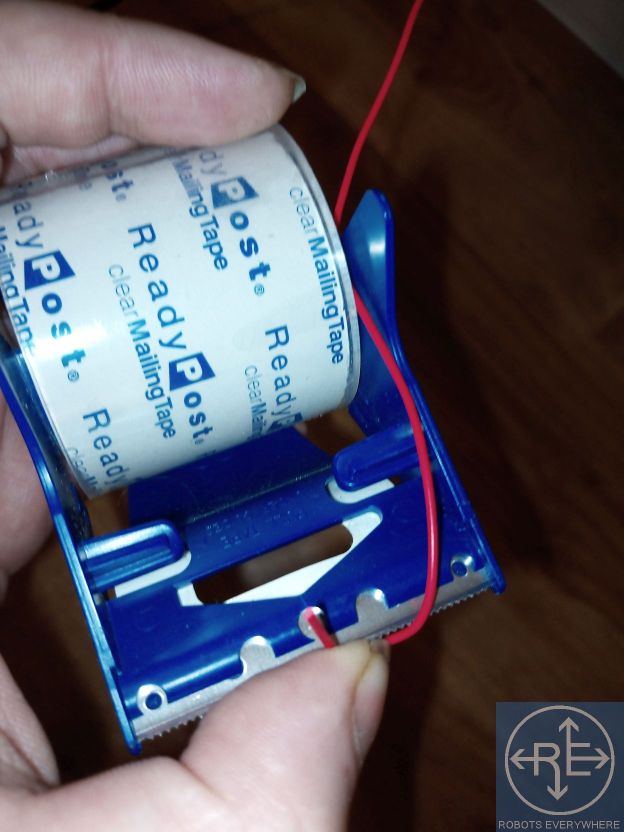
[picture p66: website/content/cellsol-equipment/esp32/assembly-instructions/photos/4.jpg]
Strip the wires for the battery case. You can use the tape roll if you have nothing better. 1.5cm or half an inch is sufficient.


5. This should be your end result.
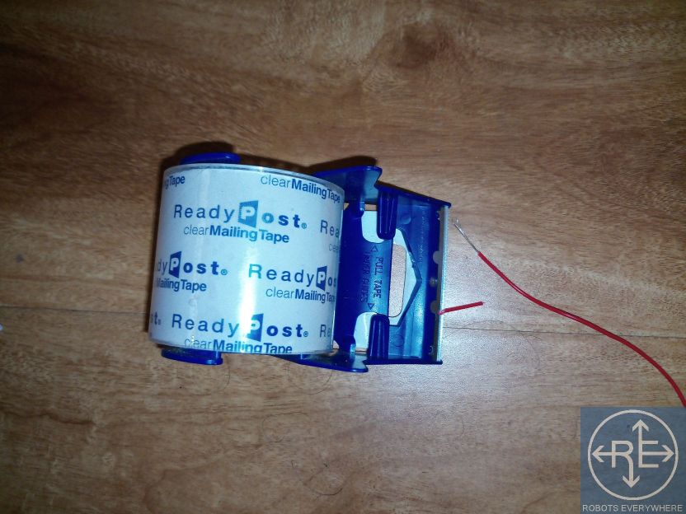
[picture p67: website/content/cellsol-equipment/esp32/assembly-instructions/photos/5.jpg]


6. Do the same with the wires that came with the esp32 module.
Do the same with the wires that came with the esp32 module.

7. This should be your end result.
This should be your end result.

8. You have to connect these red to red and black to black.
You have to connect these red to red and black to black.

9. Twist the wires together, bending them backwards afterward. If you can solder, solder these wires together and skip steps 10 through 12.
Twist the wires together, bending them backwards afterward.

10. Using the tape, cover one wire (Doing black here). Make sure you cover it fully. 
Using the tape, cover one wire (Doing black here). Make sure you cover it fully.

11. Using the tape, cover the other. Make sure you cover it fully. Leave some tape hanging.
Using the tape, cover the other. Make sure you cover it fully. Leave some tape hanging.

12. Use the tape you left hanging earlier to wrap around your connection. It doesn't look pretty, but it will hold for a long time.
Use the tape you left hanging earlier to wrap around your connection. It doesn't look pretty, but it will hold for a long time.

13. Now you can put the batteries in. Mind your polarity! Put the little connector in its socket on the bottom of the esp32 module.
Now you can put the batteries in. Mind your polarity! Put the little connector in its socket on the bottom of the esp32 module.

14. Connect the USB solar panel to the USB connector on the esp32. You're done!
Connect the USB solar panel to the USB connector on the esp32. You're done!

15. If you have a different battery, follow the same principle up until step 13 -- be sure to connect red to red and black to black.
If you have a different battery, follow the same principle up until step 13 -- be sure to connect red to red and black to black.

16. If you have a USB powerbank, connect it between the ESP32 and the solar panel, via the USB port and USB cable. Solar panel goes to the charge port on the power bank.
If you have a USB powerbank, connect it between the ESP32 and the solar panel.

## Step 5: Assembling the Power System

See [Powering the Node](../../power) for information on what batteries and charging equipment can be safely connected. As a general rule

## Step 6: Assemble the Case

See [Case Designs](../case-designs).

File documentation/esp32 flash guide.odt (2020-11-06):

CellSol ESP32 Pocket Pylon Setup Guide

What You Will Need

- A Heltec Lora32 or Lora32v2 module

- The Arduino software, available here: https://www.arduino.cc/en/Main/Software

- A USB cable

- Our CellSol ESP32 Pocket Pylon firmware, available on this GitHub repository

- A battery for the Lora32

- A solar panel to charge the battery (optional, USB may also be used for charging)

Step 1: Setting Up the Arduino Software

To program your Lora32, you will need to have the board manager in the arduino software configured to support it. You will also need to install several arduino libraries used by our firmware.

You will need to add a URL to the Board Manager before starting. In the Arduino software, navigate to File -> Preferences... and in the dialog box, click the browse icon next to “Additional Board Manager URLs”. In the text box that opens, add a new line, and enter the following URL:

https://dl.espressif.com/dl/package_esp32_index.json

Figure 1: Board Manager URLs After Adding

Once this URL is added, you can go on and add the Lora32 boards using the Board Manager.

Navigate to Tools -> Board -> Boards Manager...

Enter “Heltec” in the search, and “Heltec ESP32 Series Dev-Boards” should appear. Click “Install” at the bottom right. Once installed, this button will be replaced by “Remove”.

With the boards configured, it is on to configuring the libraries. Navigate to Tools -> Manage Libraries...

Figure 2: Board Manager After Installing Heltec ESP32

A window similar to the Board Manager will open.

Figure 3: Arduino Library Manager

You will need to search for the following libraries, and, just like installing the boards in Board Manager, install them:

- Adafruit BusIO
- Adafruit GFX Library
- Adafruit SSD1306
- Heltec ESP32 Dev-Boards
- LoRa (by Sandeep Mistry)

Figure 4: Library Manager Showing LoRa Library to Install

Step 2: Setting Up the Lora32 for Programming

With the Lora32 unplugged from your computer, navigate to Tools -> Port and look at the serial ports listed there.

Now, plug in your Lora32 using the USB cable. Your operating system should automatically detect it as a serial port, and configure that port. Navigate again to Tools -> Port. A new one should have appeared: this will be the serial port for the Lora32 you just plugged in. Click on it to select it for programming.

You also need to tell the arduino software that it is using a Lora32 or 32V2. Do this by again navigating to Tools -> Board -> Heltec ESP32 Arduino and selecting Lora32 (black board) or Lora32V2 (white board) depending on which one you are using.

Figure 5: Selecting the Lora32 Board

The other settings for the Lora32 board can be left default; even if you are not in the EU, the REGION setting is not used by the firmware.

Step 3: Configuring the Firmware

There are several firmware settings you will need to choose in order to get the performance you want out of your pocket pylons.

If you have not already done so, open the firmware’s arduino project by File -> open, or using your system’s file manager, and opening “esp32_wifi_bt.ino” that you downloaded at the beginning.

All of these options are configured in #define lines at the top of the root file “esp32_wifi_bt.ino”

Most of these options are turned on and off by commenting (making the line begin with //) or uncommenting (removing the //) the #define statements. The options you must set to make your pocket pylon work are explained below. The options not described are intended for developers, for more advanced configuration – you don’t have to worry about them right now.

Option Name | Purpose | Allowed Values
WIFI_IS_CLIENT | Activates wifi gateway mode if uncommented. This connects the CellSol network to a wifi router. | None
WIFI_IS_HYBRID | Activates wifi hybrid mode if uncommented (gateway + AP). Takes priority over WIFI_IS_CLIENT. | None
DHCP | Uses DHCP for connecting to an upstream router (gateway or hybrid mode) if uncommented | None
REPEATER_ONLY | Emulates the Arduino repeater, turning off the wifi features entirely, if uncommented. Takes priority over everything. | None
CLIENT_IP_ADDR | Client IP address, with the numbers separated by commas; only used in IS_CLIENT or IS_HYBRID and only if DHCP is off. | An IP address separated by commas such as 192,168,1,55
GATEWAY_IP_ADDR | IP address of the gateway router, with the numbers separated by commas; only used in IS_CLIENT or IS_HYBRID and only if DCHP is off. | An IP address separated by commas such as 192,168,1,1
GATEWAY_SUBNET | Subnet mask for the gateway router, with the numbers separated by commas; only used in IS_CLIENT or IS_HYBRID and only if DCHP is off. | An IP subnet mask separated by commas such as 255,255,255,0
WIFI_UPSTREAM_AP | The access point name to be connected to if in IS_CLIENT or IS_HYBRID mode. | Network name in double quotes, like “RobotsEverywhere_24”
WIFI_UPSTREAM_PWD | The password to the access point to connect to in client or hybrid mode | Password in double quotes, like “derpderp”

More about the 3 modes. // TODO: add some little explainer graphics here?

// TODO: explain “Switch every minute” mode.

Access Point Mode: This mode makes the pylon into a WiFi access point. To access the web chat interface, you can connect to that access point with any device.

Client Mode, also known as Gateway Mode: this mode makes the pylon connect to an outside wifi network. You can then access the web chat interface from any computer on that network, as long as you know the pylon’s IP address.

Hybrid Mode: this is just the combination of both Gateway Mode and Access Point Mode. The node will not be as responsive, but it will do both.

Step 4: Programming Your Pylon

Once the firmware is configured, programming the pylon is simple: simply press Ctrl+U or navigate to Sketch -> Upload.

This should begin an upload process that shows at the bottom of the screen. At the bottom right, “done uploading” will display when it is finished, and your pylon is ready to go.

Step 5: Testing Your Pylon

With the pylon still connected to your PC, it should be powered by the USB port. The display should be on, showing the pylon’s IP address.

Using the PC, or a mobile phone or other device, first connect to the network the pylon is on. If it is in client mode, it will be on your WiFi network. If it is in AP mode, connect to the AP it is providing. Next, open a web browser, and type the IP address of the pylon (it will show up on the ESP32’s OLEd display screen) and press enter. This should show you the pylon’s web interface.

Figure 6: A fresh pylon, viewed through the web interface

With this working, you are ready to assemble your pylon.

Step 6: Assembling your Pylon

// TODO: visual guide to putting the Lora32 in the waterproof case and attaching the antenna

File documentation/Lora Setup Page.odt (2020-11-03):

neLast Updated: October 14, 2020

- How to install the software on the Esp32
- How to configure your pylon as a gateway - so devices can connect over WIFI (instead of directly to the pylon)
- Cases for your Esp 32
- How to build an Arduino-based pylon and install & configure its software
  - Loading the firmware

How to install the software on the Esp32

(A pylon is: a LoRa receiver/transmitter - whether it lives on a rooftop or in your pocket) - to build your own network

1. Plug your esp32 into the computer

2. Download the Arduino SDK from: arduino.cc/en/Main/Software and Install it on your computer (PC or Mac)

Note: You will also need to download and unzip our LoRa software. (https://github.com/AaronSwartzDay-SSP/LoRa) Setting it up is explained in detail in Step 9.

3. Open it and go to “Preferences” and cut and paste this URL into the “Additional Board Manager URLS” form field:

https://dl.espressif.com/dl/package_esp32_index.json

(https://www.aaronswartzday.org/wp-content/uploads/2020/10/Preferences-Arduino-SDK-BoardsManagerURL.png) (https://www.aaronswartzday.org/wp-content/uploads/2020/10/Preferences-Arduino-SDK-BoardsManagerURL.png)

4. Click OK and close & restart the program

5. Go to “Tools”

"Board"

"Board Manager"

SCREENGRAB SELECTING THIS

and scroll to the very bottom where it says esp32 by Espressif Systems - and install those libraries

(https://www.aaronswartzday.org/wp-content/uploads/2020/10/Boards-Manager.png) (https://www.aaronswartzday.org/wp-content/uploads/2020/10/Boards-Manager.png)

6. Go to “Tools” “Board” “esp32” and select “Helltec Wifi LoRa 32 (v2)”

The pic below is a little confusing because you will notice that "Heltec WiFi LoRa 32(V2)" is already loaded in - but I'm still including this grab so you can see how to select it.

Mouse over where it says "ESP Arduino" and there will be a huge list of boards to choose from. Scroll down near the bottom and select: "Heltec WiFi LoRa 32(V2)"

(https://www.aaronswartzday.org/wp-content/uploads/2020/10/Tools-Board-Heltec-Wifi-LoRa-32V2.png) (https://www.aaronswartzday.org/wp-content/uploads/2020/10/Tools-Board-Heltec-Wifi-LoRa-32V2.png)

7. There are drivers you need to install before it will compile properly:

PC drivers are here:

need to list and find these

Mac drivers are here:

need to list these

https://www.silabs.com/products/development-tools/software/usb-to-uart-bridge-vcp-drivers

Esp32 docs here:

https://docs.espressif.com/projects/esp-idf/en/latest/esp32/get-started/index.html

8. There will also be libraries that you need to install, which differ, depending whether you are using a PC or a Mac.

PC | Mac
Link to 2:38 of the youtube tutorial on this | Adafruit GFX Libraries Adafruit Bus LoRa LibrariesNote: You will have to use your system password to unlock your security preferences to install these libraries. (Remember to relock when you're done :)

If you're not sure if you have all the right libraries installed, try to "Open" and "Upload" the software. This will cause the SDK to try to compile the code. You can also go to "Sketch" and then "compile/verify" or (ctrl+R).

If you don't have all of the correct libraries installed, the names of what you need will be given to you as compile errors in the lower part of the document window. (NEED SCREENGRAB)

Once you have the name, it's easy to find and install the libraries you need.

9. Go to "Tools" and then "Manage Libraries" - and search for the library you need using the search box. (You can also scroll down to what you want, but it scrolls very slowly and the libraries aren't all in alphabetical order! So you're going to want to use search :)

When you find the library and mouse over it - you will be shown a version drop down menu and an "Install" button.

Select the version you wish to install (use the latest version unless there's a specific reason not to) and click on "Install."

(https://www.aaronswartzday.org/wp-content/uploads/2020/10/LoRa-Library-Manager.png) (https://www.aaronswartzday.org/wp-content/uploads/2020/10/LoRa-Library-Manager.png)

10. Select the Port - "Port-dev-cu.SLAB_USBtoUART"

(https://www.aaronswartzday.org/wp-content/uploads/2020/10/Port-dev-cu.SLAB_USBtoUART.png) (https://www.aaronswartzday.org/wp-content/uploads/2020/10/Port-dev-cu.SLAB_USBtoUART.png)

11. Download the zip file of our LoRa software here, and unzip it on your hard drive:

(https://github.com/AaronSwartzDay-SSP/LoRa)

What's in our software package:

TREE OF SOFTWARE

12. To load the software on to your esp32, go to "File" "Open" and navigate to the "ino" file in the esp32 directory.

"esp32_wifi_bt_or_gateway.ino"

#### Creating a Gateway

If you create a gateway, any device connected to your WIFI network can also access the devices on the LoRa network.

To enable the gateway functionality in your pylon, follow these steps. The code is already included in the file, you just need to take out the "//" characters at the beginning of each line that comments it out.

Note that gateway mode must be configured manually and will need an open port on the router.

1. remove the "//" in front of "//#define WIFI_IS_CLIENT"

// Uncomment the above to enable use as a gateway.

2. enter the name of your wifi network and its password in this section: (RILEY I could use your help explaining where the different numbers come from below - and how folks look them up for their own networks.)

#define CLIENT_IP_ADDR 192,168,1,200 // client IP address for client or hybrid mode. needs commas instead of periods
#define GATEWAY_IP_ADDR 192,168,1,1 // router IP address for client or hybrid mode. needs commas instead of periods
#define GATEWAY_SUBNET 255,255,255,0 // subnet mask for client or hybrid mode. needs commas instead of periods
#define WIFI_UPSTREAM_AP "NameOfNetworkHere" // SSID of the router we're trying to connect to.
#define WIFI_UPSTREAM_PWD "PasswordForNetworkHere"// password for the router we're trying to connect to. Use "" for none/open.

3. Click "Save" - and then "upload" to load the software on to your esp32. (It will say "Hard resetting via RTS pin..." when it's done.)

To check if the gateway has been configured, press the "PROG" button on the gateway pylon. The address should be what you entered into this chunk of code in step 2 above:

PICTURE of IP ADDRESS on screen of esp32

4. To access the LoRa network over your existing WiFi network using the gateway, type: "192.168.1.200" - into a browser window.

Note that this was the same IP address that you programmed in during STEP 2 above. Here is the code again:

#define CLIENT_IP_ADDR 192,168,1,200 // client IP address for client or hybrid mode. needs commas instead of periods

SCREENGRAB HERE OF ACCESSING 192.168.1.200 over the gateway.

Screengrab here of the messages (a) on screen of #3 esp

Screengrabs here of the messages (a) and (b) on phone 1 & phone 2

Screengrab of Phone 1 with Login as result of captive portal page

Screengrab of Phone 1 with messages (a)

Screengrab of Phone 1 with messages (a) and (b)

Screengrab of Phone 2 captive portal page with messages (c) showing

#### Cases for your esp32

We have included an .stl file in the /esp32/case folder in the zip file - "lora32_case_edited.stl" - which can be used to 3D print a case that can fit snugly in your pocket or backpack and protect your pylon.

Our case is a modification of the esp32's "product box" - with rounded edges to better fit in one's pocket (alas, it is a "pocket pylon").

A few details for those interested re: 3D printing cases:

When modifying an existing design, it's important to first make the measurements of the file 1% bigger before modifying it further. This is because whenever you print 3D objects, the filament squishes a teeny tiny bit; but it can be enough to make what you are printing too small to "fit" whatever you are covering.

Another Sidenote: This phenomena of enlarging your blueprints by 1% to account for the squishing phenomena has a corollary for laser cutters, which will always cut your object a teeny bit bigger, to account for the length across of the laser beam doing the cutting.

So for 3D printing - increase your schematic in size by 1%

For laser cutting - decrease your schematic in size by 1% (or to account perfectly for the size of your laser beam).

#### How to build an Arduino-based pylon and install & configure its software

Arduino set up instructions

Why we created the arduino model:

1) It is a lot cheaper to build

2) It runs on a lot less power - Matteo literally left one running in the dark for three days (so the solar panel wasn't recharching) and it was still running)

The standard Arduino cellsol node can be used as a repeater, or as an access point for one phone or computer.

A firmware version that has two bluetooth interfaces, and a version that only operates as a repeater but requires less power (and can be airlifted by a cheap drone) also exist; I recommend becoming familiar with the standard version first.

BLOCK DIAGRAM (Logic)

(LoRa transceiver)----(Arduino)----(Bluetooth/serial module)

BLOCK DIAGRAM (Power)

Power input ----- 3.7v switching reg -------- 3.3v LDO linear reg ---- active components
\-- battery

POWERING THE NODE

The node is designed to be very tolerant when it comes to input power, so that it can be run in a variety of emergency situations.

The node takes 4 to 6.5V power. You can provide this from USB, a solar panel, or a number of other sources such as:

* USB power bank. It has to be plugged into the USB power input port. You can break down a USB cable to do this and connect the red and black wires.

* 6V lead-acid battery, connected to the USB power input port.

* 6V bike dynamo. Using a diode in series with the node power input is recommended (1N4004 or similar). If you use this, the node MUST have a secondary battery.

* 3 alkaline cells (AAA to D cells) in series. Important: these must be NON-rechargeable!

* Anything that outputs USB (car adapter, wall plug, spare USB port on a wifi router, 10 pounds of potatos connected in series, etc)

* USB hand crank. If you use this, the node MUST have a secondary battery.

Connect the power source to the P+ and P- terminals on the node, or use the micro usb plug. RESPECT POLARITIES. The node does NOT have reverse polarity protection in its current incarnation.

BATTERY TYPES FOR THE NODE

You will need a 3.5 to 4 volt battery to keep the node operating overnight (or when its primary power input is off). The node has been designed to be compatible with a variety of battery typologies. Any one of these will work. If you want to use more than one battery, connect them in parallel. In this case you may NOT mix battery types!

* None. The node has a two stage voltage regulator (switching to 3.7v and linear to 3.3v) and a filter capacitor, so it's safe to run it without a battery if it has continuous power coming in. The exception, as noted above, is if you have a USB hand crank or bike dynamo.

* 3.7V LiPo battery. Any type is fine (18650, old quadcopter battery, etc). If it has no protection circuit, it's fine.

* 3.6V lithium battery. Any type is fine (Old cell phone battery, etc).

* 3 rechargeable cells (AAA to D cells) in series. Important: these must be rechargeable!

* 4V lead-acid battery, connected to the battery terminals. Optionally, add a 47 ohm resistor between solar in+ and battery in+. (Note that this also applies to a 6V lead-acid battery that has a dead cell: the node uses little continuous power, so this is safe to do! Good for emergencies.)

* A supercapacitor (if you want to show off) A 5V supercap will work just fine as if it was a battery. Warning: A 3.3V supercap will NOT! If you have one of those, connect it between 3V3 and GND.

* If all you have available is a 3.3V LiFePo4 cell, you can still use it if you connect a capacitor to the battery terminals, and connect the battery itself to the 3V3 and GND terminals on the Arduino. Connect a 47 ohm resistor between B+ on the battery charger board and 3V3. This one is at your own risk and the battery will never get a full charge, but it will work in an emergency.

Connect the battery to the B+ and B- terminals on the node. RESPECT POLARITIES. The node does NOT have reverse polarity protection in its current incarnation. If a battery has other connectors other than + or - you should be able to just ignore them (this is common with cell phone batteries).

Building the Arduino Pylon

You will have to know how to solder in order to build the Arduino pylon from scratch.

I recommend soldering the SX1276 module in first, because it's the fiddliest part and requires the most focus.

Solder a wire on the base board where the closely spaced holes are, then cut it at about 3mm (1/8in) and let it stick up. Repeat for either all the holes, or if you are in a hurry, the holes that you see a PCB trace coming out of (They are all on the top side of the board except the one near the bluetooth connector). They are 1,4,5,6,7,11, and 12. If you have a proper 1.27mm header, use that instead.

Next, take the SX1276 module, slide into the header you just made, and solder it in place.

The next part that has to go in is the L3338 regulator. Solder it in place. It can only go one way. The large tab isn't connected to anything, so you can skip it if you are in a hurry; the node doesn't eat up enough current for the regulator to need a heatsink.

Solder the capacitor and the resistor next. They don't have a polarity, so it doesn't matter which way you put them in the board.

Next, solder the Arduino in place, in the same way that you soldered in the SX1276. The holes are more spaced, so it should be easier. If you don't want to solder and cut wire, you can use a 2.54mm header (also known as a 100 mil header or a 0.1 inch header). In general, if you bought an Arduino Nano or compatible, it should have come with the header. If you are in a hurry, you can only solder the pins you need (GND, 3V3, 0, 1, 7, 10, 11, 12, 13).

Now it's time to connect the power control board; you will once again have to use the wire-sitting-up trick, or you can use single pegs of a 0.1in header. Place the power control board on the base board so that its USB port is on top, and connect the pins according to where they are on both boards.

B+ and B- go on the JST connector that goes to your battery (or directly to the battery).
P+ and P- go to your solar panel or other non-USB power source (including 6V batteries, do NOT connect a 6V battery to B+ and B-)
OUT+ and OUT- are feeding the node.

The next thing you have to do is solder the antenna to the SX1276. How to do it depends on your antenna. For a simple wire antenna, just solder the GND pin on the far side of the SX1276 to the base board ground, and the ANT pin to a piece of solid (not stranded) wire. I recommend cutting it to 8.5cm (3.5in), soldering it, and then cutting it again so that the part that actually sticks out of the SX1276 is exactly 7.8cm (3.1in) long. Wire length MATTERS since this is an antenna - take some time to measure carefully!

Finally, you have to decide whether you want to permanently solder in the bluetooth to serial module or not (or skip it entirely if you are just making a repeater). Note that if you are soldering in a HC05 or HC06 module, which is the most common module, you will want to connect it so that its SMD board is facing AWAY from the Arduino! If you bend the socket or the module pins to fold it on top of the Arduino, the LED should come up on top.

Upon deploying a repeater with a bare-wire antenna, if you can, the ground pin should go to earth ground, this will improve the radio range.

#### Loading the Firmware

Now you need to flash the firmware. It's a regular Arduino sketch, so all you need to do is follow the tutorial that should have come with the Arduino, except that you will be loading the CellSol sketch. You will have to get the Lora.h library from the repository.

The node firmware will work with a 8Mhz Arduino and a 16Mhz Arduino alike; be sure to select the right clock speed in the Arduino IDE. If you get it wrong, nothing will break (so, if you are in doubt, try again with the ohther setting), but the Bluetooth module will not be ble to talk to the Arduino.

If you want to load the firmware with two serial ports, and want to use the second serial port, it will be on pins 8 and 9. You will need a 16Mhz Arduino unless you set the Bluetooth module to operate at 4800bps beforehand.

CONNECTING TO THE PYLON AND SENDING MESSAGES TO IT

You can use either the Arduino serial port programmer to send and receive data from the LoRa mesh, or use the Bluetooth module. For a computer, any serial terminal will work in either case; just set it to 9600bps.

For Android phones, you can download the Bluetooth chat app from an ESP32 CellSol node or get it from us (TODO: Put on android market also).

For iPhone, you will likewise have to find a Bluetooth terminal app.

For Blackberry, S40, S60 and older phones, you CAN use this! Bluetooth terminal apps are available! (For example http://appworld.blackberry.com/webstore/content/59970357 )

The node is pass-through; you will get packets as they come in, and send packets immediately after you hit enter. Unlike the ESP32, it does not have enough memory to hold any message history.

When a packet comes in, you will be told its RSSI, which should give you an idea about how far it's coming from. This is the RSSI of the last repeater, not of the originating node.

CARE AND FEEDING

The node has no moving parts and will operate pretty much indefinitely on solar power. Be sure that it gets as much sun as possible! Every other year, consider replacing the battery. Every six months or so, clean the solar panel. If you have the whole thing earthed via the ground pin, check for corrosion on the earth peg.

**********HTML (that there is) for this page***********

<strong>Last Updated: October 14, 2020</strong>

<ul>

<li><strong> <a href="#esp32">How to install the software on the Esp32</a>

</strong></li>

<li><a href="#gateway"><strong>How to configure your pylon as a gateway</strong></a> - so devices can connect over WIFI (instead of directly to the pylon)</li>

<li><strong> <a href="#cases">Cases for your Esp 32 </a></strong></li>

<li><strong> <a href="#arduino">How to build an Arduino-based pylon and install &amp; configure its software</a></strong>

<ul>

<li><strong><a href="#arduinofirmware">Loading the firmware</a></strong></li>

</ul>

</li>

</ul>

(A pylon is: a LoRa receiver/transmitter - whether it lives on a rooftop or in your pocket) - to build your own network</strong>

1. Plug your esp32 into the computer

2. Download the Arduino SDK from: <a href="https://www.arduino.cc/en/Main/Software">arduino.cc/en/Main/Software </a>and Install it on your computer (PC or Mac)

Note: You will also need to download and unzip the <a href=""> LoRa software.</a></strong> Setting it up is explained in detail in <a href="#step9"><strong>Step 9</strong></a>.

3. Open it and go to “Preferences” and cut and paste this URL into the “Additional Board Manager URLS” form field:

https://dl.espressif.com/dl/package_esp32_index.json

Preferences-Arduino-SDK-BoardsManagerURL.png

4. Click OK and close &amp; restart the program

5. Go to “Tools”

"Board"

"Board Manager"

SCREENGRAB SELECTING THIS

and scroll to the very bottom where it says esp32 by Espressif Systems - and install those libraries

Boards-Manager.png

6. Go to “Tools” “Board” “esp32” and select “Helltec Wifi LoRa 32 (v2)”

The pic below is a little confusing because you will notice that "Heltec WiFi LoRa 32(V2)" is already loaded in - but I'm still including this grab so you can see how to select it.

Mouse over where it says "ESP Arduino" and there will be a huge list of boards to choose from. Scroll down near the bottom and select: "Heltec WiFi LoRa 32(V2)"

Tools-Board-Heltec-Wifi-LoRa-32V2.png

7. There are drivers you need to install before it will compile properly:

PC drivers are here:

need to list and find these

Mac drivers are here:

need to list these

<strong><a href="https://www.silabs.com/products/development-tools/software/usb-to-uart-bridge-vcp-drivers">https://www.silabs.com/products/development-tools/software/usb-to-uart-bridge-vcp-drivers</a></strong>

Esp32 docs here:

<strong><a href="https://docs.espressif.com/projects/esp-idf/en/latest/esp32/get-started/index.html">https://docs.espressif.com/projects/esp-idf/en/latest/esp32/get-started/index.html</a></strong>

8. There will also be libraries that you need to install, which differ, depending whether you are using a PC or a Mac.

<table>

<tbody>

<tr>

<td><strong>PC</strong></td>

<td><strong>Mac</strong></td>

</tr>

<tr>

<td>Link to 2:38 of the youtube tutorial on this</td>

<td>Adafruit GFX Libraries

Adafruit Bus

LoRa LibrariesNote: You will have to use your system password to unlock your security preferences to install these libraries.

(Remember to relock when you're done :)</td>

</tr>

</tbody>

</table>

If you're not sure if you have all the right libraries installed, try to "Open" and "Upload" the software. This will cause the SDK to try to compile the code. You can also go to "Sketch" and then "compile/verify" or (ctrl+R).

If you don't have all of the correct libraries installed, the names of what you need will be given to you as compile errors in the lower part of the document window. <strong>(NEED SCREENGRAB)</strong>

Once you have the name, it's easy to find and install the libraries you need.

9. Go to "Tools" and then "Manage Libraries" - and search for the library you need using the search box. (You can also scroll down to what you want, but it scrolls very slowly and the libraries aren't all in alphabetical order! So you're going to want to use search :)

When you find the library and mouse over it - you will be shown a version drop down menu and an "Install" button.

Select the version you wish to install (use the latest version unless there's a specific reason not to) and click on "Install."

LoRa-Library-Manager.png

10. Select the Port - "Port-dev-cu.SLAB_USBtoUART"

Port-dev-cu.SLAB_USBtoUART.png

What's in the software package:

<strong>TREE OF SOFTWARE</strong>

&nbsp;

12. To load the software on to your esp32, go to "File" "Open" and navigate to the "ino" file in the esp32 directory.

"esp32_wifi_bt_or_gateway.ino"

&nbsp;

<h4 id="gateway">Creating a Gateway</h4>

If you create a gateway, any device connected to your WIFI network can also access the devices on the LoRa network.

To enable the gateway functionality in your pylon, follow these steps. The code is already included in the file, you just need to take out the "//" characters at the beginning of each line that comments it out.

Note that gateway mode must be configured manually and will need an open port on the router.

<ol>

<li>remove the "//" in front of "//#define WIFI_IS_CLIENT"</li>

</ol>

// Uncomment the above to enable use as a gateway.

2. enter the name of your wifi network and its password in this section: <strong>(RILEY I could use your help explaining where the different numbers come from below - and how folks look them up for their own networks.)</strong>

#define CLIENT_IP_ADDR 192,168,1,200 // client IP address for client or hybrid mode. needs commas instead of periods

#define GATEWAY_IP_ADDR 192,168,1,1 // router IP address for client or hybrid mode. needs commas instead of periods

#define GATEWAY_SUBNET 255,255,255,0 // subnet mask for client or hybrid mode. needs commas instead of periods

#define WIFI_UPSTREAM_AP "NameOfNetworkHere" // SSID of the router we're trying to connect to.

#define WIFI_UPSTREAM_PWD "PasswordForNetworkHere"// password for the router we're trying to connect to. Use "" for none/open.

&nbsp;

3. Click "Save" - and then "upload" to load the software on to your esp32. <em>(It will say "Hard resetting via RTS pin..." when it's done.)</em>

To check if the gateway has been configured, press the "PROG" button on the gateway pylon. The address should be what you entered into this chunk of code in step 2 above:

&nbsp;

<strong>PICTURE of IP ADDRESS on screen of esp32</strong>

&nbsp;

&nbsp;

4. To access the LoRa network over your existing WiFi network using the gateway, type: "192.168.1.200" - into a browser window.

Note that this was the same IP address that you programmed in during STEP 2 above. Here is the code again:

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

SCREENGRAB HERE OF ACCESSING 192.168.1.200 over the gateway.

Screengrab here of the messages (a) on screen of #3 esp

Screengrabs here of the messages (a) and (b) on phone 1 &amp; phone 2

Screengrab of Phone 1 with Login as result of captive portal page

Screengrab of Phone 1 with messages (a)

Screengrab of Phone 1 with messages (a) and (b)

Screengrab of Phone 2 captive portal page with messages (c) showing

<h4 id="cases">Cases for your esp32</h4>

We have included an .stl file in the /esp32/case folder in the zip file - "lora32_case_edited.stl" - which can be used to 3D print a case that can fit snugly in your pocket or backpack and protect your pylon.

Our case is a modification of the esp32's "product box" - with rounded edges to better fit in one's pocket (alas, it is a "pocket pylon").

A few details for those interested re: 3D printing cases:

When modifying an existing design, it's important to first make the measurements of the file 1% bigger before modifying it further. This is because whenever you print 3D objects, the filament squishes a teeny tiny bit; but it can be enough to make what you are printing too small to "fit" whatever you are covering.

Another Sidenote: This phenomena of enlarging your blueprints by 1% to account for the squishing phenomena has a corollary for laser cutters, which will always cut your object a teeny bit bigger, to account for the length across of the laser beam doing the cutting.

So for 3D printing - increase your schematic in size by 1%

For laser cutting - decrease your schematic in size by 1% (or to account perfectly for the size of your laser beam).

<h4 id="arduino">How to build an Arduino-based pylon and install &amp; configure its software</h4>

<strong>Arduino set up instructions</strong>

Why we created the arduino model:

1) It is a lot cheaper to build

2) It runs on a lot less power - Matteo literally left one running in the dark for three days (so the solar panel wasn't recharching) and it was still running)

&nbsp;

The standard Arduino cellsol node can be used as a repeater, or as an access point for one phone or computer.

A firmware version that has two bluetooth interfaces, and a version that only operates as a repeater but requires less power (and can be airlifted by a cheap drone) also exist; I recommend becoming familiar with the standard version first.

BLOCK DIAGRAM (Logic)

(LoRa transceiver)----(Arduino)----(Bluetooth/serial module)

BLOCK DIAGRAM (Power)

Power input ----- 3.7v switching reg -------- 3.3v LDO linear reg ---- active components

\-- battery

POWERING THE NODE

The node is designed to be very tolerant when it comes to input power, so that it can be run in a variety of emergency situations.

The node takes 4 to 6.5V power. You can provide this from USB, a solar panel, or a number of other sources such as:

* USB power bank. It has to be plugged into the USB power input port. You can break down a USB cable to do this and connect the red and black wires.

* 6V lead-acid battery, connected to the USB power input port.

* 6V bike dynamo. Using a diode in series with the node power input is recommended (1N4004 or similar). If you use this, the node MUST have a secondary battery.

* 3 alkaline cells (AAA to D cells) in series. Important: these must be NON-rechargeable!

* Anything that outputs USB (car adapter, wall plug, spare USB port on a wifi router, 10 pounds of potatos connected in series, etc)

* USB hand crank. If you use this, the node MUST have a secondary battery.

Connect the power source to the P+ and P- terminals on the node, or use the micro usb plug. RESPECT POLARITIES. The node does NOT have reverse polarity protection in its current incarnation.

BATTERY TYPES FOR THE NODE

You will need a 3.5 to 4 volt battery to keep the node operating overnight (or when its primary power input is off). The node has been designed to be compatible with a variety of battery typologies. Any one of these will work. If you want to use more than one battery, connect them in parallel. In this case you may NOT mix battery types!

* None. The node has a two stage voltage regulator (switching to 3.7v and linear to 3.3v) and a filter capacitor, so it's safe to run it without a battery if it has continuous power coming in. The exception, as noted above, is if you have a USB hand crank or bike dynamo.

* 3.7V LiPo battery. Any type is fine (18650, old quadcopter battery, etc). If it has no protection circuit, it's fine.

* 3.6V lithium battery. Any type is fine (Old cell phone battery, etc).

* 3 rechargeable cells (AAA to D cells) in series. Important: these must be rechargeable!

* 4V lead-acid battery, connected to the battery terminals. Optionally, add a 47 ohm resistor between solar in+ and battery in+. (Note that this also applies to a 6V lead-acid battery that has a dead cell: the node uses little continuous power, so this is safe to do! Good for emergencies.)

* A supercapacitor (if you want to show off) A 5V supercap will work just fine as if it was a battery. Warning: A 3.3V supercap will NOT! If you have one of those, connect it between 3V3 and GND.

* If all you have available is a 3.3V LiFePo4 cell, you can still use it if you connect a capacitor to the battery terminals, and connect the battery itself to the 3V3 and GND terminals on the Arduino. Connect a 47 ohm resistor between B+ on the battery charger board and 3V3. This one is at your own risk and the battery will never get a full charge, but it will work in an emergency.

Connect the battery to the B+ and B- terminals on the node. RESPECT POLARITIES. The node does NOT have reverse polarity protection in its current incarnation. If a battery has other connectors other than + or - you should be able to just ignore them (this is common with cell phone batteries).

<strong>Building the Arduino Pylon</strong>

You will have to know how to solder in order to build the Arduino pylon from scratch.

I recommend soldering the SX1276 module in first, because it's the fiddliest part and requires the most focus.

Solder a wire on the base board where the closely spaced holes are, then cut it at about 3mm (1/8in) and let it stick up. Repeat for either all the holes, or if you are in a hurry, the holes that you see a PCB trace coming out of (They are all on the top side of the board except the one near the bluetooth connector). They are 1,4,5,6,7,11, and 12. If you have a proper 1.27mm header, use that instead.

Next, take the SX1276 module, slide into the header you just made, and solder it in place.

The next part that has to go in is the L3338 regulator. Solder it in place. It can only go one way. The large tab isn't connected to anything, so you can skip it if you are in a hurry; the node doesn't eat up enough current for the regulator to need a heatsink.

Solder the capacitor and the resistor next. They don't have a polarity, so it doesn't matter which way you put them in the board.

Next, solder the Arduino in place, in the same way that you soldered in the SX1276. The holes are more spaced, so it should be easier. If you don't want to solder and cut wire, you can use a 2.54mm header (also known as a 100 mil header or a 0.1 inch header). In general, if you bought an Arduino Nano or compatible, it should have come with the header. If you are in a hurry, you can only solder the pins you need (GND, 3V3, 0, 1, 7, 10, 11, 12, 13).

Now it's time to connect the power control board; you will once again have to use the wire-sitting-up trick, or you can use single pegs of a 0.1in header. Place the power control board on the base board so that its USB port is on top, and connect the pins according to where they are on both boards.

B+ and B- go on the JST connector that goes to your battery (or directly to the battery).

P+ and P- go to your solar panel or other non-USB power source (including 6V batteries, do NOT connect a 6V battery to B+ and B-)

OUT+ and OUT- are feeding the node.

The next thing you have to do is solder the antenna to the SX1276. How to do it depends on your antenna. For a simple wire antenna, just solder the GND pin on the far side of the SX1276 to the base board ground, and the ANT pin to a piece of solid (not stranded) wire. I recommend cutting it to 8.5cm (3.5in), soldering it, and then cutting it again so that the part that actually sticks out of the SX1276 is exactly 7.8cm (3.1in) long. Wire length MATTERS since this is an antenna - take some time to measure carefully!

Finally, you have to decide whether you want to permanently solder in the bluetooth to serial module or not (or skip it entirely if you are just making a repeater). Note that if you are soldering in a HC05 or HC06 module, which is the most common module, you will want to connect it so that its SMD board is facing AWAY from the Arduino! If you bend the socket or the module pins to fold it on top of the Arduino, the LED should come up on top.

Upon deploying a repeater with a bare-wire antenna, if you can, the ground pin should go to earth ground, this will improve the radio range.

<h4 id="arduinofirmware">Loading the Firmware</h4>

Now you need to flash the firmware. It's a regular Arduino sketch, so all you need to do is follow the tutorial that should have come with the Arduino, except that you will be loading the CellSol sketch. You will have to get the Lora.h library from the repository.

The node firmware will work with a 8Mhz Arduino and a 16Mhz Arduino alike; be sure to select the right clock speed in the Arduino IDE. If you get it wrong, nothing will break (so, if you are in doubt, try again with the ohther setting), but the Bluetooth module will not be ble to talk to the Arduino.

If you want to load the firmware with two serial ports, and want to use the second serial port, it will be on pins 8 and 9. You will need a 16Mhz Arduino unless you set the Bluetooth module to operate at 4800bps beforehand.

CONNECTING TO THE PYLON AND SENDING MESSAGES TO IT

You can use either the Arduino serial port programmer to send and receive data from the LoRa mesh, or use the Bluetooth module. For a computer, any serial terminal will work in either case; just set it to 9600bps.

For Android phones, you can download the Bluetooth chat app from an ESP32 CellSol node or get it from us (TODO: Put on android market also).

For iPhone, you will likewise have to find a Bluetooth terminal app.

For Blackberry, S40, S60 and older phones, you CAN use this! Bluetooth terminal apps are available! (For example http://appworld.blackberry.com/webstore/content/59970357 )

The node is pass-through; you will get packets as they come in, and send packets immediately after you hit enter. Unlike the ESP32, it does not have enough memory to hold any message history.

When a packet comes in, you will be told its RSSI, which should give you an idea about how far it's coming from. This is the RSSI of the last repeater, not of the originating node.

CARE AND FEEDING

The node has no moving parts and will operate pretty much indefinitely on solar power. Be sure that it gets as much sun as possible! Every other year, consider replacing the battery. Every six months or so, clean the solar panel. If you have the whole thing earthed via the ground pin, check for corrosion on the earth peg.

&nbsp;

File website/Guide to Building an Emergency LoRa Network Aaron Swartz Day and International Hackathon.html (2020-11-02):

# Aaron Swartz Day and International Hackathon (https://www.aaronswartzday.org/)

Search

Search for:

# Guide to Building an Emergency LoRa Network

#### Updated October 14, 2020

This page contains an index of background and details about this project.

If you already understand the basic principles, and just want to grab some hardware, download our software (https://github.com/AaronSwartzDay-SSP/LoRa), and build a LoRa network, here are our setup instructions (http://aaronswartzday.org/lorasetup).

#### A map of our network design (Network Topography)

 (https://www.aaronswartzday.org/wp-content/uploads/2020/07/LORA-Flow-diagrams-300scale-scaled.jpg)

(Click to enlarge) Network topology for a LoRa Network LoRa: Low Frequency Radio Network

(Draft language: In the case of our San Rafael to Richmond connection, a high power antenna will probably be used.)

Map above shows how we are using arduinos to bridge the LoRa signal between the esp32 modules. Ideally, there will be a bit of overlap between the ranges of the esp32s, to enable anyone with a wifi enabled device to access our text messaging page.

#### Index:

- Introduction to this project and what we are trying to build
- System Requirements for our LoRa Network
- Part lists and Software for our “Pylons”: “Pocket Pylons” (pocket-sized repeaters that you can carry around with you) and fixed “Pylons” (fixed repeaters that are used to carry the LoRa signal longer distances and act as “bridges” between the wifi-enabled repeaters that anyone with a phone can access).
  - Option 1 -esp 32 (LoRa Repeater that is wifi-enabled)(more expensive, but no soldering required)
  - Option 2 (cheaper using arduinos but soldering required – also we’ve designed a part that will make it easier to add bluetooth and solar power)
    - Kits from Robots Everywhere with everything needed for the Arduino option (coming soon)
- Our LoRa software (for our “pocket node” prototypes & potentially other LoRa-compatible hardware)
  - Transceiver Software
  - Wifi app with texting Software
  - Software Licensing
  - Captive Portal Implementation
- Antennaes
- Software Libraries
- Next Steps
  - Word compression considerations
- Additional Features for next version
- Definitions of some basic terms to help people new to the project understand what we are doing
- LoRa References
  - Tutorials
  - Standards

Coming soon:

- Other hardware that might work with LoRa
- LoRa Install Guide
- LoRa Troubleshooting Info
- Tech Support

#### Introduction

Problem:

What if the internet and cell phone towers went down for more than a few hours – or during an emergency situation when no communication for several hours could mean lives lost?

Proposed Solution:

We propose to build a LoRa (Low Frequency Radio) network using a combination of “pocket pylons” (repeaters that are carried in peoples’ pockets or, with a larger antenna, in backpacks) and “fixed pylons” (fixed repeaters that forward the signal).

The pocket pylons (esp 32s) will have wifi access points on them for any wifi-enabled device to connect to. The fixed pylons are arduino-based and only have the ability to connect via bluetooth to one device at a time.

1. We will build an “Emergency LoRa Network.”
2. We have written software here (https://github.com/AaronSwartzDay-SSP/LoRa/) to enable users to send text messages, either one to one or one to everyone on the network, over their cell phones.
3. A LoRa network is a “low power radio network” (using the LoRa protocol (https://en.wikipedia.org/wiki/LoRa)).
4. We will design our devices to be easily rechargeable from 5v solar panels.
5. To enable our network to function optimally with large crowds in a setting with lots of building, we will create mobile “pocket pylons” – for which we have just built two working prototypes.

#### System Requirements for LoRa network

Our network design utilizes a combination of “fixed pylons” (fixed repeaters) placed mostly on the roofs and outside of buildings and “pocket pylons” (mobile repeaters that live in peoples’ pockets and backpacks) to allow for more “hops” across the network.

The pocket pylons will also provide wifi so that any wifi-enabled device can connect to the LoRa network and send and receive messages over it.

Power requirements – Using a Solar panel to recharge the battery

Although we will connect a battery to our pocket and fixed pylon repeaters, the battery will quickly run out if it is not supplemented by a solar panel that recharges the battery during the day. For this reason, we have integrated a solar panel into the design.

Note that, for the pocket pylons, it is more likely that you will want to use an additional battery or two to keep your pylon going over the course of the day, rather then depend on a solar panel being able to recharge it successfully while you are walking around. For fixed pylons however, especially those living on roof tops, a 5v solar panel will do quite nicely at keeping the battery charged.

These “pocket pylons” that we are building are able to use a 5v solar panel as-is. (5.6v is also within tolerances)

Remember to plug in your batteries and let them charge overnight the night before you assemble your repeaters. This will ensure that it’s charged up as much as possible.

The way this works, is by placing the battery in-between the esp32 module and the solar panel, allowing the solar panel to keep the battery charged.

Note: Neither the ESP32 nor the Arduino is able to be powered directly from the panel, because solar panels don’t collect at a constant voltage. So, if you purchased say, a 5 watt solar panel, it’s really going to be collecting at 4.5 watts on some days and 5.6 watts on other days, but the devices that need to be powered require a consistent 5 watt stream.

Prototypes

We have created two different prototypes. A more expensive option that does not require any soldering, and an arduino-based model that requires soldering and, ideally, the use of a special circuitboard that we are designing and potentially mass-producing, to lower the price and make the option easier to implement. (Kits coming soon)

Our “pylons” are very simple devices that do one of three things:

1. I have a list of phones/computers that are connected to me directly
2. I have received a message that is for one of these: i will send it to that device
3. I have received a message that is not for one of these: i’m going to re-transmit it, so that it may get where it has to go”

The above is true whether there ARE endpoints (phones, pc’s) connected to the node or not, so it can always be the same bit of hardware.

The “I’m going to re-transmit” part can be done stupidly (everyone spams out what they received as long as they don’t do it more than once) or smart (use timestamp or gps or both to make a good guess of where it has to go).

In a mesh network like we are describing, each node is also a router, and re-transmitting is handled via routing.

A node also provides a gateway from other devices (via BLE or WiFi) INTO and OUT OF the mesh network, and also provides routing WITHIN the mesh.

Part lists and Software for our Prototypes:
Part lists and Software for our “Pylons”:
“Pocket Pylons” (pocket-sized repeaters that you can carry around with you) and “Fixed Pylons” (fixed repeaters that are used to carry the LoRa signal longer distances and act as “bridges” between the wifi-enabled repeaters that anyone with a phone can access).

Note that for these options below, identical hardware is used for the repeater/transmitter parts – whether you are making a “pocket pylon” – that uses a smaller antenna, a “backpack pylon” with a larger antenna, or a “fixed pylon”(yeah, we couldn’t resist) – that you wish to place on top of a building or somewhere else outside, for better reception and range.

##### Option 1 – ESP 32 (LoRa Repeater that is wifi-enabled)

Hardware:

915MHz ESP32 LoRa 0.96 OLED Development Board SX1276 WiFi Bluetooth Transceiver Module + LoRa Antenna +JST Connector for Arduino LoraWan IOT Internet of Thing (Pack of 2) https://www.amazon.com/gp/product/B086ZG25DZ/ref=ppx_yo_dt_b_asin_title_o03_s00?ie=UTF8&psc=1

ESP32 LoRa 32 (V2), ESP32 Development Board WIFI Bluetooth LoRa Dual Core 240MHz CP2102 with 0.96inch OLED Display included 868/915MHZ Antenna for Smart Cities, Smart Farms, Smart Home, and IoT Makers https://www.amazon.com/gp/product/B076MSLFC9/ref=ppx_yo_dt_b_asin_title_o00_s00?ie=UTF8&psc=1

Software:

A zip file with software for either the esp32 or arduino models is available here: https://github.com/AaronSwartzDay-SSP/LoRa

#### Kits from Robots Everywhere with everything needed for the Arduino option

COMING SOON

##### Option 2 – Arduino (LoRa Repeater w single bluetooth connection)

The same basic repeater – that literally uses the same software – but this one requires a bit of soldering, and is made using an inexpensive arduino and a semtech chip.

The nice thing about this particular arduino is that it costs $1 if you buy more than 50.

We are designing and potentially mass producing a larger, pre-made circuit, for use with the arduino options – will make it easier for people to put together.

#### Our LoRa software (for our “pocket pylon” prototypes & potentially other LoRa-compatible hardware)

#### Transceiver software

The Transceiver code is packaged in with everything else on our github here:
https://github.com/AaronSwartzDay-SSP/LoRa

Install instructions are here: aaronswartzday.org/lorasetup

This is software for a very basic transceiver for either a LoRa heltec module with a display, or an arduino (without a display).

Basically it acts like an old timey XBee series 1 and displays the last packet it got. So, it should be good for debugging /packet sniffing.

Interestingly it can be a wifi gateway (https://www.aaronswartzday.org/lorasetup/#gateway).

Picture of Option2:



#### Wifi App for Texting Software

This software interconnects between a com port (or more than one), a really derpy website that shows the last 10 messages and lets you input one (over LoRa). The cool thing is that it just works ™ – even on old cell phones. The site even loads on a G1 phone from 2009

##### Link to our software, which includes a wifi app with texting software, on github here: https://github.com/AaronSwartzDay-SSP/LoRa

This firmware, written by Matteo Borri and Riley August, should work on most existing LoRa modules. (We suggest using a LoRa 32 heltec modules (https://www.aaronswartzday.org/lora/#option1))

This software works for up to 8 wifi-enabled devices at a time.

Here’s a little model of what we are building:

—-fones
——gateway
——–repeater
——–repeater
——–repeater
——gateway
—-fones



These “pocket pylons” that we are building are able to use a 5v solar panel as-is. (5.6v is also within tolerances)



Above: CellSol in action.
This basically bridges LoRa, wifi (via a derpy webpage although i guess we can do telnet/ssh) and the uarts on the controller. Wiring is just 5v to panel, with the zener diode across the leads.
Note that the internal resistance of the panel is sufficient to prevent fuckups.
Note that the battery in the above photo was harvested from a dead ipad. We added wifi using some 5.1 volt zener diodes.



Above: This is still just super basic – yet already sufficient for coordinating between two areas.

#### Option 2: Arduino-based (requires soldering)



arduino pro mini 8mhz 3.3v operation
(uint8_t NSSPin = 10, uint8_t NRESETPin = 9
nss = pin10 (can be moved)
reset = pin9 (can be move)
sck = pin13 (cannot be moved)
mosi = pin11 (no)
miso = pin12 (no)



Very simple circuit – for those who can solder. See below for the circuit we are designing to make it even easier to solder :)

Bluetooth adapters (for the arduino boards)



Blue tooth 3.0 adapters – 10 of them :) (for arduino boards)



Blue tooth 3.0 adapters – 10 of them :) (for arduino boards)

Bluetooth modules that are easy to hook up to the arduino: HC05



Connect the HC05 to pins 0 and 1 and it will work out of the box.



This is the super basic version of the repeater as you see there’s only four points of shoulder that are hard to do and even that one took a few minutes.



Pretty much the most basic repeater possible



A 5v solar panel with antenna.



An arduino with bluetooth module soldered on and circuit soldered on for plugging into a solar panel. Note that the bluetooth functionality of these repeaters can be dismantled if desired by “plugging” the bluetooth connector, if desired. [?Note to make sure this “plugging” is explained correctly?]

#### Licensing

The RadioHead library uses GPL 3.0, which requires us to make everything we use it with also available under GPL 3.0.

#### Captive Portal Implementation

We are building capabilities into our little wifi access points so that a user will automatically redirect to our desired homepage upon accessing the network.

There are several different ways that this can be accomplished (and we’d love to hear more). So far we have:

1. There’s an HTTP redirect Usually used when people are already using a well known URL that you don’t want to change, rather than a user that is firing up their client for the first time on the network, but still deserves to be on the list until we rule it out.
2. User’s can be redirected to our desired IP address at the router level. This is how most “Captive Portals” as these are known as, are implemented. A “captive portal” is what you deal with when you access any corporate network – for instance, at a hotel, the airport, or when you’re somewhere like whole foods – it makes you login or give a code or do whatever so you will be allowed to access anything else on the network.For us, we’re not trying to limit what people can access, since there’s nothing but our stuff on this network – although that might be a useful tool in the future, if resources are limited and a certain page accessible on the LoRa network is hogging all the bandwidth :)For us, we’re just trying to make it easy for new users to find the only page that exists, by taking them there automatically when they fire up their browser.

#### Antenna Info

Matteo has created a 3D printable antennae stand (need link to file here) that also doubles as a ruler for measuring just the right length of wire to use for the best reception of a specific frequency.

Link to 3D printer file for the antennae stand here

photo

idea is that you use the 3d printed part both as the whip antenna holder and as a meaasure to cut the antenna wire with

Our LoRa network uses 915MZ as its frequency. Different frequencies will use different lengths of wire on our antennae ruler/stand. You can use the ruler to measure exactly the right length of wire for your antennae, before you cut it. (You can use this tool to make a better antennae for your wifi router too this way.)

1) Print out our antennae stand/ruler for frequency wire length tool

2) Use the tool to measure the desired length of wire for your antennae, and cut it

3) Slide the wire through the antennae stand

4) Connect the antennae to your LoRa repeater or Wifi Router

Be careful where you place your repeater, as the antennae itself can shadow the solar panel and interfere with it’s ability to capture power from the sun.

This antennae is supposed to work for longer distances, like 25 miles – and our software is already configured to work with it: https://www.digikey.com/en/products/detail/digi/XBP9B-XCST-001/3482817

When it’s time to actually make your antennae, go here: https://www.aaronswartzday.org/givemelora/#antennaes

More info about antennae here:

Antennas

http://www.shopantenas.com.br/antena-movel-uhf-5-8…

Antenna mount:

http://www.shopantenas.com.br/suporte-magnetico-preto-p–antena-movel/p

Note: You generally want to use as big of an an antenna as is possible while still being practical to carry around (in the case of a pocket pylon).

For the fixed “pylon” repeaters, there is a concern that the antennae aren’t so big as to draw too much attention – as is the reason for keeping the size of the solar panels used as small as possible. (So they don’t get stolen.)

#### Next Steps

1) make a basic repeater with just an arduino and a semtech chip
(get a POS $1 arduino to do repeater things) Note: ideally, these will be able to be made cheaper than our original prototype (see pics above) – and, most importantly, will use a lot less power.

2) Getting an antenna reasonably high up where Matteo is – in San Rafael – (~1.5-2m above building) – so we can try some long range tests.

#### Additional Features for next version

Re: encryption

Sure. Eventually, it would be nice to have some encryption available for sensitive messages. Right now, we think it would be more useful to be able to say “I’m here help” over an open network than to have no options at all.

re: bulletin boards

Since we are dealing with slow model speeds, someone suggested implementing a bulletin board system of sorts. So Matteo build one. This “bulletin board” is just a little website that has only has 10 message slots but there can be up to 255.

Why a bulletin board system? Because LoRa is as slow as some of the earliest modem speeds – 9600 baud or lower even – so why not go back to the types of communication platforms that were used in the 90’s when bandwidth was going that slow.

#### Software Libraries (we used to write our node software)

RadioHead Packet Radio library for embedded microprocessors
http://www.airspayce.com/mikem/arduino/RadioHead/
This is the RadioHead Packet Radio library for embedded microprocessors. It provides a complete object-oriented library for sending and receiving packetized messages via a variety of common data radios and other transports on a range of embedded microprocessors.

The version of the package that this documentation refers to can be downloaded from http://www.airspayce.com/mikem/arduino/RadioHead/RadioHead-1.107.zip You can find the latest version of the documentation at http://www.airspayce.com/mikem/arduino/RadioHead

#### Definitions of some basic terms to help people new to the project understand what we are doing

Access point:

Gateway:

Router:

Repeater:

Wifi:

Bluetooth:

LoRa:

#### Word Compression Consideration

Why might we want word compression for our LoRa network?
The “commercial code” below is one of several methods that one can use to achieve excellent “word compression” for english words. “Word compression” is a concept that originated during the old days of telegrams and systems where you paid for every word to be transmitted. In our case, every word counts because our network bandwidth is so limited – and is literally as slow as the old dial-up modems of the 90s. (As slow as 9,600 – 12,000 baud modems)

These codes are examples of what is called “dictionary compression.” An application is written in such a way that it recognizes common phrases, like “what time should we meet?” and assigns it a code that will necessitate transmitting fewer characters.

The way it works: The application (in this case our texting app & bulletin board app) – recognizes the phrase the person has typed and then uses a shorter abbreviation to represent it – sends the code (that uses less characters) across the network – where it is decoded on the receiver’s side into the original message. This is similar to the autocorrect functions that everyone is used to using on their phones.

What would creating our own codes involve?

Creating our own codes would involve determining the 32768 most common words in english – perhaps algorithmically.

Why don’t we use lossless text compression then instead of codes?

Because compression not optimized for text doesn’t go very far for short messages. To demonstrate this concept, one can take any one sentence typed here, save it as a text file, zip the text file, and see that it won’t be much shorter.

Why are we discussing this for this project?

(This subject came up because there’s a big emphasis in sending as few bytes as possible on the LoRa discussion forums.)

Let’s say that we take the most common 32768 words in the english language (the other 32767 are pairs of ASCII characters that disallow control characters, so losing one bit out of 16 i not a big problem). Now each word, or even common phrase, if we want, fits two bytes. You can even do a bit of cleanup so that “how are you” and “how r u” and so on map to the same thing, and are printed “how are you” at the receiving end unless tagged “verbatim.” [? (Note: we haven’t discussed tagging messages? let’s! :) ?]

Note: This is done phone/pc side where you have a lot of hard disk space for a dictionary and a lot of cpu power for realtime substitution.

Note: Interestingly, you can even XOR the -dictionary- with a crypto key for private messaging, and if you swap those often enough, that’s your encryption solution. (Not unbeatable of course, but since it can be of arbitrary length, you could even have a one time pad, which IS unbeatable by definition). This type of “encryption” won’t slow things down as much, as it’s just a XOR operation that you do once on the dictionary. So, not unbeatable, but decent. And not super secure in that it requires a shared key, but eh.

Lisa thinks it sounds like a project in itself, but Matteo thinks it’s not necessarily a big job, it’s just a case of finding out what the most common X words in Y language are, and sorting them. Or you can just scrape a dictionary and sort it alphabetically if you are lazy.

Commercial code (communications)
https://en.wikipedia.org/wiki/Commercial_code_(communications)
“In telecommunication, a commercial code is a code once used to save on cablegram costs.[1] Telegraph (and telex) charged per word sent, so companies which sent large volumes of telegrams developed codes to save money on tolls.”

For Later:

#### Other LoRa Hardware

Hardware we think might work, if we create a LoRa gateway for it

The Ark
https://github.com/thearkadia/The_Ark/blob/master/README.md

LORA1276|FCC|CE|868 915MHz|100mW|Lora module|wireless RF module| long range transceiver module
https://www.nicerf.com/product_146_136.html

#### LoRa Install Guide

Installing our LoRa software (https://github.com/AaronSwartzDay-SSP/LoRa) on your esp32

Arduino firmware install instructions (https://www.aaronswartzday.org/lorasetup/#arduinofirmware)

More detailed instructions for both models are here: https://www.aaronswartzday.org/lorasetup

The esp32 does not have a toolkit, but you can use the arduino toolkit with a plugin module to get it to work on the esp32. (add links)

1) On your computer, install the arduino toolkit, and the esp 32 plugin that works with the arduino toolkit.

2) Use the toolkit to put our LoRa software on your device.

3) Take any web-enabled device and fire up a browser type in the IP address 192.168.x.1

4) Type in your message in the form field and click “send” – to send a message to everyone on the network that also has the page loaded.

5) Users can refresh the page to see new messages.

The page will save and display the last 10 messages sent. (We are working on having a second page that displays the last 100 messages.)



#### Troubleshooting Info

Troubleshooting Info here

#### Tech Support

contact: cellsol@robots-everywhere.com

## Virtual Hackathon Starts November 7, 2020

# Recent Posts

- The Intentionality of Evil (https://www.aaronswartzday.org/the-intentionality-of-evil/)
- Angela Davis: This is a very exciting moment. (https://www.aaronswartzday.org/angela-davis/)
- Supreme Court: All federal laws that prohibit discrimination on the basis of sex also outlaw discrimination based on sexual orientation or gender identity (https://www.aaronswartzday.org/supreme-court-titlevii-decision/)
- How to use Bridgefy as an Emergency Mesh Network (https://www.aaronswartzday.org/bridgefy-tutorial/)
- New “Toolkit” from the ACLU & Oakland Privacy Can Help You Get A Surveillance Ordinance Passed (https://www.aaronswartzday.org/surveillance-ordinance-toolkit/)

# Categories

- Aaron Swartz Day 2013 (https://www.aaronswartzday.org/category/aaron-swartz-day-2013/)
- Aaron Swartz Day 2014 (https://www.aaronswartzday.org/category/aaron-swartz-day-2014/)
- Aaron Swartz Day 2015 (https://www.aaronswartzday.org/category/aaron-swartz-day-2015/)
- Aaron Swartz Day 2016 (https://www.aaronswartzday.org/category/aaron-swartz-day-2016/)
- Aaron Swartz Day 2017 (https://www.aaronswartzday.org/category/aaron-swartz-day-2017/)
- Aaron Swartz Day 2018 (https://www.aaronswartzday.org/category/aaron-swartz-day-2018/)
- Aaron Swartz Day 2018 – Projects (https://www.aaronswartzday.org/category/aaron-swartz-day-2018-projects/)
- Aaron Swartz Hackathon 2014 – Projects (https://www.aaronswartzday.org/category/aaron-swartz-hackathon-2014-projects/)
- Aaron Swartz Hackathon 2016 – Projects (https://www.aaronswartzday.org/category/aaron-swartz-hackathon-2016-projects/)
- Aaron Swartz International Hackathon 2014 (https://www.aaronswartzday.org/category/aaron-swartz-international-hackathon-2014/)
- Aaron Swartz International Hackathon 2015 (https://www.aaronswartzday.org/category/aaron-swartz-international-hackathon-2015/)
- Aaron Swartz International Hackathon 2016 (https://www.aaronswartzday.org/category/aaron-swartz-international-hackathon-2016/)
- Aaron Swartz International Hackathon 2017 (https://www.aaronswartzday.org/category/aaron-swartz-international-hackathon-2017/)
- Aaron Swartz International Hackathon 2017 – Projects (https://www.aaronswartzday.org/category/aaron-swartz-international-hackathon-2017-projects/)
- Aaron Swartz International Hackathon 2018 (https://www.aaronswartzday.org/category/aaron-swartz-international-hackathon-2018/)
- Aaron Swartz Memorial – San Francisco (https://www.aaronswartzday.org/category/aaron-swartz-memorial-san-francisco/)
- Aaron's FOIA Requests (https://www.aaronswartzday.org/category/aarons-foia-requests/)
- Aaron's Writings (https://www.aaronswartzday.org/category/aarons-writings/)
- Announcements (https://www.aaronswartzday.org/category/announcements/)
- Art (https://www.aaronswartzday.org/category/art/)
- ASD Next Phase Events (https://www.aaronswartzday.org/category/asd-next-phase-events/)
- ASD Police Surveillance Project (https://www.aaronswartzday.org/category/asd-police-surveillance-project/)
- Audio (https://www.aaronswartzday.org/category/audio/)
- Chelsea Manning (https://www.aaronswartzday.org/category/chelsea-manning/)
- Copyright (https://www.aaronswartzday.org/category/copyright/)
- Creative Commons (https://www.aaronswartzday.org/category/creative-commons/)
- Decentralized Web (https://www.aaronswartzday.org/category/decentralized-web/)
- Digging Deeper (https://www.aaronswartzday.org/category/digging-deeper/)
- Digital Privacy Suggestions (https://www.aaronswartzday.org/category/digital-privacy-suggestions/)
- Documentaries – Press Freedoms (https://www.aaronswartzday.org/category/documentaries-press-freedoms/)
- DWebCamp (https://www.aaronswartzday.org/category/dwebcamp/)
- Electronic Frontier Foundation (https://www.aaronswartzday.org/category/electronic-frontier-foundation/)
- Ethical Algorithms (https://www.aaronswartzday.org/category/ethical-algorithms/)
- Facebook Fake News Fiasco (https://www.aaronswartzday.org/category/facebook-fake-news-fiasco/)
- Facing the Great Reckoning Head On (https://www.aaronswartzday.org/category/facing-the-great-reckoning-head-on/)
- Fight For The Future (https://www.aaronswartzday.org/category/fight-for-the-future/)
- First Amendment (https://www.aaronswartzday.org/category/first-amendment/)
- FOIA Lawsuits (https://www.aaronswartzday.org/category/foia-lawsuits/)
- FOIA Requests (https://www.aaronswartzday.org/category/foia-requests/)
- Freedom of the Press (https://www.aaronswartzday.org/category/freedom-of-the-press/)
- Freedom of the Press Foundation (https://www.aaronswartzday.org/category/freedom-of-the-press-foundation/)
- Game Development (https://www.aaronswartzday.org/category/game-development/)
- Grand Jury Transformation (https://www.aaronswartzday.org/category/grand-jury-transformation/)
- History (https://www.aaronswartzday.org/category/history/)
- International Rights Treaties (https://www.aaronswartzday.org/category/international-rights-treaties/)
- Internet Archive (https://www.aaronswartzday.org/category/internet-archive/)
- Journalist's Toolbox (https://www.aaronswartzday.org/category/journalists-toolbox/)
- Library Freedom Project (https://www.aaronswartzday.org/category/library-freedom-project/)
- Live Streamed Events (https://www.aaronswartzday.org/category/live-streamed-events/)
- Live Webcast Link (https://www.aaronswartzday.org/category/live-webcast-link/)
- MayDay PAC (https://www.aaronswartzday.org/category/mayday-pac/)
- Movies (https://www.aaronswartzday.org/category/movies/)
- Music (https://www.aaronswartzday.org/category/music/)
- New Hampshire Rebellion January Walk (https://www.aaronswartzday.org/category/new-hampshire-rebellion-january-walk/)
- Official Government Responses (https://www.aaronswartzday.org/category/official-government-responses/)
- OpAaronSwartz (https://www.aaronswartzday.org/category/opaaronswartz/)
- Opening Night Party (https://www.aaronswartzday.org/category/opening-night-party/)
- Opsec (https://www.aaronswartzday.org/category/opsec/)
- PACER (https://www.aaronswartzday.org/category/pacer/)
- Police Misconduct (https://www.aaronswartzday.org/category/police-misconduct/)
- Political Ad Archive (https://www.aaronswartzday.org/category/political-ad-archive/)
- Poulsen v. DHS (https://www.aaronswartzday.org/category/poulsen-v-dhs/)
- Press (https://www.aaronswartzday.org/category/press/)
- Privacy Hackathons (https://www.aaronswartzday.org/category/privacy-hackathons/)
- Privacy-enabling Mini-Conference 2015 (https://www.aaronswartzday.org/category/privacy-enabling-conference-2015/)
- Public Access to the Public Domain (https://www.aaronswartzday.org/category/public-access-to-the-public-domain/)
- Q & A with Brian Knappenberger (https://www.aaronswartzday.org/category/q-a-with-brian-knappenberger/)
- Raw Thought at The DNA Lounge (https://www.aaronswartzday.org/category/raw-thought-at-the-dna-lounge/)
- Reform the CFAA (https://www.aaronswartzday.org/category/reform-the-cfaa/)
- Remembering Aaron (https://www.aaronswartzday.org/category/remembering-aaron/)
- Remembering John Perry Barlow (https://www.aaronswartzday.org/category/remembering-john-perry-barlow/)
- Save Net Neutrality (https://www.aaronswartzday.org/category/save-net-neutrality/)
- SecureDrop (https://www.aaronswartzday.org/category/securedrop/)
- Solar Survival (https://www.aaronswartzday.org/category/solar-survival/)
- Student Innovator Protections (https://www.aaronswartzday.org/category/student-innovator-protections/)
- Supreme Court Decisions (https://www.aaronswartzday.org/category/supreme-court-decisions/)
- Surveillance (https://www.aaronswartzday.org/category/surveillance/)
- Surveillance Reform (https://www.aaronswartzday.org/category/surveillance-reform/)
- Swartz-Manning VR Destination (https://www.aaronswartzday.org/category/swartz-manning-vr-destination/)
- Takepart.com Articles (https://www.aaronswartzday.org/category/takepart-com-articles/)
- Tech's Great Reckoning (https://www.aaronswartzday.org/category/techs-great-reckoning/)
- The Constitution (https://www.aaronswartzday.org/category/the-constitution/)
- The Good Fight with Ben Wikler (https://www.aaronswartzday.org/category/the-good-fight-with-ben-wikler/)
- The Internet's Own Boy (https://www.aaronswartzday.org/category/the-internets-own-boy/)
- The Internet's Own Boy – Awards (https://www.aaronswartzday.org/category/the-internets-own-boy-awards/)
- The Internet's Own Boy – Press (https://www.aaronswartzday.org/category/the-internets-own-boy-press/)
- The Internet's Own Boy – Screenings (https://www.aaronswartzday.org/category/the-internets-own-boy-screenings/)
- The Week In Aaron Swartz Day-Land (https://www.aaronswartzday.org/category/the-week-in-aaron-swartz-day-land/)
- Tor Project (https://www.aaronswartzday.org/category/tor/)
- Transcripts (https://www.aaronswartzday.org/category/transcripts/)
- Uncategorized (https://www.aaronswartzday.org/category/uncategorized/)
- Video (https://www.aaronswartzday.org/category/video/)
- Virtual Reality (https://www.aaronswartzday.org/category/virtual-reality/)

# Archives

- October 2020 (https://www.aaronswartzday.org/2020/10/)
- June 2020 (https://www.aaronswartzday.org/2020/06/)
- May 2020 (https://www.aaronswartzday.org/2020/05/)
- January 2020 (https://www.aaronswartzday.org/2020/01/)
- September 2019 (https://www.aaronswartzday.org/2019/09/)
- August 2019 (https://www.aaronswartzday.org/2019/08/)
- July 2019 (https://www.aaronswartzday.org/2019/07/)
- June 2019 (https://www.aaronswartzday.org/2019/06/)
- May 2019 (https://www.aaronswartzday.org/2019/05/)
- March 2019 (https://www.aaronswartzday.org/2019/03/)
- February 2019 (https://www.aaronswartzday.org/2019/02/)
- January 2019 (https://www.aaronswartzday.org/2019/01/)
- December 2018 (https://www.aaronswartzday.org/2018/12/)
- November 2018 (https://www.aaronswartzday.org/2018/11/)
- October 2018 (https://www.aaronswartzday.org/2018/10/)
- August 2018 (https://www.aaronswartzday.org/2018/08/)
- July 2018 (https://www.aaronswartzday.org/2018/07/)
- June 2018 (https://www.aaronswartzday.org/2018/06/)
- May 2018 (https://www.aaronswartzday.org/2018/05/)
- April 2018 (https://www.aaronswartzday.org/2018/04/)
- March 2018 (https://www.aaronswartzday.org/2018/03/)
- February 2018 (https://www.aaronswartzday.org/2018/02/)
- January 2018 (https://www.aaronswartzday.org/2018/01/)
- December 2017 (https://www.aaronswartzday.org/2017/12/)
- November 2017 (https://www.aaronswartzday.org/2017/11/)
- October 2017 (https://www.aaronswartzday.org/2017/10/)
- September 2017 (https://www.aaronswartzday.org/2017/09/)
- July 2017 (https://www.aaronswartzday.org/2017/07/)
- March 2017 (https://www.aaronswartzday.org/2017/03/)
- February 2017 (https://www.aaronswartzday.org/2017/02/)
- January 2017 (https://www.aaronswartzday.org/2017/01/)
- December 2016 (https://www.aaronswartzday.org/2016/12/)
- November 2016 (https://www.aaronswartzday.org/2016/11/)
- October 2016 (https://www.aaronswartzday.org/2016/10/)
- July 2016 (https://www.aaronswartzday.org/2016/07/)
- February 2016 (https://www.aaronswartzday.org/2016/02/)
- January 2016 (https://www.aaronswartzday.org/2016/01/)
- December 2015 (https://www.aaronswartzday.org/2015/12/)
- November 2015 (https://www.aaronswartzday.org/2015/11/)
- October 2015 (https://www.aaronswartzday.org/2015/10/)
- February 2015 (https://www.aaronswartzday.org/2015/02/)
- January 2015 (https://www.aaronswartzday.org/2015/01/)
- November 2014 (https://www.aaronswartzday.org/2014/11/)
- October 2014 (https://www.aaronswartzday.org/2014/10/)
- August 2014 (https://www.aaronswartzday.org/2014/08/)
- July 2014 (https://www.aaronswartzday.org/2014/07/)
- June 2014 (https://www.aaronswartzday.org/2014/06/)

# Meta

- Log in (https://www.aaronswartzday.org/wp-login.php)
- Entries feed (https://www.aaronswartzday.org/feed/)
- Comments feed (https://www.aaronswartzday.org/comments/feed/)
- WordPress.org

Proudly powered by WordPress (https://wordpress.org/)

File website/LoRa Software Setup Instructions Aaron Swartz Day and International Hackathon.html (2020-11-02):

# Aaron Swartz Day and International Hackathon (https://www.aaronswartzday.org/)

Search

Search for:

# LoRa Software Setup Instructions

Last Updated: October 14, 2020

Our main page for indexed LoRa info is here: aaronswartzday.org/LoRa

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

How to install the software on the Esp32

Here are some part lists for building “pylons” (https://www.aaronswartzday.org/lora/#pocketnode) (A pylon is: a LoRa receiver/transmitter – whether it lives on a rooftop or in your pocket) – to build your own network

1. Plug your esp32 into the computer

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

https://dl.espressif.com/dl/package_esp32_index.json

 (https://www.aaronswartzday.org/wp-content/uploads/2020/10/Preferences-Arduino-SDK-BoardsManagerURL.png)

4. Click OK and close & restart the program

5. Go to “Tools”

“Board”

“Board Manager”

SCREENGRAB SELECTING THIS

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

 (https://www.aaronswartzday.org/wp-content/uploads/2020/10/Boards-Manager.png)

6. Go to “Tools” “Board” “esp32” and select “Helltec Wifi LoRa 32 (v2)”

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

 (https://www.aaronswartzday.org/wp-content/uploads/2020/10/Tools-Board-Heltec-Wifi-LoRa-32V2.png)

7. There are drivers you need to install before it will compile properly:

PC drivers are here:

need to list and find these

Mac drivers are here:

need to list these

https://www.silabs.com/products/development-tools/software/usb-to-uart-bridge-vcp-drivers

Esp32 docs here:

https://docs.espressif.com/projects/esp-idf/en/latest/esp32/get-started/index.html

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

Once you have the name, it’s easy to find and install the libraries you need.

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

 (https://www.aaronswartzday.org/wp-content/uploads/2020/10/LoRa-Library-Manager.png)

10. Select the Port – “Port-dev-cu.SLAB_USBtoUART”

 (https://www.aaronswartzday.org/wp-content/uploads/2020/10/Port-dev-cu.SLAB_USBtoUART.png)

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

https://github.com/AaronSwartzDay-SSP/LoRa

What’s in our software package:

TREE OF SOFTWARE

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

“esp32_wifi_bt_or_gateway.ino”

#### Creating a Gateway

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

1. remove the “//” in front of “//#define WIFI_IS_CLIENT”

// Uncomment the above to enable use as a gateway.

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

PICTURE of IP ADDRESS on screen of esp32

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

SCREENGRAB HERE OF ACCESSING 192.168.1.200 over the gateway.

Screengrab here of the messages (a) on screen of #3 esp

Screengrabs here of the messages (a) and (b) on phone 1 & phone 2

Screengrab of Phone 1 with Login as result of captive portal page

Screengrab of Phone 1 with messages (a)

Screengrab of Phone 1 with messages (a) and (b)

Screengrab of Phone 2 captive portal page with messages (c) showing

#### Cases for your esp32

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

A few details for those interested re: 3D printing cases:

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

So for 3D printing – increase your schematic in size by 1%

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

#### How to build an Arduino-based pylon and install & configure its software

Arduino set up instructions

Why we created the arduino model:

1) It is a lot cheaper to build

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

BLOCK DIAGRAM (Logic)

(LoRa transceiver)—-(Arduino)—-(Bluetooth/serial module)

BLOCK DIAGRAM (Power)

Power input —– 3.7v switching reg ——– 3.3v LDO linear reg —- active components
\– battery

POWERING THE NODE

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

* 6V lead-acid battery, connected to the USB power input port.

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

* 3 alkaline cells (AAA to D cells) in series. Important: these must be NON-rechargeable!

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

* USB hand crank. If you use this, the node MUST have a secondary battery.

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

BATTERY TYPES FOR THE NODE

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

* 3.6V lithium battery. Any type is fine (Old cell phone battery, etc).

* 3 rechargeable cells (AAA to D cells) in series. Important: these must be rechargeable!

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

Building the Arduino Pylon

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

#### Loading the Firmware

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

CONNECTING TO THE PYLON AND SENDING MESSAGES TO IT

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

For iPhone, you will likewise have to find a Bluetooth terminal app.

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

CARE AND FEEDING

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

# Movie Trailer – From DeadDrop to SecureDrop

# The Internet’s Own Boy

WATCH IT NOW (https://archive.org/details/TheInternetsOwnBoyTheStoryOfAaronSwartz).

## Virtual Hackathon Starts November 7, 2020

# Recent Posts

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

# Categories

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

# Archives

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

# Meta

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

Proudly powered by WordPress (https://wordpress.org/)

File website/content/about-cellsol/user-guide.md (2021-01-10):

---
publishdate: 2019-11-17
lastmod: 2020-12-07
---

# CellSol WiFi Pylon User Guide

This is a short how-to on how to use the CellSol WiFi Pylons. It is also packaged with the pylons themselves.

## Basic Concepts

CellSol is free to use and does not depend on any infrastructure, each pylon is self-contained: just deploy a few of them in an area and you are good to go.

This is a lot like existing LoRa mesh chat systems, except that it's intended to leave repeaters in place.

It will honor other mesh network systems by repeating their packets too, as long as they start with a xxxx: tag in front.

## About the Chat System

By using the chat in the main page, you will be able to communicate with people who are in range of the CellSol network, or people who are using CellSol gateways.

Each message is sent out to neighboring pylons, which can be a few kilometers apart, and rebroadcast.

You can consider this system akin to a single IRC/Discord/Twitch chat channel, except it will work when the internet at large will not.

Please note that CellSol does not store your location or identity data, but also please note that there is no encryption for these messages (to make it easier for other systems to interoperate with). This is intended to be used during or after natural disasters, so that should really not be a concern.

## Identifying Users

The tag in front of your message is a pseudonymous identifier used to tell people apart. It is four hex digits. We chose to remove nicknames, to simplify the data. You can always add one to your message.

CellSol Web Interface with Help Highlights

## About Bluetooth and Repeater Pylons

Any phone with a Bluetooth chat app (available from our [github](https://github.com/RbtsEvrwhr-Riley/CellSol/) or from any pylon) can also use Bluetooth equipped repeater pylons, or the WiFi pylons. If you are on an iPhone, you will
need to use a Bluetooth terminal app, such as "BluTerm". We do not work on or endorse any third party apps.

If you are on a Bluetooth or serial CellSol pylon, typing ,,, on a line by itself will dump the pylon's status and last received strings (in case your phone loses them). Our app does this automatically on reconnect.

## Chatting with IRC (Internet Relay Chat)

By default, your pylon will connect to IRC on irc.rizon.net port 6667, and create or join the channel CellSol.

You can also connect to this (or whatever channel you have configured, see the [assembly instructions]({{< ref "/cellsol-equipment/esp32/assembly-instructions" >}})
by using any IRC client.

Once you have connected to IRC and joined the channel, you should see a number of users whose names begin with CellSol and end in 4 hex digits. These
are the IRC users for the CellSol nodes currently connected to the channel. These users will relay messages from their node to the IRC channel, starting
with the 4 hex digit code of the user that sent the message, followed by the message itself, just like on the CellSol web interface.

Messages from non-pylon users on the IRC channel will not automatically be relayed by the connected CellSol nodes, in order to save bandwidth. For a message
to be forwarded onto the network by the connected nodes, it must start with that node's chosen prefix (default is ~~). It is most useful if all nodes
connecting to the same IRC channel be set up to have the same prefix, and that the topic of the IRC channel is set to report that prefix correctly.

Photo of CellSol and IRC relaying to each other using Rizon network

We hope you enjoy the new IRC feature!

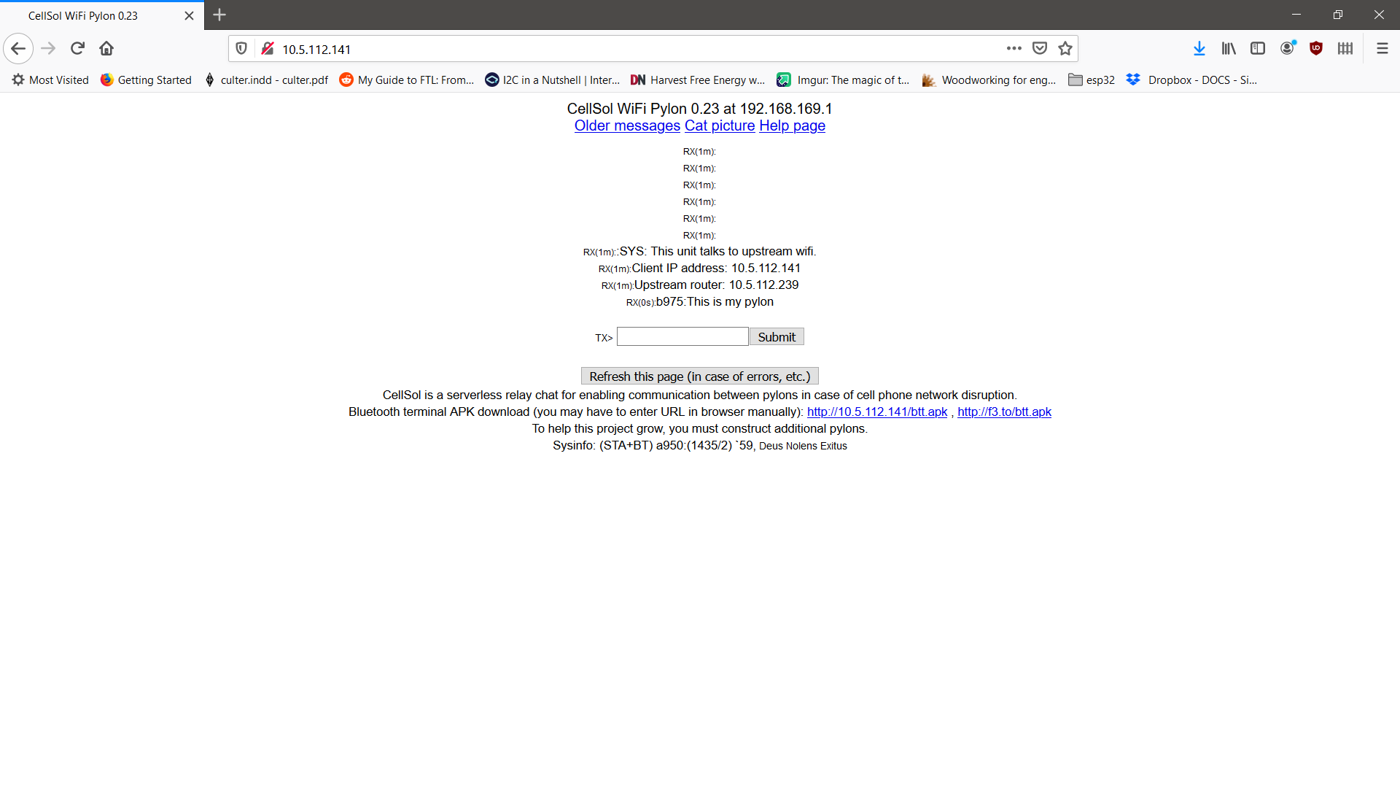
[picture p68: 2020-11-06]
website/content/cellsol-equipment/esp32/assembly-instructions/photos/fig6_webinterface.png

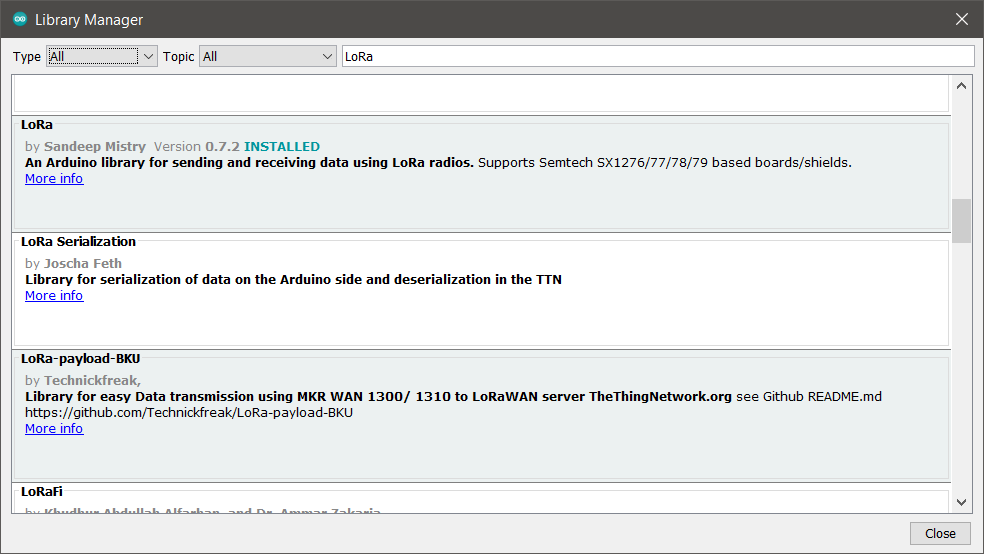
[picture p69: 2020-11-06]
website/content/cellsol-equipment/esp32/assembly-instructions/photos/fig4_librarymanager_lora.png

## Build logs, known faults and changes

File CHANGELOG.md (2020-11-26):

## 0.25
* Added changelog
* Changed web form submit on ESP32 WiFi Pylon firmware to use REST API
## 0.24 
* Initial beta release

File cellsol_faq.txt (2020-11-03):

CellSol FAQ

* What is this?
It's a means of emergency communication based upon solar-powered "pylons" consisting of a transceiver, a Bluetooth serial adapter, and a WiFi access point.

* Is it a mesh network?
Not quite. Each pylon is also a repeater, but there is no user level routing. It's more like a single Discord or IRC channel, everyone can read what everyone else types. There's no private messaging. We may implement channels and user level routing in the future.

* Is it encrypted?
No. The idea is to make it easy to talk. Not encrypting it makes it easier for people to build their own nodes. You can encrypt the content of your own message if you like.

* What's the difference between this and other text systems designed for hikers?
It's intended to also have permanently affixed pylons that can act as repeaters and can be accessed by any device with WiFi or Bluetooth. It's open source and you are encouraged to build your own. It has its own memory so that you can turn your phone off and still get messages.

* Can I carry a pylon around? Will that interfere with pre-positioned pylons?
You can (in fact, please do!) and it will not interfere. Bluetooth pylons will work with any phone that has Bluetooth (Android, iOS, even old Blackberries). The CellSol circuit will let you send and receive message, and you will act as a repeater, extending the range and reliability of the network near you.

* What's the range for each pylon?
Absolute worst case scenario, 500 meters (using a piece of chicken wire as an antenna). Best case scenario, a few kilometers.

* Can this link to the wider internet?
Yes. A pylon configured as a gateway can be accessed by the wider internet. This is useful if, say, you're doing field research, your base camp has a net connection, and you don't want to give a satellite phone to everyone.

* Why the name?
It stands for Cellular-Solar. It's from a 1990s sci fi story. We liked it.

*Is this LoRaWAN?
No, it's intentionally set on a slightly different radio channel from LoRaWAN specifically so that it doesn't interfere with it (and vice versa). But it uses the LoRa encoding, so if you want to make it LoRaWAN compatible, you can.

*What are the four characters in front of my message?
That's your identifier; it's like a nickname in a chat. It's autocalculated in a way that it doesn't give away your information, such as your phone's hardware address, while making sure other people can't pretend to be you or cause confusion as to who's talking.

*How do I connect via WiFi?
If you see an access point called "CellSol" and then an IP address (four numbers), just connect to it, there's no password. You will be taken to the chat page in a few moments. If you are not, open a browser and type in the four numbers you saw, connected by dots like you saw them.

*How do I connect via Bluetooth?
Some CellSol access points will identify themselves as CellSollBT and a number; some won't. Download either our chat app, or ANY Bluetooth terminal, then connect to the access point like you would to a regular bluetooth device, then you can use the terminal window as a chat window. You can download the CellSol app from any WiFi CellSol pylon if the internet is already down, or from the CellSol website, or from Google Play. If you have an iPhone or other non-Android phone, you can use ANY bluetooth terminal or bluetooth chat app. Type three commas (,,,) in a row and if you are connected correctly, you will get a status message and a summary of the last few messages that the pylon has received.

*How do I connect via serial port?
Just use a TTL serial port adapter (Parallax PropPlug, FTDI adapter for Arduino, etc). The baud rate is 9600 in most cases. If that does not work, try 2400. Type three commas (,,,) in a row and if you are wired correctly, you will get a status message and a summary of the last few messages that the pylon has received.

*Can I power the CellSol circuit from my USB-C phone?
Yes! But we don't recommend doing that in WiFi mode for the ESP32 circuit. Switch to Bluetooth mode or use one of the other circuits.

*I have an ESP32 CellSol circuit. How do I switch modes?
To switch to Bluetooth, press RESET and then immediately after press PROG, and keep it pressed until the display lights up and says CellSolBT. To switch back to WiFi, press RESET and leave PROG alone.

*I have an Arduino CellSol circuit. How do I switch modes?
The Arduino only supports Bluetooth and serial mode, there's no need to switch.

* What is the message size limit?
180 characters. You can send messages every 2 seconds.

* Can someone locate me if I use CellSol?
Not unless they have a radio direction finder. CellSol does not transmit location or identity. If you do want someone to find you, you can send them your GPS coordinates.

* Can I send images or video? Can I send links?
No, the system is optimized for range and low power consumption, not bandwidth. The goal is to be able to coordinate beetween field researchers, or explain and provide immediate needs in an emergency situation. You can send a link, but since the system is designed to be used where there's no internet, it may not do much good.

* Is there a connection limit?
The identifier is 4 bytes, and there are a few reserved values, so the effective limit is about 32000 users per CellSol mesh, after which you will start seeing duplicate identifiers (The messaging system will still work, however).

* I want to save my USB battery for my phone. What else can I power a CellSol pylon with?
A lot of things! It's very tolerant when it comes to voltages. See the assembly instructions for a partial list.

* Why do the pylons sometimes disappear from the WiFi access point list?
They're trying to save power by only advertising their presence some of the time. Wait a minute (60 seconds) and they'll be back, if they are operational. They only do this if nobody is connected.

* How do I help this project?
You must construct additional pylons. Then, give them to friends and/or deploy them in places where they can see each other! If it's not your property, be sure to ask permission.

* Will this interfere with other radios?
The 433Mhz version may interfere with some old garage door openers, but that is unlikely. The 915Mhz version will not.

* Do I need a permit to set up a pylon?
No. They use too little power for that (which is why they are text only... no free lunch!). This is true worldwide, as far as we can tell, with a few exceptions (near a radio telescope, etc). If you can set up a wifi router, you can set up a CellSol pylon.

* Can I connect a solar panel and a USB charger at the same time?
Maybe. Specifically, you can, BUT only if the USB charger is a wall-charger. Do not charge a CellSol pylon from a computer or phone/tablet if you also have a solar panel connected!

* What is Aaron Swartz Day?
Please see https://www.aaronswartzday.org/about/

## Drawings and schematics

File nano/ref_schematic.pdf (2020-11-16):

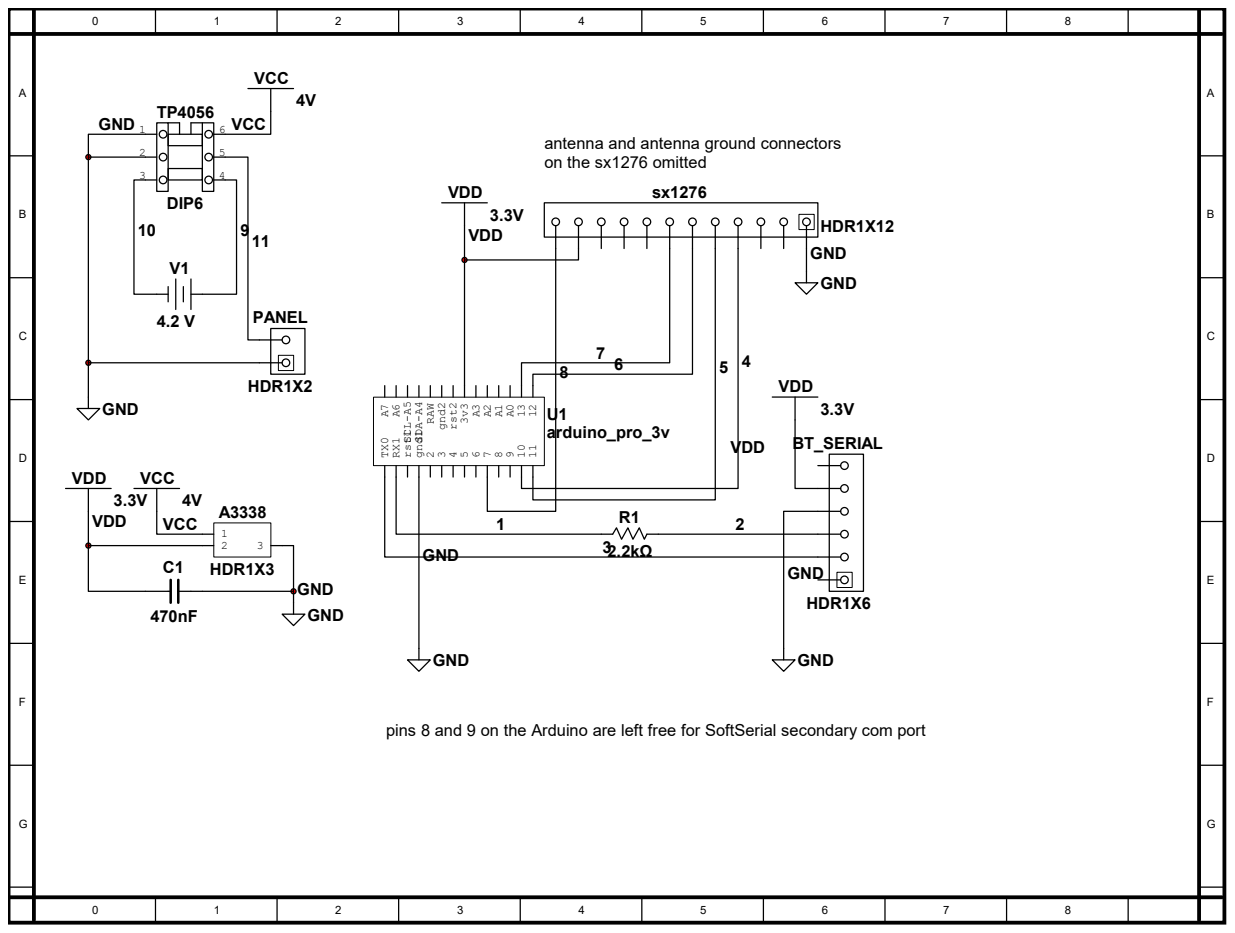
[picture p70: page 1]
U1 arduino_pro_3v; rst1; gnd1; gnd2; rst2; RAW; SCL-A5; SDA-A4; HDR1X3; GND; VCC; VDD; BT_SERIAL; HDR1X6; HDR1X12; DIP6; PANEL; HDR1X2

antenna and antenna ground connectors
on the sx1276 omitted

pins 8 and 9 on the Arduino are left free for SoftSerial secondary com port

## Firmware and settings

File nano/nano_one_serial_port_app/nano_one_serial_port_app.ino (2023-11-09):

/*********
  Cellular-Solar (CellSol) is a simple interconnect between lora, wifi and com port(s). It is intended to be used for infrastructure-independent comms during or after a disaster.
  (c) 2020 Robots Everywhere, LLC until we are ready to release it under copyleft
  Written by M K Borri. Thanks to Rui Santos for the tutorials. Thanks to Jerry Jenkins for the inspiration. Thanks to Lisa Rein for initiating the project.  Thanks to Robots Everywhere for infrastructure support https://www.robots-everywhere.com
  Originally produced as part of the Aaron Swartz Day project https://www.aaronswartzday.org
  Distributed independently https://www.f3.to/cellsol

  This file is used for Atmel328-based boards (Arduino Uno, Mini, Nano, etc).
*********/

#define VERSIONSTRING "0.34"

// Actual running speed is 2 Mhz most of the time. BE SURE TO SET THE SPEED CORRECTLY FOR YOUR ARDUINO WHEN PROGRAMMING THIS. Nothing bad happens if you get it wrong but it'll run at the wrong baud rate (4800 or 19200).
//#define GO_A_LOT_SLOWER // if defined, operate at 0.5Mhz, and keeps serial port running at 2400bps, further slows down processing. Useful for drone-droppable pylons that need a small panel. not recommended for bluetooth use since the bluetooth module will make the power saving irrelevant anyway.
//#define GO_FAST // if defined, operate at whatever the actual clock frequency is. Can be useful for applications which presumably use bigger panels anyway
#define USE_BATTERY_NOISE_FOR_ID // if undefined, same id across powerups. if not, use the last 2 bits as noise.

#define RECALLSIZE 251 // how many bytes to save? (must be <256 sorry)
#define RECALL_STRAY_CHARS // trim to packet, or keep last packet that went away?
#define CONDENSE_TAGS // if it's the same person messaging more than once, condense messages in memory. A bit slow.

#define SEND_TWICE // if defined, allow sending a packet twice after a pseudorandom delay, in case the first one got lost
#define RSSI_TRE_LO -120 // if sendtwice is defined, below this (for the last 4 received packets), turn on sendtwice
#define RSSI_TRE_HI -100 // if sendtwice is defined, above this (for the last 4 received packets), turn off sendtwice

//#define RX_ONLY // if defined, do not ever try to transmit. only really useful to partially salvage damaged radios.

#define APPLICATION // run a secondary application between pseudoseconds?
// list of possible applications
//#define AEROPONY // controls a hydroponics/aeroponics cell. see https://www.robots-everywhere.com/re_wiki/pub/web/Main.AeroponicCell.html
#define BASICPINS // turns available digital pins on and off; reads available analog pins



#define DO_NOT_LOG_SYSTEM_PACKETS
#define REBROADCAST_DISASTER_RADIO_PACKETS
//#define DISPLAY_DISASTER_RADIO_PACKETS

#define VOLTAGECUTOFF 3150 // if defined, system will go back to sleep if the system voltage is less than this.

//Libraries for LoRa
#include <SPI.h>
#include <LoRa.h>
#include <Prescaler.h>
#include <LowPower.h>
#include <avr/wdt.h>
#include <ArduinoUniqueID.h>

// used for scheduling
#include <TimerOne.h>

//define the pins used by the LoRa transceiver module
// it's pretty much how you wire the whole thing, too
#define SCK 13
#define MISO 12
#define MOSI 11
#define SS 10
#define RST 7 // 8 and 9 are used by altsoftserial
//#define DIO0 8 // not used right now?
//#define ANNOUNCE // tell the world we are alive

#define TAG_END_SYMBOL ':'
//433E6 for Asia
//866E6 for Europe
//915E6 for North America
#define BAND 9151E5 //Mhz just to stay away from center band
#define REQUIRE_TAG_FOR_REBROADCAST // if defined, require xxxx: tag for rebroadcast.
//#define REQUIRE_TAG_FOR_REBROADCAST_STRICT // on top of that, the first four characters must be hex digits.
#define BAD_CHARACTERS_MAX_DIVIDER 10
//#define SHOW_RSSI // if enabled, show RSSI for wireless packets coming in.

// Repeat sending the last message until you hear it back.
//#define REPEAT_UNTIL_ACK
//#define REPEAT_DELAY 500 // delay in ms

#ifdef REPEAT_UNTIL_ACK
boolean got_lora_ack = false;
long last_repeat_time = millis();
String message_to_repeat = "";
#endif

//packet counter
byte charcounter = 0;
boolean readytosend = false;

String LoRaData = ""; // god this is lazy. change to character array please
String LastWeGot = ""; // god this is lazy. change to character array please
String sendstr = "";

long LastThingISentViaLora_3 = 0; // this is now a checksum
long LastThingISentViaLora_2 = 0; // this is now a checksum
long LastThingISentViaLora_1 = 0; // this is now a checksum
long LastThingISentViaLora_0 = 0; // this is now a checksum
long LTISVL_3_time = 0;
long LTISVL_2_time = 0;
long LTISVL_1_time = 0;
long LTISVL_0_time = 0;

int i, j;

bool broadcast_twice = false;

#define MAXPKTSIZE 200
char receivedChars[MAXPKTSIZE]; // an array to store the received data
int rssi; // last packat received rss

#ifdef APPLICATION
char appcommand[16]; // an array to store the received data
#endif

unsigned long pseudoseconds = 0;
long UTC_Seconds = -1;

unsigned long psm = 0;
void PetTheWatchdog() {
  if (millis() > psm)
  {
    wdt_reset();
#ifdef GO_A_LOT_SLOWER
    psm = psm + 62; // 1000/16
#else
#ifdef GO_FAST
    psm = psm + 1000; // 1000/1
#else
    psm = psm + 250; // 1000/4
#endif
#endif
    pseudoseconds++;
#ifdef APPLICATION
    RunApplication();
#endif
    //    Serial.println(pseudoseconds);
  }
}


String hextag = "XXXX:"; // usually the last two IP octets; gives pseudonimity to sender
String fourhex(int num)
{
  num = num | 4096;
  /*
    if (num < 10)
    return "000" + String(num, HEX);
    if (num < 100)
    return "00" + String(num, HEX);
    if (num < 1000)
    return "0" + String(num, HEX);
    return String((num+0x1000, HEX);
  */
  return String(num, HEX);
}



inline void mydelay(int num) __attribute__((always_inline));
void mydelay(int num)
{
#ifdef GO_A_LOT_SLOWER
  delay((num / 4) | 1);
#else
#ifdef GO_FAST
  delay(num*4);
#else
  delay(num);
#endif
#endif
}

long readVcc() {
  // Read 1.1V reference against AVcc
  // set the reference to Vcc and the measurement to the internal 1.1V reference
#if defined(__AVR_ATmega32U4__) || defined(__AVR_ATmega1280__) || defined(__AVR_ATmega2560__)
  ADMUX = _BV(REFS0) | _BV(MUX4) | _BV(MUX3) | _BV(MUX2) | _BV(MUX1);
#elif defined (__AVR_ATtiny24__) || defined(__AVR_ATtiny44__) || defined(__AVR_ATtiny84__)
  ADMUX = _BV(MUX5) | _BV(MUX0) ;
#else
  ADMUX = _BV(REFS0) | _BV(MUX3) | _BV(MUX2) | _BV(MUX1);
#endif

  mydelay(2); // Wait for Vref to settle
  ADCSRA |= _BV(ADSC); // Start conversion
  while (bit_is_set(ADCSRA, ADSC)); // measuring

  uint8_t low  = ADCL; // must read ADCL first - it then locks ADCH
  uint8_t high = ADCH; // unlocks both

  long result = (high << 8) | low;

  result = 1125300L / result; // Calculate Vcc (in mV); 1125300 = 1.1*1023*1000
  return result; // Vcc in millivolts
}
int vcc = 0;

void(* resetFunc) (void) = 0;//declare reset function at address 0


void setup() {

  LastWeGot.reserve(RECALLSIZE + 6);
  LoRaData.reserve(MAXPKTSIZE + 6);
  sendstr.reserve(MAXPKTSIZE + 6);
  vcc = readVcc();

#ifdef USE_BATTERY_NOISE_FOR_ID
  hextag = fourhex(UniqueID8[6] * 256 + ((UniqueID8[7] & 15) + ((UniqueID8[7] + vcc) & 240))) + TAG_END_SYMBOL; // alter it slightly each time the note is powered on to allow proper pseudonimity // never changes, so run it at setup and leave it alone.
#else
  hextag = fourhex(UniqueID8[6] * 256 + UniqueID8[7]) + TAG_END_SYMBOL; // never changes, so run it at setup and leave it alone.
#endif

  if (hextag.charAt(3) == '0') // this unit is not set up to do service tasks, so don't end in 0
    hextag.setCharAt(3, '1');

#ifdef GO_FAST
  setClockPrescaler(0);
  Serial.begin(9600); // actually 2400
  Serial.println(":SYS: TAG:" + hextag + " VCC:" + String(vcc) + F(" VER:" VERSIONSTRING " UPT:0 CLK:" " FULL"));
#else
  // we want to run this at 0.5Mhz regardless if we are starting at 8 or 16.
#ifdef GO_A_LOT_SLOWER
#ifdef F_CPU
#if (F_CPU==16000000)
  setClockPrescaler(5); //0 == 16Mhz 1 == 8Mhz 2==4Mhz 3==2Mhz etc
  Serial.begin(76800); // actually 2400
  Serial.println(":SYS: TAG:" + hextag + " VCC:" + String(vcc) + F(" VER:" VERSIONSTRING " UPT:0 CLK:" " 16>0.5"));
#else
  setClockPrescaler(4); //0 == 8Mhz 1 == 4Mhz 2==2Mhz 3==1Mhz etc
  Serial.begin(38400); // actually 2400
  Serial.println(":SYS: TAG:" + hextag + " VCC:" + String(vcc) + F(" VER:" VERSIONSTRING " UPT:0 CLK:" "8>0.5"));
#endif
#else // assume 8Mhz
  setClockPrescaler(4); //0 == 8Mhz 1 == 4Mhz 2==2Mhz 3==1Mhz etc
  Serial.begin(38400); // actually 2400
  Serial.println(":SYS: TAG:" + hextag + " VCC:" + String(vcc) + F(" VER:" VERSIONSTRING " UPT:0 CLK:" " 8>0.5"));
#endif
#else
  // we want to run this at 2Mhz regardless if we are starting at 8 or 16.
#ifdef F_CPU
#if (F_CPU==16000000)
  setClockPrescaler(3); //0 == 16Mhz 1 == 8Mhz 2==4Mhz 3==2Mhz etc
  Serial.begin(76800); // actually 9600
  Serial.println(":SYS: TAG:" + hextag + " VCC:" + String(vcc) + F(" VER:" VERSIONSTRING " UPT:0 CLK:" " 16>2"));
#else
  setClockPrescaler(2); //0 == 8Mhz 1 == 4Mhz 2==2Mhz 3==1Mhz etc
  Serial.begin(38400); // actually 9600
  Serial.println(":SYS: TAG:" + hextag + " VCC:" + String(vcc) + F(" VER:" VERSIONSTRING " UPT:0 CLK:" " 8>2"));
#endif
#else // assume 8Mhz
  setClockPrescaler(2); //0 == 8Mhz 1 == 4Mhz 2==2Mhz 3==1Mhz etc
  Serial.begin(38400); // actually 9600
  Serial.println(":SYS: TAG:" + hextag + " VCC:" + String(vcc) + F(" VER:" VERSIONSTRING " UPT:0 CLK:" " 8>2"));
#endif
#endif
#endif

#ifdef GO_FAST
  SPI.setClockDivider(SPI_CLOCK_DIV4);
#else
  SPI.setClockDivider(1); // spi abuse courtesy of the fact that we are running at 2Mhz anyway // SPI_CLOCK_DIV2
#endif
  //initialize Serial Monitor
  //SPI LoRa pins
  SPI.begin();//SCK, MISO, MOSI, SS);
  //setup LoRa transceiver module
  LoRa.setPins(SS, RST);//, DIO0);

  LoRa.setSpreadingFactor(9); // default 7
  LoRa.setSignalBandwidth(62.5E3); //default 125E3
  //  LoRa.crc(); // we would rather get a damaged packet than no packet at all; maybe some of it will be readable.

  wdt_enable(WDTO_8S); // note that this is independent of clock speed.

  // stuff broke
  if (!LoRa.begin(BAND)) {
    Serial.println(F("Starting LoRa failed! Resetting."));
    wdt_disable();
    mydelay(200);
    resetFunc(); //call reset
  }

#ifdef GO_A_LOT_SLOWER
  LoRa.setTxPower(14, 1 ); // tests show that this is necessary to run from a small panel, which is the only reason why you'd want to slow down anyway
#else
  LoRa.setTxPower(19, 1 ); // PABOOST; for RFO use 14,0
#endif

#ifdef ANNOUNCE
#ifdef GO_A_LOT_SLOWER
  LoraSendAndUpdate(F("RPT UP(2400)\r\n"));
#else
  LoraSendAndUpdate(F("RPT UP(9600)\r\n"));
#endif
#endif

}

bool recalldots = false;

void ReadFromStream(Stream &st, char buf[], byte &cnt, bool &sendout)
{
  while (st.available() > 0)
  {
    buf[cnt++] = st.read();
    if (cnt > MAXPKTSIZE)
    {
      sendout = true;
      return;
    }
    if ((cnt > 1 and buf[cnt - 1] == 13))
    {
      sendout = true;

      // eat ascii 255s that that show up
      if ((buf[0]<6 or buf[0]>127) and cnt == 1)
        cnt = 0;

      if (buf[0] == ',' and buf[2] == ',' and (buf[1] == ',' or buf[1] == '.')) // special strings:
      {

        cnt = 0;
        sendout = false;
        if (buf[3] < 14)
        {
          buf[0] = 0;
          buf[1] = 0;
          buf[2] = 0;
          buf[3] = 0;
          st.println(":SYS: TAG:" + hextag + " VCC:" + String(vcc) + " VER:" VERSIONSTRING " UPT" + (broadcast_twice ? ";" : ":") + String(pseudoseconds) + " MEM:"); // keep :SYS: TAG: same across hardware, or edit the bluetooth app to fit
          if (LastWeGot.length() > 0)
          {
            if (recalldots)
              st.print(F("....."));
            st.println(LastWeGot);
          }
        }
        else
        {
#ifdef APPLICATION
          st.print(":SYS:APPCMD: ");
          for (i = 0; i < 19; i++)
          {
            appcommand[i] = buf[i + 3];
            st.print(appcommand[i]);
          }
          st.println();
#endif
        }

      }

    }

    if (buf[0] == 10 or buf[0] == 13) // eliminate stray RFs in case we get a CRLF, and don't send empty packets
    {
      cnt = 0;
      buf[0] = 0;
      buf[1] = 0;
      sendout = false;
    }
  }
}

int LastToAddChk0 = 0;
int LastToAddChk1 = 0;
String lasttag = "xxxx:";
void AddToLastAndPrune(String st) { // warning: may modify st
  LastToAddChk1 = LastToAddChk0;
  LastToAddChk0 = LongChecksum(st);
  if (LastToAddChk0 == LastToAddChk1)
    return;
  bool addenter = true;
#ifdef CONDENSE_TAGS
  if (st.startsWith(lasttag)) // condense tags
  {
    st.remove(0, 5);
    addenter = false;
  }
  else
  {
    lasttag = st.substring(0, 4);
  }
#endif

  if ((LastWeGot.length() + st.length() + 2) > RECALLSIZE)
  {
    LastWeGot.remove(0, st.length());
#ifdef RECALL_STRAY_CHARS
    recalldots = true;
#else
    LastWeGot.remove(0, LastWeGot.indexOf('\n')); // uncomment me for
#endif
  }
  if (addenter)
    LastWeGot = LastWeGot + "\r\n" + st;
  else
    LastWeGot = LastWeGot + "~ " + st;
  LastWeGot.trim();
}

#ifdef SEND_TWICE
int RSSI_0 = RSSI_TRE_HI; //start neutral
int RSSI_1 = RSSI_TRE_HI; //start neutral
int RSSI_2 = RSSI_TRE_HI; //start neutral
#endif
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
void loop() {
  //Serial.println(availableMemory());
  PetTheWatchdog(); // runapplication is in here and triggers every pseudosecond
  SeeIfAnythingOnRadio();
#ifdef REPEAT_UNTIL_ACK
  if (LoRaData.length() >= 1) // if no packet, don't change ack state, just broadcast again.
  {
    got_lora_ack = (LoRaData.equals(message_to_repeat));
  }
  if (!got_lora_ack)
  {
    if ((millis() - last_repeat_time) > REPEAT_DELAY and message_to_repeat.length() > 1)
    {
      LoraSendAndUpdate(message_to_repeat);
    }
  }
#endif

  ReadFromStream(Serial, receivedChars, charcounter, readytosend); // add other streams as needed.
  if (SendSerialIfReady())
  {
    LowPower.idle(SLEEP_30MS, ADC_OFF, TIMER2_OFF, TIMER1_OFF, TIMER0_OFF, SPI_OFF, USART0_OFF, TWI_OFF); // multiply sleep times by 4. safe to turn UART off for a bit since we just sent a message so it's unlikely we will be sending another one so soon
  }

  if (++numloops > 10000)
  {
    vcc = readVcc();
#ifdef VOLTAGECUTOFF
    while (vcc < VOLTAGECUTOFF)
    {
      Serial.print(":SYS:LOWPWR!");
      Serial.println(vcc);
      Serial.flush();
      LowPower.idle(SLEEP_8S, ADC_OFF, TIMER2_OFF, TIMER1_OFF, TIMER0_OFF, SPI_OFF, USART0_OFF, TWI_OFF); // go to sleep and hope that the situation has improved when we wake up; can't really do much else
      vcc = readVcc();
    }
#endif
    numloops = 0;
  }
  else
  {
    mydelay(4); // actually 16
  }
}


#ifdef APPLICATION
void RunApplication()
{
#ifdef BASICPINS
  if (appcommand[0] == 'D' or appcommand[0] == 'd')
  {
    switch (appcommand[1])
    {
      case '2': pinMode(2, OUTPUT); digitalWrite(2, appcommand[2] == '2'); break;
      case '3': pinMode(3, OUTPUT); digitalWrite(3, appcommand[2] == '3'); break;
      case '4': pinMode(4, OUTPUT); digitalWrite(4, appcommand[2] == '4'); break;
      case '5': pinMode(5, OUTPUT); digitalWrite(5, appcommand[2] == '5'); break;
      case  '6': pinMode(6, OUTPUT); digitalWrite(6, appcommand[2] == '6'); break;
      case  '8': pinMode(8, OUTPUT); digitalWrite(8, appcommand[2] == '8'); break;
      case  '9': pinMode(9, OUTPUT); digitalWrite(9, appcommand[2] == '9'); break;
      default: break;
    }
    appcommand[0]=0;
  }
  if (appcommand[0] == 'A' or appcommand[0] == 'a')
  {
    Serial.print(":SYS:APP:A");
    switch (appcommand[1])
    {
      case '1': Serial.print("1:"); Serial.println(analogRead(A1)); break;
      case '2': Serial.print("2:"); Serial.println(analogRead(A2)); break;
      case '3': Serial.print("3:"); Serial.println(analogRead(A3)); break;
      case '6': Serial.print("6:"); Serial.println(analogRead(A5)); break;
      case '7': Serial.print("7:"); Serial.println(analogRead(A6)); break;
      default: break;
    }
//    appcommand[0]=0; // keep reading every second until we get a stop (invalid command), actually
  }
#endif



#ifdef AEROPONY


  unsigned static long AEROSOLPWM = 1023; // 512 for 113KHz pwm to send to piezos via irlz44, 1023 for on/off and use external signal generator
  // needs water alarm
  // needs humidity sensor

  unsigned static long dayseconds = 12000;// 1 to 86400
  unsigned static long lights_OFF_time = 79200; // 2200
  unsigned static long lights_ON_time = 21600; // 0600

  unsigned static long ultrasound_ON_gap = 50;
  unsigned static long ultrasound_OFF_gap = 10;
  unsigned static long ultrasound_time_for = 0;
  static bool is_ultrasound_ON = false;

  unsigned static long pump_ON_gap = 10;
  unsigned static long pump_OFF_gap = 50;
  unsigned static long pump_time_for = 0;
  static bool is_pump_ON = false;

  static bool turn_lights_ON = false;
  static bool is_aero_init = false;
  static bool water_low = false;

  // generates 111KHz for ultrasound
  if (is_aero_init == false)
  {
    Timer1.initialize(9);              // initialize timer1, and set a 9 usec period for generating 113KHz
    pinMode(9, OUTPUT);
    Timer1.pwm(9, AEROSOLPWM);         // setup pwm on pin 9, 50% duty cycle. set to 0 for off.
    pinMode(2, OUTPUT);                // lights
    pinMode(3, OUTPUT);                // pump
    pinMode(4, OUTPUT);                // water low alarm led, also blink led
    digitalWrite(2, HIGH);
    digitalWrite(3, HIGH);
    digitalWrite(4, LOW);
    is_aero_init = true;
    is_ultrasound_ON = true;
    is_pump_ON = true;
    Serial.println("SYS:APP_INIT");
    return;
  }

  digitalWrite(4, HIGH); // blink led

  if (UTC_Seconds > 0)
  {
    dayseconds = UTC_Seconds;
  }

  // do timing, if it has been initialized
  if (dayseconds > 0)
  {
    dayseconds++;

    if (dayseconds > 90000)
    {
      dayseconds = 0;
      return;
    }

    if (dayseconds > 86400)
    {
      dayseconds = 1;
    }


    // control lights
    turn_lights_ON = ((dayseconds > lights_ON_time) && (dayseconds < lights_OFF_time));
    if (lights_ON_time < lights_OFF_time)
    {
      //      Serial.print("SYS:LIGHTS:");
      //      Serial.println(turn_lights_ON + '0');
      digitalWrite(2, turn_lights_ON);
    }
    else
    {
      //      Serial.print("SYS:LIGHTS:");
      //      Serial.println((!turn_lights_ON) + '0');
      digitalWrite(2, !turn_lights_ON);
    }

    // control ultrasound
    if (is_ultrasound_ON)
    {
      if (++ultrasound_time_for > ultrasound_ON_gap)
      {
        Serial.println("SYS:ultrasound_OFF");
        Timer1.pwm(9, 0);
        digitalWrite(3, LOW);
        ultrasound_time_for = 0;
        is_ultrasound_ON = false;
      }
    }
    else
    {
      if (++ultrasound_time_for > ultrasound_OFF_gap)
      {
        Serial.println("SYS:ultrasound_ON");
        Timer1.pwm(9, AEROSOLPWM);
        digitalWrite(3, HIGH);
        ultrasound_time_for = 0;
        is_ultrasound_ON = true;
      }
    }

    // control pump
    if (is_pump_ON)
    {
      if (++pump_time_for > pump_ON_gap)
      {
        Serial.println("SYS:pump_OFF");
        digitalWrite(3, LOW);
        pump_time_for = 0;
        is_pump_ON = false;
      }
    }
    else
    {
      if (++pump_time_for > pump_OFF_gap)
      {
        Serial.println("SYS:pump_ON");
        digitalWrite(3, HIGH);
        pump_time_for = 0;
        is_pump_ON = true;
      }
    }
  }

  // very simple command parser: (lettter)(num)(num)(num)(num)(num)(!)
  if (appcommand[0] > 0 and appcommand[1] > 47 and appcommand[1] < 58 and appcommand[6] == '!')
  {

    if (appcommand[0] == 'h' or appcommand[0] == 'H') // set hour
    {
      Serial.print(F(":APP:TIME:"));
      unsigned int tempme;
      tempme =           (appcommand[1] - '0') * 0 + // display fix type
                         (appcommand[2] - '0') * 36000 +
                         (appcommand[3] - '0') * 3600 +
                         (appcommand[4] - '0') * 600 +
                         (appcommand[5] - '0') * 60 + 1;
      if (tempme > 86400)
      {
        tempme = dayseconds;
      }
      else
      {
        dayseconds = tempme;
      }
      Serial.println(tempme);
      appcommand[0] = 0;
    }

    if (appcommand[0] == 't' or appcommand[0] == 'T') // set time
    {
      Serial.print(F(":APP:TIME:"));
      dayseconds = parseparameter(dayseconds);
      if (dayseconds > 86400)
        dayseconds = 0;
    }
    if (appcommand[0] == 'L' or appcommand[0] == 'l') // set light
    {
      Serial.print(F(":APP:LIGHT:"));
      lights_ON_time = parseparameter(lights_ON_time);
    }
    if (appcommand[0] == 'D' or appcommand[0] == 'd') // set dark
    {
      Serial.print(F(":APP:DARK:"));
      lights_OFF_time = parseparameter(lights_OFF_time);
    }

    if (appcommand[0] == 'U' or appcommand[0] == 'u') // set ultrasound
    {
      Serial.print(F(":APP:ULTRASOUND:"));
      ultrasound_ON_gap = parseparameter(ultrasound_ON_gap);
    }
    if (appcommand[0] == 'Q' or appcommand[0] == 'q') // set quiet
    {
      Serial.print(F(":APP:QUIET:"));
      ultrasound_OFF_gap = parseparameter(ultrasound_OFF_gap);
    }

    if (appcommand[0] == 'P' or appcommand[0] == 'P') // set quiet
    {
      Serial.print(F(":APP:PUMP:"));
      pump_ON_gap = parseparameter(pump_ON_gap);
    }
    if (appcommand[0] == 'N' or appcommand[0] == 'n') // set quiet
    {
      Serial.print(F(":APP:NOPUMP:"));
      pump_OFF_gap = parseparameter(pump_OFF_gap);
    }

    for (i = 0; i < 16; i++)
    {
      appcommand[i] = 0;
    }
  }
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

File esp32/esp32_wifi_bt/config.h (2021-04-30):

// hardware platform types; pick one and only one. Default is LORA32 V2. If yours is not in here, you'll have to adjust stuff manually. They will override some settings (for example, selecting TTGO will turn off the display since there isn't one)
#define LORA32V2 // Heltec LORA32 V2 (White board). More progmem, screen, no gps, battery ADC. This is the default and development will mostly happen on this board.  Start developing here if you have the esp32 with more progmem
//#define TBEAM // TTGO T-Beam (Black board with gps). Less progmem, no screen, gps, no battery ADC.
//#define LORA32V1 // Heltec clone (Black board) (TTGO LoRa OLed V1). Less progmem, screen, no gps, no battery ADC. Start developing here if you have the esp32 with less progmem
// If none of these are defined you'll end up with a minimal feature set. To change these settings, use pinout.h

// Physical radio band. Choosing the wrong range WILL DAMAGE YOUR RADIO MODULE. Currently set up to stay a little away from the main LoRa and LoRaWAN radio ranges out of politeness.
//4331E5 for worldwide (restrictions apply)

//8661E5 for Europe
//9151E5 for North America
//4331E5 for Asia
#define BAND 9151E5  

// compile time setup stuff. if you aren't sure what these do, leave them alone.


// the default is that these four are commented out. This gives you the standard wifi access point setup.
// switching between wifi and bluetooth is done at startup with the normal mode, not here; push the button immediately after a reset.
// if more than one is uncommented, lowest line wins.

// The first mode saves power but makes the AP invisible 45 seconds out of every minute.
//#define MODEFLIP 15000 // minimum suggested: 12000. powershare mode operates the pylon on full AP for this many milliseconds every minute, and as a repeater the rest of the time. It is exclusive with the other options. The mode flip will pause if there are clients connected or if the battery is full enough.

// The last three modes use more power than standard mode!
//#define BT_ENABLE_FOR_AP // Uncomment this to also enable Bluetooth when the pylon is running as an access point. THIS WILL EAT UP A LOT OF POWER! Only enable if you're using a big battery and a big panel, or have line power.
//#define WIFI_IS_CLIENT // Uncomment this to enable use as a gateway. Bluetooth will be on. Note that gateway mode must be configured manually and will need an open port on the router. If you don't know what this does, leave it alone!
//#define WIFI_IS_HYBRID // Uncomment this to enable use as BOTH a gateway and an AP. Bluetooth will be on. Performance will be slower than either. Note that this won't allow people to get on the internet through the AP, so it's ideal if you want to let people use cellsol without a password, but not use the internet.

//#define REPEATER_ONLY // Uncomment this to bypass everything else and runs as repeater (and serial) only. useful if we are out of arduinos. not useful otherwise.

//#define NODISPLAY // display is either absent or should be kept off at all times. Saves some power, naturally.

#define COMMUNITY_MEMORY_SIZE 50 // old lines to keep (other than the last 10)

#define SEND_TWICE // if defined, allow sending a packet twice after a pseudorandom delay, in case the first one got lost
#define RSSI_TRE_LO -120 // if sendtwice is defined, below this (for the last 4 received packets), turn on sendtwice
#define RSSI_TRE_HI -100 // if sendtwice is defined, above this (for the last 4 received packets), turn off sendtwice
#define REBROADCAST_DISASTER_RADIO_PACKETS // if this is defined, we will rebroadcast Disaster Radio packets, for interoperability.
//#define DISPLAY_DISASTER_RADIO_PACKETS // if this is defined, we will display Disaster Radio packets, for interoperability.

/**
   WEBPAGE CONFIG
*/
#define TUTORIALSTRINGS // On first activation after a poweroff/reset, should we display a mini help on the screen?

#define PROVIDE_APK // make bluetooth terminal apk available?
#define PROVIDE_CAT_PICTURE // load cat picture as an example of embedded file?
#define PROVIDE_SOURCE_CODE // embed source zip in source for the glory of recursion?
#define SERVE_FAQ_PAGE  // if undefined, do not add help page
#define REFRESH_CHAT_EVERY 3 // seconds

#define REQUIRE_TAG_FOR_REBROADCAST // if defined, require xxxx: tag for rebroadcast.
//#define REQUIRE_TAG_FOR_REBROADCAST_STRICT // on top of that, the first four characters must be hex digits.
#define BAD_CHARACTERS_MAX_DIVIDER 10 // 1/x of bad characters before we discard the string
//#define SHOW_RSSI // if enabled, show RSSI for wireless packets coming in.

#define TAG_END_SYMBOL ':'

/**
   NETWORK CONFIGURATION
*/
//This is the root name for the AP. It will be used when in AP mode.
#define SSIDROOT "CellSol "
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

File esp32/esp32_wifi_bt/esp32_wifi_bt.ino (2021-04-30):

/*********
  Cellular-Solar (CellSol) is a simple interconnect between lora, wifi and com port(s). It is intended to be used for infrastructure-independent comms during or after a disaster.
  (c) 2020 Robots Everywhere, LLC until we are ready to release it under copyleft
  Written by Riley August (HTML/CSS/DHCP/Optimizations), and M K Borri (other). Thanks to Rui Santos for the tutorials. Thanks to Jerry Jenkins for the inspiration. Thanks to Lisa Rein for initiating the project.  Thanks to Robots Everywhere for infrastructure support https://www.robots-everywhere.com
  Originally produced as part of the Aaron Swartz Day project https://www.aaronswartzday.org
  Distributed independently https://www.f3.to/cellsol

  This file is used for esp32-based boards (Lora32, TTGO T-Beam, etc.)
*********/

// Firmware version.
#define VERSIONSTRING "0.32"

#include "config.h" // Please make config changes in config.h and pinout.h instead of here!

#ifdef PROVIDE_APK
#include "btt/btt.h"
#endif

#ifdef PROVIDE_CAT_PICTURE
#include "btt/cat.h"
#endif

#ifdef PROVIDE_SOURCE_CODE
#include "btt/src.h"
#endif


#define uS_TO_S_FACTOR 1000000  /* Conversion factor for micro seconds to seconds. Do not change this. Seriously. */

// Load Wi-Fi library
#include <WiFi.h>
#include "time.h"
// taken from genericwifi.h -1dbm to 19.5dbm
#ifdef WIFI_POWER_LEVEL
const wifi_power_t wifilevels[] = {WIFI_POWER_MINUS_1dBm, WIFI_POWER_2dBm, WIFI_POWER_5dBm, WIFI_POWER_7dBm, WIFI_POWER_8_5dBm, WIFI_POWER_11dBm, WIFI_POWER_13dBm, WIFI_POWER_15dBm, WIFI_POWER_17dBm, WIFI_POWER_18_5dBm, WIFI_POWER_19dBm, WIFI_POWER_19_5dBm}; // 0~11
#endif

#include <DNSServer.h>
const byte DNS_PORT = 53;
#include <esp_wifi.h>
#include "BluetoothSerial.h"

//Libraries for LoRa
#include <SPI.h>
#include <LoRa.h>
#include <IRCClient.h>

// watchdog
#include <esp_task_wdt.h>
#define WDT_TIMEOUT 4 // in seconds

#include "esp32-hal-cpu.h"
#define CLKFREQ_HI 240 // megahertz when going as fast as possible
#define CLKFREQ 80 // megahertz when in full mode
#define CLKFREQ_LOW 20 // megahertz when in repeater mode; can't go any lower, annoyingly

#include "pinout.h" // LORA32 Pinout by default, change this file to change the pinout!


#ifdef MINDISPLAY
#define NODISPLAY
#include <Wire.h>
//#include "ACROBOTIC_SSD1306_minimal/ACROBOTIC_SSD1306_minimal.h" // pared down SS1306 driver that only has the 5x7 font
#include "ACROBOTIC_SSD1306_minimal/ACROBOTIC_SSD1306_minimal.cpp" // pared down SS1306 driver that only has the 5x7 font
#endif

#ifndef NODISPLAY
//Libraries for OLED Display
#include <Wire.h>
#include <Adafruit_GFX.h>
#include <Adafruit_SSD1306.h>
#endif

// LORA32 setup variables
static bool lowpowerstart = false;
static uint64_t chipid; // chip id stuff = ESP.getEfuseMac();
static uint16_t uptwo; // chip id stuff = (uint16_t)(chipid >> 32);
static uint32_t dnfor; // chip id stuff  = (uint32_t)(chipid);


// Web constants for text align, used for website display
#define TEXT_ALIGN_STRING_A "center"
#define TEXT_ALIGN_STRING_B "justify"
String TEXT_ALIGN_STRING = TEXT_ALIGN_STRING_A;
static RTC_NOINIT_ATTR bool centertext = true;// if this, center, otherwise, justify


// Wireless UART Configuration
long LastReconnect = 0;
int currbatterylevel = 0;

#define UART_BAUD_RATE 9600
String ssid = SSIDROOT;
String tempstring = ""; // internal function use only

bool wifimode = true; // bluetooth or wifi

// serial on/off
boolean enablecomport = false; // set to false for a solderless fix for UART buffer crosstalk hardware issue

// Set web server port number to 80
WiFiServer server(80);
DNSServer dnsServer;
WiFiClient wificlient1;

// WEB SERVICE CONFIGURATION - What files do we want to serve?
#ifdef PROVIDE_APK
extern const long int btt_apk_size;
extern const unsigned char btt_apk[];
#endif
#ifdef PROVIDE_CAT_PICTURE
extern const long int cat_jpg_size;
extern const unsigned char cat_jpg[];
#endif
#ifdef PROVIDE_SOURCE_CODE
extern const long int src_zip_size;
extern const unsigned char src_zip[];
#endif

// BATTERY POWER CONFIGURATION
static RTC_NOINIT_ATTR int lastbatterylevel = 0; // try to save battery levels between runs
int batt_delta;
int battimeout = 0;
bool low_batt_announce = false;

// SERIAL and IP CONFIGURATION
int lploops = LPLOOP_BLINK - 10; // give me a blink early so i know we're alive
bool has_lora_been_initialized = false;
bool has_serial_been_initialized = false;
bool has_bluetooth_been_initialized = false;
bool has_wifi_been_initialized = false;
bool has_display_been_initialized = false;

// USER TAG CONFIGURATION
String hextag  = "XXXX"; // usually the last two IP octets; gives pseudonimity to sender
String lasttagimade = "XXXX"; // last one we made for use in checking

// Temp bytes for IP addresses
byte derpme = 0; // third number of ip address
byte spare_id_nibble = 0; // upper nibble; lower nibble always 0


//packet counter
int txcounter = 0;
int rxcounter = 0;
byte charcounter = 0;
boolean readytosend = false;
byte charcounte2 = 0;
boolean readytosen2 = false;

// display flags
boolean dodisplay = false;
boolean dodisplaybuf = false;
boolean displayexists = false;
bool displayenabled = true;

#ifdef REPEAT_UNTIL_ACK  
boolean got_lora_ack = false;
long last_repeat_time = millis();
String message_to_repeat = "";
#endif


#ifndef NODISPLAY
Adafruit_SSD1306 display(SCREEN_WIDTH, SCREEN_HEIGHT, &Wire, OLED_RST);
#endif


long disptimeout = 0;
bool display_on_ping = false;
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

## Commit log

2020-10-28 Initial Commit
    Added 0.22 w/helpfile build
    [2000 most common english words in order of use.csv, 2000.csv, 2704.csv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]
2020-11-01 Fixed Critical Issues
    Fixed XSS Injection Vulnerability (basic) - added test plan
    Fixed display of DCHP IP addresses being missing
    [esp32_wifi_bt.ino]
2020-11-03 Version 0.24
    * Added support for the RFM95W radio
    * Optimized Riley's injection fix
    * Added FAQ
    [lora32_case_edited.skp]
2020-11-10 More Documentation
    Added assembly instructions for ESP32 and other things.
2020-11-12 Cases WIP and Website Done
    Just need github public and cases done we're ready to yeet it. Need reviews and merge!
    [lora32_case_edited.skp, lora32_case_edited.stl, lora32_pylon_bigcase_bottom.skp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]
2020-11-12 Cases Done
    Cases are done
    [lora32_pylon_bigcase_top_buttons.skp, lora32_pylon_bigcase_top_buttons.stl, lora32_pylon_smallcase_bottom_repaired.3mf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]
2020-11-13 Cases are Done
    Will merge manually if nobody reviews by end of day.
    [lora32_pylon_bigcase_bottom.skp, lora32_pylon_bigcase_bottom.stl, lora32_pylon_bigcase_top_buttons.skp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]
2020-11-18 Case Fixes
    Minor case fixes and created nano case draft
    [lora32_pylon_bigcase_bottom.skp, lora32_pylon_bigcase_top_buttons.skp, lora32_pylon_bigcase_top_buttons.stl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]
2020-11-19 Beta Release
    Last of the website stuff, we're officially in beta with version 0.24
    [nano_antennaguide.stl, nanopylon_box_bottom.skp, nanopylon_box_bottom_usbport.stl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]
2020-11-20 Manifold Issues on Antenna Guide + Text Edits
    [nano_antennaguide.stl, nanopylon_box_bottom.skp, nanopylon_box_top_antennaguide.stl]
2020-11-20 Moved Nano Case Files and Added Dipole Img
    [arduino lora repeater antenna over tinfoil under.stl, nano_antennaguide.stl, nanopylon_all.skp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]
2020-11-20 Added case design links, removed old antenna guide
    [arduino lora repeater antenna over tinfoil under.stl]
2020-11-26 ARCHIVE COMMIT - Incomplete Code Cleanup
    This is a broken wreck of a code cleanup that is likely to be a dead end branch. Committing it for archive.
    [config.h, esp32_wifi_bt.ino, pinout.h]
2020-11-26 Revert "ARCHIVE COMMIT - Incomplete Code Cleanup"
    This reverts commit 0cfa5c5b65f68a8e7a7b82142163396feb947e8b.
    [config.h, esp32_wifi_bt.ino, pinout.h]
2020-11-26 Revert "ARCHIVE Commit - DOES NOT COMPILE"
    This reverts commit 533f979552aab254c7f78a9943e11e9874022d30.
    [config.h, esp32_wifi_bt.ino]
2020-11-26 Code Cleanup
    Cleaned up and commented a large amount of code; moved many variables and methods to make it read and flow better.
2020-11-27 Added photos and directions for using the antenna cutter.
2020-11-30 HOTFIX 0.25 Fixed enter key on form issue
    Enter key now works on form again. Hotfix.
    [esp32_wifi_bt.ino]
2020-12-01 0.25 with irc
    [lora32_case_edited.skp, lora32_case_edited.stl, lora32_pylon_bigcase_bottom.skp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]
2020-12-03 fixed wrong order in header; added irc channel topic
    I think this is the last thing lol srs for realz?
    [config.h, esp32_wifi_bt.ino]
2020-12-03 IRC topic is now set correctly
    IRC topic is now set correctly (it was eating spaces)
    Forward prefix can now be used in messages (removed replace)
    [config.h, esp32_wifi_bt.ino]
2020-12-03 Added radio-irc-radio functionality
    pylons can now forward each other using irc relays in the middle.
2020-12-03 version 0.30
    added hex tag masks for arduino and feather; post irc test
2020-12-07 make the 7z go away
    make the 7z go away
    [arduino lora repeater antenna over tinfoil under.stl, lora32_case_edited.skp, lora32_case_edited.stl]
2021-01-10 0.32
    * adds support for Disaster Radio packets
    * adds support for older Lora32 boards
    * remove T-Beam GPS spam bug
    [bsfrance_usbserial.ino, config.h, esp32_wifi_bt.ino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]
2021-01-13 0.32a
    * Fixed race condition with the new minimal display library
    * Preparing to move to said minimal display library as default
    [ACROBOTIC_SSD1306_minimal.cpp, config.h, esp32_wifi_bt.ino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]
2021-01-14 0.32d
    arduino can now put itself to sleep in case of undervoltage
2021-04-28 Update _index.md
    Documentation hotfix for assembly and firmware on arduino pylons.
2021-04-30 Fixed It
    This works on the endpoint pylon, need to add it to the repeater.
    [esp32_wifi_bt.ino]
2021-07-09 Added schematic supporting the JDY-31 bluetooth module for permanent mount, also adds BT power jumper.
2021-07-17 Added vertical dipole antenna PCB design.
2021-08-17 cleaned up possible issue with a328 clone chips that don't have an ID added upon the dictionary compression thing
    [nano_one_serial_port.ino]
2022-02-18 antenna update
2023-11-09 * updated dictionary compression * fixed pin numbers if basicpins app is running on arduino nano
    [nano_one_serial_port_app.ino]
2023-11-09 added "output simple string with hextag" function in case we ever need it
2024-04-25 added shorter antenna and frisbee build
2025-11-17 added rssi test and collinear antennas
2026-11-08 * esp32 now has settings for base adress * downloadable source from esp32 website is now up to date * added compatibility library for old esp32 modules
